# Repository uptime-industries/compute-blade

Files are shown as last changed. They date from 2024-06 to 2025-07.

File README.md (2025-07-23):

# Compute Blade

A On-Premise Cluster Environment

Feature rich, enterprise-level, carrier board for the Raspberry Pi Compute Module 4 (+ compatible alternatives). From Homelabs to advanced AI clusters at scale: Simplifying and automating the development and management of on-premise cluster environments is at the heart of what we do. Our solutions are designed to streamline complex processes, turning what was once a daunting task into a manageable and efficient experience.

## Links

- [Website](https://computeblade.com/)
- [Documentation](https://docs.computeblade.com)
- [Discord Community](https://discord.com/invite/uptime-industries-952334175501946902)

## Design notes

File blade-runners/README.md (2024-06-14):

# Blade Runners
Offial enclosure for the [Compute Blade](https://computeblade.com/). Offing flex able options to fit a number of uses cases. With three options

## Twin
Twin Enclosure allows two Compute Blades and one Fan Unit to be installed. It is ideal for desktop and devlopment

## Home
Home enclosure is our recomened enclosure for Homelab and cluster devlopment. Caplible of holding four Compute Blades and two Fan Units, it is ideal for quick spinning up a deveolpment envierment

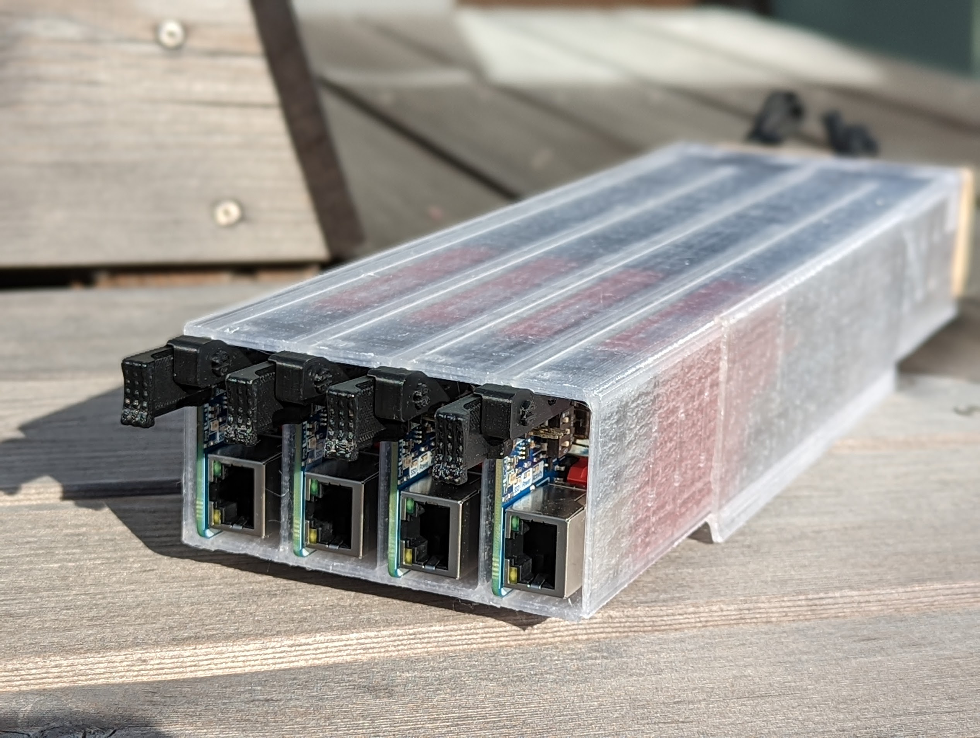
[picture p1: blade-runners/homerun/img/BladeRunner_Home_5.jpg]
Blade Runner Home


## 19-Inch
The 19-Inch enclosure is for enterprise scale. Can be equipt with twenty Compute Blades and ten Fan Units. Offering high desity compute in a Standered 1U of rack space.

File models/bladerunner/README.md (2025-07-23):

# BladeRunner™️
Offial enclosure for the [Compute Blade](https://computeblade.com/). Offing flex able options to fit a number of uses cases. With three options

## 2-Node
2-Node Enclosure allows two Compute Blades and one Fan Unit to be installed. It is ideal for desktop and development

## 4-Node
4-Node enclosure is our recommend enclosure for Homelab and cluster development. Can house four Compute Blades and two Fan Units, it is ideal for quick spinning up a development environment

BladeRunner™️ Home

## 19-Inch
The 19-Inch enclosure is for enterprise scale. Can be equipped with twenty Compute Blades and ten Fan Units. Offering high density compute in a Standard 1U of rack space.

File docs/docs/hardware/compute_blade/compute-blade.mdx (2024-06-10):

---
sidebar_position: 1
---
import Tabs from '@theme/Tabs';
import TabItem from '@theme/TabItem';

# Compute Blade

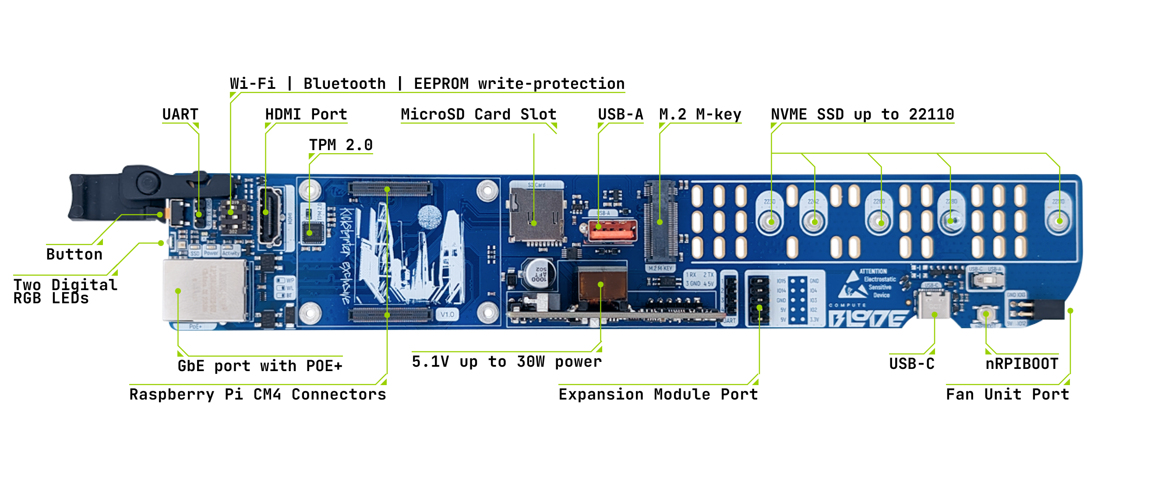
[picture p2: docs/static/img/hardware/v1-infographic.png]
Infographic


---
## Compute Blade Models
The Compute Blade comes in three haredware teirs.

| Feature |  Basic | TPM  |  Dev |
| :--- | :---: | :----: | :----: |
| CM4 Port | ✅ | ✅ | ✅ |
| M.2 Slot M Key up to 2210 | ✅ | ✅ | ✅ |
| Gigabit Ethernet | ✅ | ✅ | ✅ |
| PoE++ support | ✅ | ✅ | ✅ |
| UART | ✅ | ✅ | ✅ |
| Programable Button | ✅ | ✅ | ✅ |
| Programable LEDs | ✅ | ✅ | ✅ |
| USB-A 2.0 | ❌ | ✅ | ✅ |
| TPM 2.0 | ❌ | ✅ | ✅ |
| HDMI | ❌ | ❌ | ✅ |
| USB-C for Flashing CM4 | ❌ | ❌ | ✅ |
| MicroSD Card | ❌ | ❌ | ✅ |
| Wi-Fi | Locked | Locked | Switchable |
| Bluetooth | Locked | Locked | Switchable |
| Write Protection | Locked | Locked | Switchable |

## Block Scheme
This is the top part of the Raspberry Pi's GPIO connector. On the Compute Blade, PIN 1 corresponds to 3.3V, while on the Raspberry Pi's standard connector, it is labeled as 3.3V PWR.
<Tabs>
    <TabItem value="basic" label="Basic" >
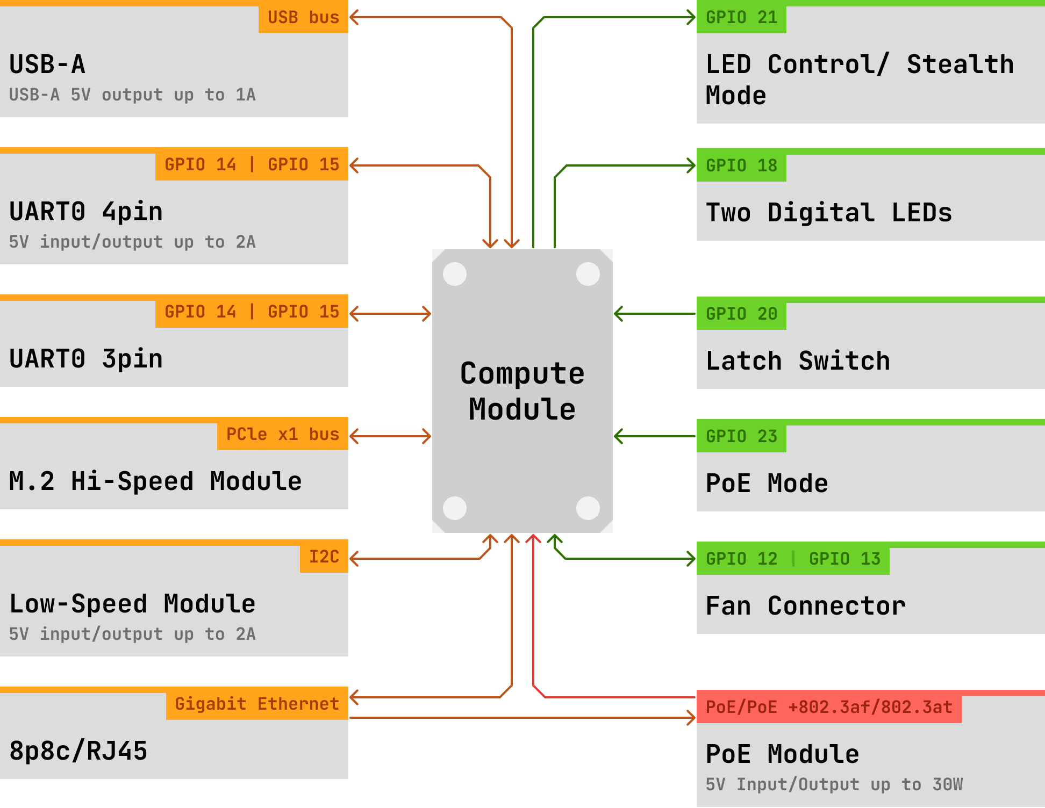
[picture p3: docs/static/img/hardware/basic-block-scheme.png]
Basic Block Scheme
    
    </TabItem>
    <TabItem value="tpm" label="TPM">
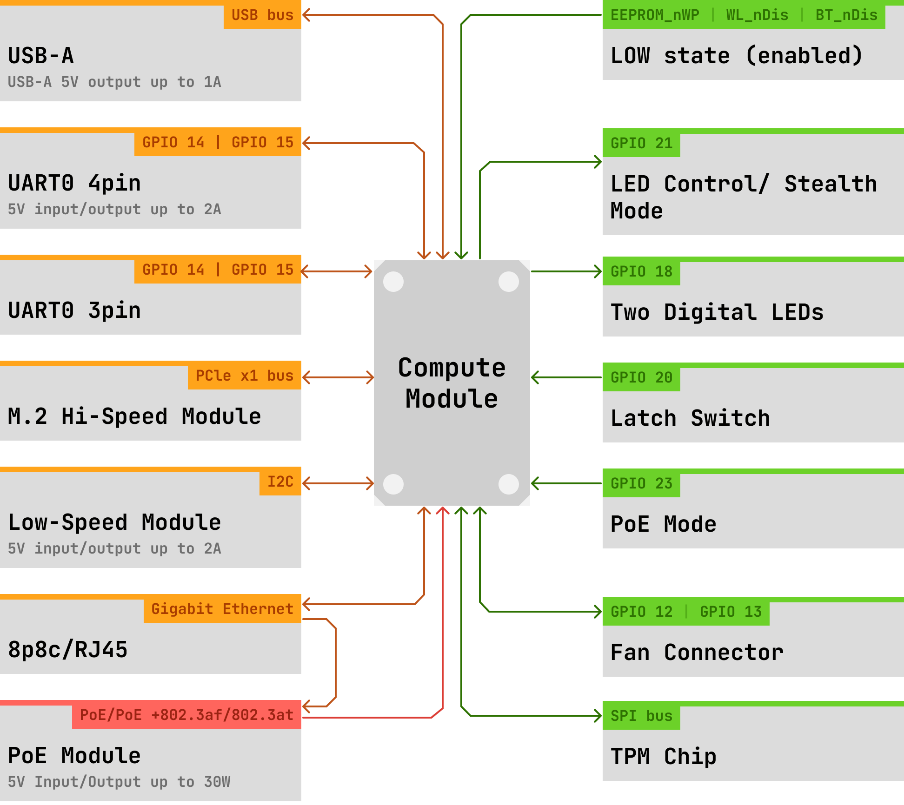
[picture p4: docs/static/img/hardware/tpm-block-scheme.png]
TPM Block Scheme
    
    </TabItem>
    <TabItem value="dev" label="Dev">
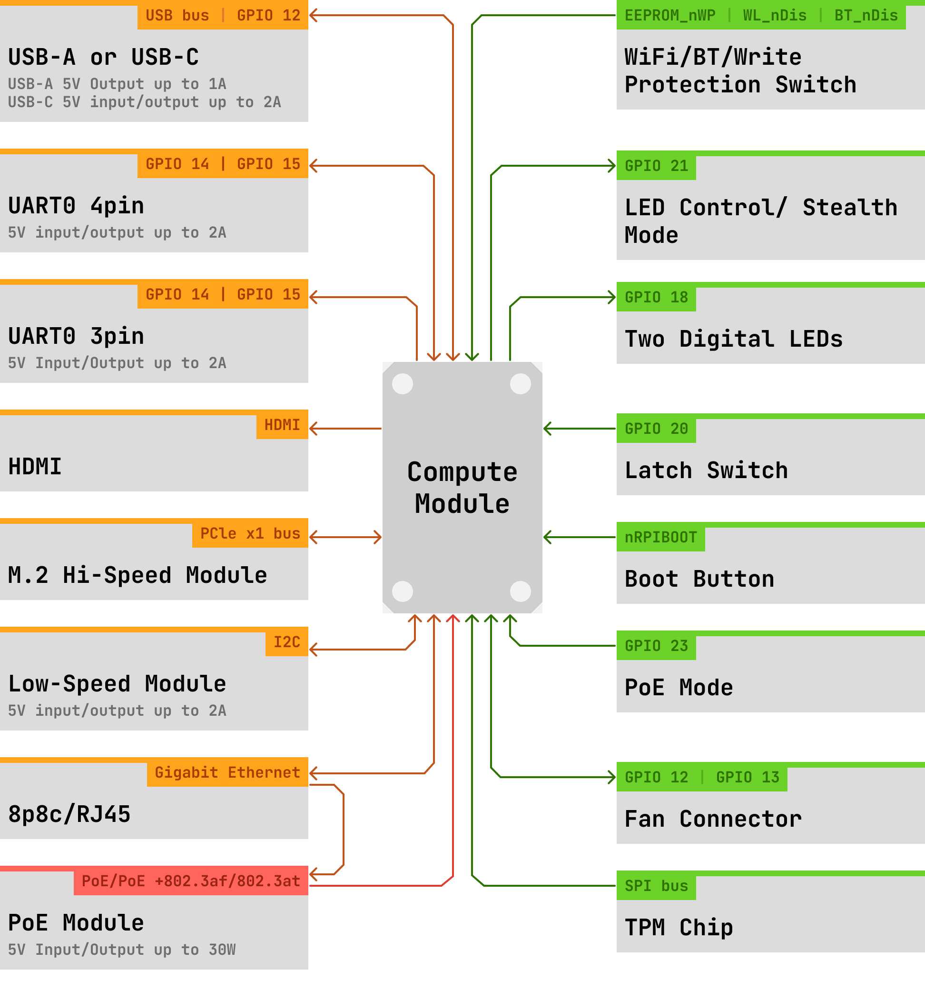
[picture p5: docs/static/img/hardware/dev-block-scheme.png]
Dev Block Scheme
    
    </TabItem>
</Tabs>

## Mechanical
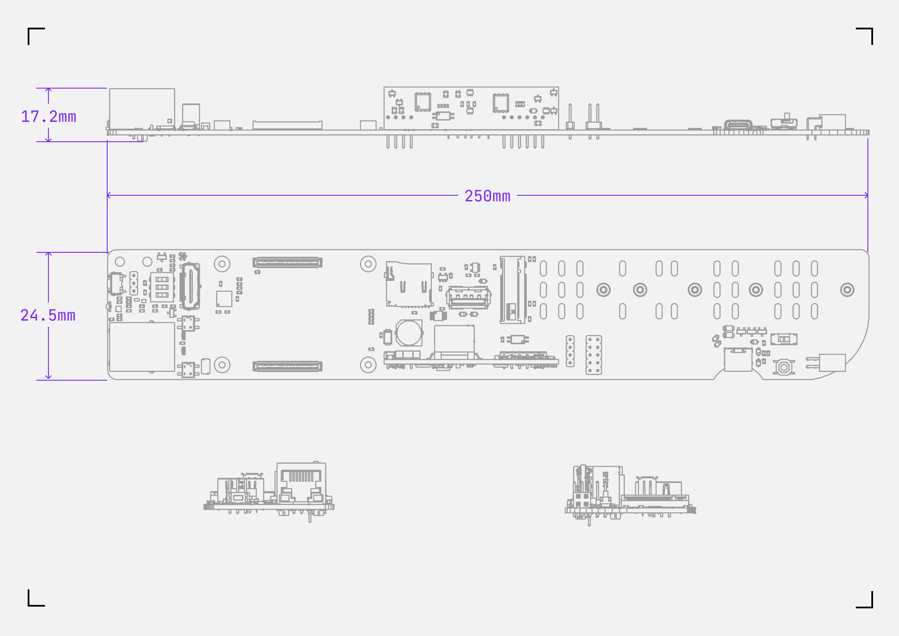
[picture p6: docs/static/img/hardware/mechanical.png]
mechanical

## DIP Switchs
:::danger
Only change switch positions when the Blade is unpluged from power
:::

| Switchs | Left | Right  |
| :--- | :---: | :---: |
| 1 - Write Protection | Disabled | Enabled  |
| 2 - Wi-Fi | Enabled  | Disabled |
| 3 - Bluetooth | Enabled  | Disabled |

:::warning
To enable write protection, changes are required to the bootloader. Follow the steps in the official [documentation](https://www.raspberrypi.com/documentation/computers/compute-module.html#cm4bootloader).
:::
---
# USB-C USB-A Switch
The compute module can only operate one USB port at a time. There is a switch to enable which port you would like to utilize.

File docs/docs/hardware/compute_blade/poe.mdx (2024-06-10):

import Tabs from '@theme/Tabs';
import TabItem from '@theme/TabItem';

# Power over Ethernet

The Compute Blade features a Gigabit Ethernet port that supports IEEE 802.3af (PoE), 802.3at (PoE+), and 802.3bt (PoE++).

## Power Consumption

Power consumption will vary based on load, accessories connected, the power requirements of any devices installed in the M.2 slot.
Durring Testing a Compute Blade with a CM4 overlocked to 2GHz and a consumer NVMe SSD under load consumes ~7W. Normal operation may range from 3W to 17W.

## PoE+ Indicator
The PoE+ Indicator can be used to monitor power supply failures or limit RaspberryPi overclocking, when power is provided via 802.3af only. There is an LED on the Blade with a `+` label indicating the PoE+ power state. Alongside, `GPIO23` can be used to identify the power state.

| LED Color | Description | GPIO 23  | Power |
|---|---|---|---|
| Red | 5 Volt present (PoE or USB-C or 5v direct) | **HIGH** | 12W |
| Orange (Red+Green) | PoE+ (802.3at or 802.3bt) present | **LOW**  | 25W (RC2: 22W) |

### Accessing the PoE+ Status in Software
The `GPIO23` indicates the PoE+ state, these script can e.g. used to detect the status.
<Tabs groupId='code-lang'>
    <TabItem value="python" label="Python" default>

    ```py
    import RPi.GPIO as GPIO
    import time

    POE_INDICATOR_GPIO = 23

    GPIO.setmode(GPIO.BCM)
    GPIO.setup(POE_INDICATOR_GPIO, GPIO.IN, pull_up_down=GPIO.PUD_UP) # PoE indicator

    try:
        button_state = GPIO.input(POE_INDICATOR_GPIO)
        if button_state == False:
            print("Powersource: 802.3at or 802.3bt")
        else:
            print("Powersource: 802.3af or USB-C")
    except:
        GPIO.cleanup()
    ```
    </TabItem>
    <TabItem value="c" label="C" >
    ```c
    #include <stdio.h>
#include <wiringPi.h>

// Define the GPIO pin number for the PoE indicator
#define POE_INDICATOR_GPIO 23

int main(void) {
    // Initialize the wiringPi library
    if (wiringPiSetupGpio() == -1) {
        printf("wiringPi setup failed\n");
        return 1;
    }

    // Set the GPIO pin mode to input
    pinMode(POE_INDICATOR_GPIO, INPUT);

    // Read the state of the GPIO pin
    int poeIndicatorState = digitalRead(POE_INDICATOR_GPIO);

    // Check if the pin is active (assuming active-high logic)
    if (poeIndicatorState == HIGH) {
        printf("Powersource: 802.3af or USB-C\n");
    } else {
        printf("Powersource: 802.3at\n");
    }

    return 0;
}
    ```
    </TabItem>
</Tabs>

## PoE Modules
Different Compute Blade revisions use different PoE modules. See the table below

| Version | PoE Module | Volts | Watts (Peak) | PoE Support | Classification |
|:---|:---|:---|:---|:---|:---|
| v1.0 | [Silvertel Ag5405](https://silvertel.com/ag5400/) | 5V | 25.5W (30W)  | IEEE 802.3af, 802.3at, 802.3bt | Type 2, Class 4 |
| RC2 | [Silvertel Ag5305](https://silvertel.com/ag5300/) | 5V | 20W (22W) | IEEE 802.3af, 802.3at | Type 2, Class 4 |

## Switch Recommendation
A switch that can Supply IEEE 802.3at (PoE+) is recommended as IEEE 802.3af (PoE) may not provide sufficient power for all work loads.

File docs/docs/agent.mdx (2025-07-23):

# Blade Agent

:::warning
    This software is currently in beta, and both configurations and APIs may undergo breaking changes. It is not yet 100% feature complete, but it functions as intended.
:::
The [`computeblade-agent`](https://github.com/Uptime-Lab/computeblade-agent) serves as an operating system agent interfacing with ComputeBlade hardware.
It takes charge of fan speed, LEDs, and manages common events, such as identifying or locating an individual blade in a server rack.
Additionally, it exposes hardware and agent-related metrics on a Prometheus endpoint.

## Installation of Agent

The following commands download and then run our automated installation [script](https://github.com/uptime-lab/compute-blade-agent/blob/main/hack/autoinstall.sh)
```bash
sudo apt update
sudo apt upgrade
curl -L -o /tmp/computeblade-agent-installer.sh https://raw.githubusercontent.com/Uptime-Lab/computeblade-agent/main/hack/autoinstall.sh
chmod +x /tmp/computeblade-agent-installer.sh
/tmp/computeblade-agent-installer.sh
```
## Components
### computeblade-agent
This event-loop handler responds to system events, such as button presses and temperature changes.
It offers a Prometheus endpoint for monitoring core metrics, including Power over Ethernet (PoE) status.

In normal operation mode, the agent maintains static LEDs and fan speed based on the configuration.
If the System on Chip (SoC) temperature exceeds a predefined level the critical mode is activated, setting the fan speed to 100% and changing the LED color to red.
The identify action, independent of the mode, makes the edge LED blink.
This can be toggled using `bladectl` on the blade (`bladectl identify`) or by pressing the edge button (or smart fan unit button).
### Smart Fan Unit Firmware
This firmware controls fan speed and LEDs on the fan unit using a UART-based protocol with agents running on the blades.
It reports metrics (fan RPM and airflow temperature) regularly to the blades and forwards button presses (1x -> left blade, 2x -> right blade).
The fan unit determines the highest requested fan speed, configuring the fan control chip on the board. Advanced functionalities,
such as airflow-based fan curve control, are possible with the EMC2101 chip on the smart fan unit, currently implemented in software on the agent side.

### bladectl - interacting with the agent
`bladectl` interacts with the blade-local API exposed by the computeblade-agent.
For instance, you can identify the blade in a rack using `bladectl identify --wait`,
which blocks and makes the edge LED blink until the button is pressed.

## Configuration
Configuration can be driven by a config file or environment variables.
Linux packages ship with the default configuration in `/etc/computeblade-agent/config.yaml`.
Alternatively, especially for Kubernetes, all parameters in the YAML configuration can be overwritten using environment variables prefixed with BLADE_.

For example, changing the metric address defined in YAML:
```yaml
# Listen configuration
listen:
  metrics: ":9666"
```
can be achieved with the environment variable `BLADE_LISTEN_METRICS=":1234"`.

Some useful parameters:
- `BLADE_STEALTH_MODE=false`: Enables/disables stealth mode.
- `BLADE_FAN_SPEED_PERCENT=80`: Sets static fan speed (by default, there's a linear fan curve of 40-80%).
- `BLADE_CRITICAL_TEMPERATURE_THRESHOLD=60`: Configures the critical temperature threshold of the agent.
- `BLADE_HAL_RPM_REPORTING_STANDARD_FAN_UNIT=false`: Enables/disables fan speed measurement (disabling it reduces CPU load of the agent).

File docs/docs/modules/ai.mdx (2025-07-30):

---
sidebar_position: 2
---

import Tabs from '@theme/Tabs';
import TabItem from '@theme/TabItem';

# AI Module

The AI Module is currently in development and will provide enhanced artificial intelligence capabilities for edge computing applications on the Compute Blade platform.

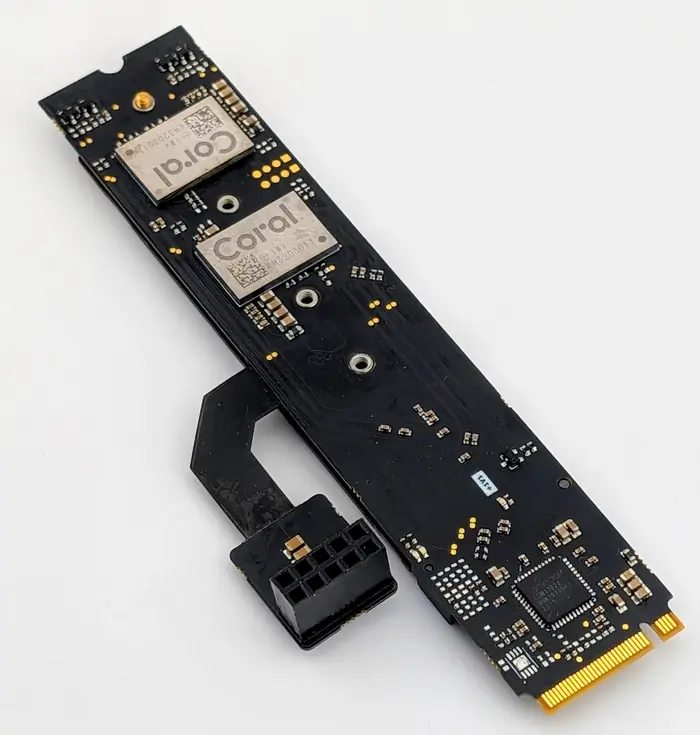
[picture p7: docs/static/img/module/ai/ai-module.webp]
AI module


## Current Status

The AI Module is actively being developed to bring machine learning and artificial intelligence capabilities directly to your Compute Blade setup. This module will enable:

- **Edge AI processing** without cloud dependencies
- **Real-time inference** capabilities
- **Integration** with popular ML frameworks
- **Optimized performance** for Raspberry Pi hardware

## Planned Features

<Tabs groupId="ai-capabilities">
  <TabItem value="inference" label="Inference Engine" default>
    **On-device Model Inference**
    - Support for TensorFlow Lite models
    - ONNX runtime compatibility
    - PyTorch mobile integration
    - Quantized model support for faster processing
  </TabItem>
  <TabItem value="frameworks" label="ML Frameworks">
    **Supported Frameworks**
    - TensorFlow/TensorFlow Lite
    - PyTorch
    - OpenCV for computer vision
    - scikit-learn for classical ML
    - Custom model deployment tools
  </TabItem>
  <TabItem value="hardware" label="Hardware Acceleration">
    **Performance Optimization**
    - GPU acceleration where available
    - Multi-core CPU utilization
    - Memory-efficient model loading
    - Batch processing capabilities
  </TabItem>
</Tabs>

## Use Cases

### Computer Vision
- **Object detection** and classification
- **Facial recognition** systems
- **Quality control** in manufacturing
- **Security monitoring** applications

### Natural Language Processing
- **Text classification** and sentiment analysis
- **Language translation** for IoT devices
- **Voice command** processing
- **Chatbot** deployment at the edge

### Predictive Analytics
- **Sensor data** analysis
- **Predictive maintenance** for industrial equipment
- **Anomaly detection** in real-time
- **Time series forecasting**

## Development Roadmap

- **Phase 1**: Core inference engine development
- **Phase 2**: Framework integration and testing
- **Phase 3**: Hardware optimization and acceleration
- **Phase 4**: Documentation and example projects
- **Phase 5**: Community beta testing

## Stay Updated

Check back for updates on the AI Module development progress and availability. Follow our [GitHub repository](https://github.com/uptime-lab) for the latest developments and early access opportunities.

:::info Coming Soon
The AI Module is expected to be available in Q3 2025. Early access will be provided to beta testers and community contributors.
:::

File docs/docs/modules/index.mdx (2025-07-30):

---
sidebar_position: 1
---

# Modules Overview

The Compute Blade ecosystem supports various modules that can enhance the functionality of your Raspberry Pi projects. These modules are designed to work seamlessly with the Compute Blade hardware and provide additional capabilities for different use cases.

## Available Modules

### Real Time Clock (RTC)

Real Time Clock modules help maintain accurate time tracking even when your Compute Blade is powered off. These modules use I2C communication and are essential for applications that require precise time synchronization.

[Learn more about RTC modules →](modules/rtc)

### AI Module

The AI Module is currently in development and will provide enhanced artificial intelligence capabilities for edge computing applications on the Compute Blade platform.

[Learn more about the AI Module →](modules/ai)

### Security Modules

For applications requiring additional security features, various security modules can be integrated with the Compute Blade. These modules provide hardware-based security and encryption capabilities.

[Learn more about security modules →](modules/zimkey4)

## Getting Started

When connecting any module to your Compute Blade, be sure to:

1. Consult the pinout guide on your Compute Blade
2. Reference the module's datasheet for correct wiring
3. Follow the specific setup instructions for each module
4. Test the module functionality before deploying

Each module page contains detailed information about compatibility, installation, and configuration specific to that module type.

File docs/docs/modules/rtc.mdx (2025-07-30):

---
sidebar_position: 3
---

import Tabs from '@theme/Tabs';
import TabItem from '@theme/TabItem';

# Real Time Clock

There are several Real Time Clock (RTC) modules available for the Raspberry Pi, which can be used to keep track of the current time even when the Pi is powered off. These modules typically use I2C communication and can be easily integrated into your projects.

Be sure when connecting a RTC module to use the pinout guide on your compute blade along with the pinout from the RTC modules data sheet to ensure correct wiring.

## Available RTC Modules

### Popular Options

<Tabs groupId="rtc-modules">
  <TabItem value="adafruit" label="Adafruit PiRTC" default>
    The [Adafruit PiRTC](https://www.adafruit.com/product/3386) is a reliable and well-documented RTC module.
    
    **Features:**
    - Built-in battery backup
    - Easy I2C interface
    - Compatible with all Raspberry Pi models
    - Excellent documentation and support
  </TabItem>
  <TabItem value="ds3231" label="DS3231 Module">
    The [DS3231 Real Time Clock Module](https://www.pishop.us/product/ds3231-real-time-clock-module-for-raspberry-pi/) from PiShop.us offers high accuracy.
    
    **Features:**
    - Temperature-compensated crystal oscillator
    - ±2ppm accuracy from 0°C to +40°C
    - Built-in 32.768kHz oscillator
    - Battery-backed SRAM
  </TabItem>
  <TabItem value="ds1307" label="DS1307 Module">
    The [DS1307 RTC for Raspberry Pi](https://wiki.seeedstudio.com/Pi_RTC-DS1307/) from Seeed Studio is a cost-effective option.
    
    **Features:**
    - Low-cost solution
    - 56-byte battery-backed RAM
    - Programmable square-wave output
    - Automatic leap year compensation
  </TabItem>
</Tabs>

## Installation

### Hardware Setup

1. **Power down** your Compute Blade before connecting any modules
2. **Connect the RTC module** to your Compute Blade using I2C pins:
   - VCC → 3.3V or 5V (check your module's requirements)
   - GND → Ground
   - SDA → GPIO2 (Pin 3)
   - SCL → GPIO3 (Pin 5)
3. **Insert the backup battery** (usually CR2032) into the RTC module

### Software Configuration

<Tabs groupId="installation-method">
  <TabItem value="auto" label="Automatic Setup" default>
    ```bash
    # Enable I2C interface
    sudo raspi-config
    # Navigate to: Interfacing Options > I2C > Enable
    
    # Reboot to apply changes
    sudo reboot
    
    # Install I2C tools
    sudo apt update
    sudo apt install i2c-tools
    
    # Detect the RTC module
    sudo i2cdetect -y 1
    ```
  </TabItem>
  <TabItem value="manual" label="Manual Configuration">
    ```bash
    # Edit the boot config
    sudo nano /boot/config.txt
    
    # Add the following line (adjust for your RTC chip):
    dtoverlay=i2c-rtc,ds3231
    # or for DS1307: dtoverlay=i2c-rtc,ds1307
    
    # Save and reboot
    sudo reboot
    
    # Remove fake hardware clock
    sudo apt-get -y remove fake-hwclock
    sudo update-rc.d -f fake-hwclock remove
    ```
  </TabItem>
</Tabs>

### Testing Your RTC

```bash
# Check if RTC is detected
sudo hwclock -D -r

# Set system time to RTC
sudo hwclock -w

# Read time from RTC
sudo hwclock -r
```

## Benefits

- **Persistent timekeeping**: Maintains accurate time when the system is powered off
- **Low power consumption**: Uses minimal power from backup battery
- **Easy integration**: Standard I2C interface works with existing projects
- **Essential for logging**: Critical for applications requiring accurate timestamps
- **Network independence**: No need for NTP when network is unavailable

## Troubleshooting

### Common Issues

- **Module not detected**: Check wiring connections and I2C enable status
- **Time drift**: Ensure backup battery is properly installed and charged
- **Boot issues**: Verify correct device tree overlay for your RTC chip

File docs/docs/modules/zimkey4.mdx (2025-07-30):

---
sidebar_position: 4
---

import Tabs from '@theme/Tabs';
import TabItem from '@theme/TabItem';

# Security Modules

For applications requiring additional security features, various security modules can be integrated with the Compute Blade. These modules provide hardware-based security and encryption capabilities.

## ZYMKEY4 for Raspberry Pi

The [ZYMKEY4 for RPI](https://www.zymbit.com/ZYMKEY/) is a hardware security module that can be used to add enhanced security to your Compute Blade setup.

### Features

<Tabs groupId="zymkey-features">
  <TabItem value="security" label="Security Features" default>
    **Hardware Security**
    - Hardware-based encryption and authentication
    - Secure key generation and storage
    - Tamper detection and response
    - True random number generation
    - Secure boot capabilities
  </TabItem>
  <TabItem value="crypto" label="Cryptographic Functions">
    **Encryption & Authentication**
    - AES-256 encryption
    - ECDSA digital signatures
    - SHA-256 hashing
    - Key derivation functions
    - Certificate management
  </TabItem>
  <TabItem value="additional" label="Additional Features">
    **Extra Capabilities**
    - Digital wallet functionality
    - Real-time clock with battery backup
    - GPIO expansion
    - LED status indicators
    - Developer API access
  </TabItem>
</Tabs>

### Installation

<Tabs groupId="installation-steps">
  <TabItem value="hardware" label="Hardware Setup" default>
    **Physical Installation**
    1. Power down your Compute Blade completely
    2. Locate the GPIO header on your Compute Blade
    3. Align the ZYMKEY4 with pins 1-10 of the GPIO header
    4. Press down firmly to ensure good connection
    5. The ZYMKEY4 LED should illuminate when powered on
  </TabItem>
  <TabItem value="software" label="Software Installation">
    **Software Configuration**
    ```bash
    # Download and run the installer
    curl -G https://s3.amazonaws.com/zk-sw-repo/install_zk_sw.sh | sudo bash
    
    # Reboot to complete installation
    sudo reboot
    
    # Test the installation
    zkifc --slot-info
    ```
  </TabItem>
  <TabItem value="config" label="Configuration">
    **Initial Configuration**
    ```bash
    # Initialize the ZYMKEY4
    sudo zkifc --lock
    
    # Generate a test key pair
    zkifc --gen-key-pair --key-name test_key
    
    # Verify functionality
    zkifc --get-public-key --key-name test_key
    ```
  </TabItem>
</Tabs>

### Programming Examples

<Tabs groupId="programming-examples">
  <TabItem value="python" label="Python" default>
    ```python
    import zymkey
    
    # Generate a key pair
    zymkey.client.gen_key_pair('my_keypair')
    
    # Sign some data
    message = "Hello, secure world!"
    signature = zymkey.client.sign(message, 'my_keypair')
    
    # Verify the signature
    is_valid = zymkey.client.verify(message, signature, 'my_keypair')
    print(f"Signature valid: {is_valid}")
    ```
  </TabItem>
  <TabItem value="nodejs" label="Node.js">
    ```javascript
    const zymkey = require('zymkey-js');
    
    // Initialize the client
    const client = new zymkey.Client();
    
    // Encrypt some data
    const plaintext = "Sensitive information";
    const encrypted = client.encrypt(plaintext);
    
    // Decrypt the data
    const decrypted = client.decrypt(encrypted);
    console.log("Decrypted:", decrypted);
    ```
  </TabItem>
  <TabItem value="cli" label="Command Line">
    ```bash
    # Create encrypted file
    echo "Secret data" | zkifc --encrypt --output secret.enc
    
    # Decrypt the file
    zkifc --decrypt --input secret.enc
    
    # Sign a file
    zkifc --sign --input document.txt --key-name signing_key
    ```
  </TabItem>
</Tabs>

### Use Cases

#### IoT Security
- **Device authentication** in IoT networks
- **Secure firmware updates** over-the-air
- **Data encryption** for sensor readings
- **Network security** for edge devices

#### Industrial Applications
- **Equipment authentication** in manufacturing
- **Secure data logging** for compliance
- **Access control** for industrial systems
- **Supply chain verification**

#### Financial & Healthcare
- **Payment processing** at point-of-sale
- **Patient data protection** in medical devices
- **Compliance** with HIPAA, PCI-DSS standards
- **Audit trail** generation and verification

### Troubleshooting

**Common Issues:**
- **LED not lighting**: Check GPIO connection and power supply
- **Software installation fails**: Ensure internet connection and run as sudo
- **Key generation errors**: Verify ZYMKEY4 is properly locked and initialized
- **Performance issues**: Check for conflicting GPIO usage

**Support Resources:**
- [Zymbit Documentation](https://docs.zymbit.com/)
- [Community Forum](https://community.zymbit.com/)
- [GitHub Examples](https://github.com/Zymbit-Wallet)

:::warning Security Notice
Always follow proper security practices when handling cryptographic keys and sensitive data. The ZYMKEY4 provides hardware-level security, but proper implementation and key management are essential.
:::

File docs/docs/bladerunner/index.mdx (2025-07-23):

---
sidebar_position: 1
---

# Overview

The BladeRunner™️ are optimized for heat distribution and airflow, utilizing the least possible space to scale the Compute Blade cluster.
Engineered to scale and offer the greatest flexibility without the need to spend any thought on complex cooling or powering

3D Models for all three Blade Enclosures can be found on our [GitHub](https://github.com/uptime-lab/compute-blade/tree/main/bladerunner).

[Datasheet](/datasheet/BladeRunner_datasheet_v.1.0.pdf) (PDF)

## Models

- [19-inch 1U Rack](/bladerunner/19inch) - 19" Rack enclosure for up to 20 Compute Blades 
- [4-node](/bladerunner/4node) - Ideal enclosure for Homelab or cluster development containing up to 4 Compute Blades
- [2-node](/bladerunner/2node) - Small enclosure for up to 2 Compute Blades

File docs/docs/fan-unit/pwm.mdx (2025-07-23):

import Tabs from '@theme/Tabs';
import TabItem from '@theme/TabItem';

# Standard

The Standard Fan Unit offers an easy out-of-box experience. The fan will run with no additional setup, however, you may control the fan via PWM. 

## Pins

The Compute blade uses [`GPIO12`](https://pinout.xyz/pinout/pin32_gpio12/) and [`GPIO13`](https://pinout.xyz/pinout/pin33_gpio13/) in their alternate PWM mode.

:::info
Only the Compute Blade connected to `Port A` of the Fan Unit can control the fan speed. However both blades can read the speed of the fan.
:::

<details>
  <summary>Pin Out Guides</summary>
  <h3>Standard Fan Unit</h3>
  Standard Fan Unit blade connecter pin out
  <h3>Fan Header</h3>
  

</details>

## Python

A simple Python script can control the PWM fan.

### Setup

Start by cloning the scripts from the [GitHub repository](https://github.com/uptime-lab/compute-blade-pwm-fan-control)
```bash
git clone https://github.com/uptime-lab/compute-blade-pwm-fan-control.git
cd ./compute-blade-pwm-fan-control/
```

Install [GPIO Zero](https://gpiozero.readthedocs.io/en/latest/index.html), a simple interface to GPIO devices for Raspberry Pi
<Tabs groupId='installer'>
    <TabItem value="apt" label="apt" default>
        ```bash
        sudo apt install python3-gpiozero
        ```
    </TabItem>
    <TabItem value="pip" label="pip" default>
        ```bash
        sudo pip3 install gpiozero
        ```
    </TabItem>
</Tabs>

The Github repo provides two scripts:
- `read_fan_speed.py` - Prints the current fan Speed in RPM
- `fan_control.py`    - Controls fan speed based on CPU temperature
Either script can be stopped at any time with `CTRL` + `C`

### read_fan_speed.py
To use the `read_fan_speed.py` script run the following command:
```bash
python3 read_fan_speed.py
```

### fan_control.py
To control the fan speed:
```bash
python3 fan_control.py
```

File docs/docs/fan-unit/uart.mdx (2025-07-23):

import Admonition from '@theme/Admonition';

# Smart

The Smart Fan unit utilizes the [RP2040](https://www.raspberrypi.com/products/rp2040/specifications/) microcontroller featured in the [Raspberry Pi Pico 1](https://www.raspberrypi.com/documentation/microcontrollers/pico-series.html). Using the RP2040's two UART connections, a link can be established to each blade using the fan connectors.

## Hardware

### Power Delivery
The Smart Fan Unit can be powered with +5V from both Blade `Port A` or `Port B` In addition to the USB Type-C for flashing. USB Type-C with not power the fan

### LEDs

The Smart Fan Unit has 5 LEDs

| LED  | Location | Type |
| ---- | --- | --- |
| LED1 | Yellow | Programmable NeoPixel at index `0` |
| LED2 | Yellow | Programmable NeoPixel at index `1` |
| LED3 | Red | Green Programmable at `GPIO25` |
| LED4 | Green | Blue Power indicator for `Port A`  |
| LED5 | Green | Blue Power indicator for `Port B`  |
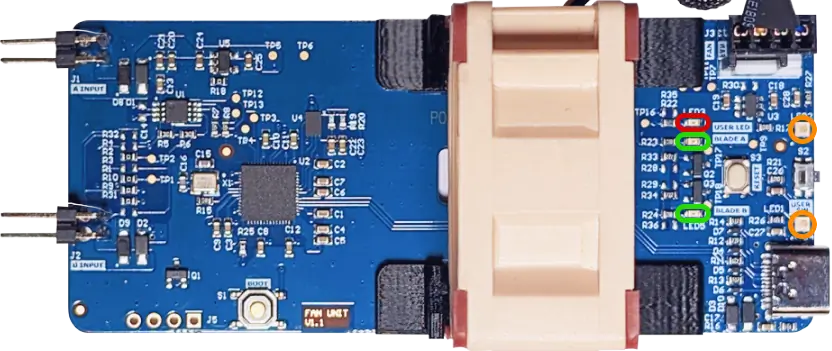
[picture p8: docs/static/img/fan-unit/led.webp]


### Button

A programmable button is located on on the rear of the Smart Fan Unit. It can be addressed at `GPIO12`

### Fan control

The Smart Fan Unit uses the [EMC2101](https://www.microchip.com/en-us/product/emc2101) from Microchip/SMSC a fan controller with temperature monitoring. The EMC2101 is connected over the I2C bus to the RP2040

The EMC2101 has two temperature sensors. An internal sensors on the IC(Red) located next to Port A and an external sensors(Green) located next to Port B

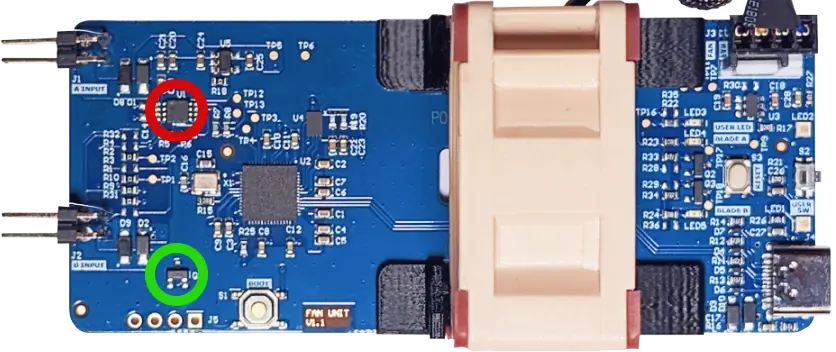
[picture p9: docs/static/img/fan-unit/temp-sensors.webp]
Blade Fan unit connector


### Additional information
<details>
  <summary>Pin Out Guides</summary>
  <h3>Smart Fan Unit</h3>
  Smart Fan Unit blade connecter pin out
  <h3>Fan Header</h3>
  
  <h3>J5 Debug Header</h3>
  
  
</details>

<details>
  <summary>RP2040 Pin Reference Table</summary>

  Pins used by the Smart Fan Unit

  | Pins(RP2040) | Functions         |
  |:------------:|:-----------------:|
  | GPIO1        | UART0 RX          |
  | GPIO2        | UART0 TX          |
  | GPIO4        | I2C-SDA           |
  | GPIO5        | I2C-SCL           |
  | GPIO8        | UART1 TX          |
  | GPIO9        | UART1 RX          |
  | GPIO12       | Button            |
  | GPIO15       | Two NeoPixel LEDs |
  | GPIO16       | Power to Fan      |
  | GPIO25       | LED3              |
</details>

## Update Firmware

To start using the Smart Fan Unit, it should first be flashed with the latest firmware of your choice. This could be any custom firmware, or a pre-existing framework.

First, start by removing power from the Fan Unit. Then hold down the `BOOT` button and connect the USB Type-C to your computer.

{/* Image of fan unit with Boot held down and usb plugged in */}

The Fan Unit will now appear as a storage device labelled `RPI-RP2` on your computer.

{/* Windows file manager this PC */}

The firmware you are flashing should have the file extension `.uf2`
Move the `*.uf2` file into `RPI-RP2`, it should disconnect after a few seconds and reboot to the newly installed firmware.

## CircuitPython

We have prepared [example code](https://github.com/uptime-lab/circuitpy-fan-unit) to help you get started with your Smart Fan unit. Using [CircuitPython](https://circuitpython.org/) which is a programming language designed to simplify experimenting and learning to code on low-cost microcontroller boards.

The code has the following basic functionality example :
- Button use
- LED control both Green and NeoPixel
- Fan control based on a simple fan curve
- UART communication

<details>
  <summary>Fan Curve Reference Table</summary>

  Fan Curve used in example code

  | Temp Range         | Present Fan Speed |
  | :----------------: | :---------------: |
  | t >= 40C           | 100%              |
  | 35C {"<="} t < 40C | 70%               |
  | 33C {"<="} t < 35C | 60%               |
  | 31C {"<="} t < 33C | 40%               |
  | 29C {"<="} t < 31C | 30%               |
  | 29C < t            | 10%               |
</details>

### Installing CircuitPython
1. Download the latest version of [CircuitPython 9](https://circuitpython.org/board/raspberry_pi_pico/)
2. With the Compute Blade connected from prior firmware flashing steps, move `adafruit-circuitpython-raspberry_pi_pico-en_US-*.uf2` file into the `RPI-RP2` storage device
4. It will be disconnected and `LED 3` will blink green
3. The fan Unit with reconnect as `CIRCUITPY` will be connected

### Deploying Code example

1. Having installed `CircuitPython` and connecting the fan unit to your computer via USB-C
2. Download the [example code](https://github.com/uptime-lab/circuitpy-fan-unit) from GitHub
3. The code should be placed in `CIRCUITPY`; if prompted to replace any files, click yes

## Enable UART on CM4

To enable UART on the compute blade, open `/boot/firmware/config.txt`

```bash 
sudo nano /boot/firmware/config.txt
```

<Admonition type='info'>
    Instead of the BIOS found on a conventional PC, Raspberry Pi devices use a configuration file called config.txt. The GPU reads config.txt before the ARM CPU and Linux are initialized. Raspberry Pi OS looks for this file in the boot partition, located at `/boot/firmware/`.

    <sub>learn more about `config.txt` in [Raspberry Pi Documentation](https://www.raspberrypi.com/documentation/computers/config_txt.html)</sub>
</Admonition>

Then add the following lines:

```txt
[cm4]
enable_uart=1
dtoverlay=uart5
```

Reboot the the Compute Blade. When it has restarted, the UART connection will be available at `/dev/ttyAMA5`

## Debugging

There is an unpopulated pin header labelled `J5` located below the B port on the Fan Unit.

<details>
  <summary>Debug pins</summary>
  J5 Debug pins
</details>

These debug pins can be used with a tool like the [Raspberry Pi Debug Probe](https://www.raspberrypi.com/documentation/microcontrollers/debug-probe.html) to debug and program the RP2040.

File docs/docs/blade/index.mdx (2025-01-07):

---
sidebar_position: 1
pagination_next: blade/getting-started/assembly
---

import Tabs from '@theme/Tabs';
import TabItem from '@theme/TabItem';
import useBaseUrl from '@docusaurus/useBaseUrl';
import ThemedImage from '@theme/ThemedImage';

# Overview

<ThemedImage
    alt="Dev MK4 Compute Blade with part description"
    sources= {{
        light: useBaseUrl('/img/blade/schematics-white-bg.svg'),
        dark: useBaseUrl('/img/blade/schematics-black-bg.svg'),
    }}
    width={"100%"}
/>

Download the [Datasheet](/datasheet/ComputeBlade_datasheet_v.1.1.pdf)

##  Features and Specifications
The Compute Blade comes in three different hardware variants.
<Tabs groupId="model" defaultValue="dev">
    <TabItem value="dev" label="DEV">
        <h2>Dev Compute Blade</h2>
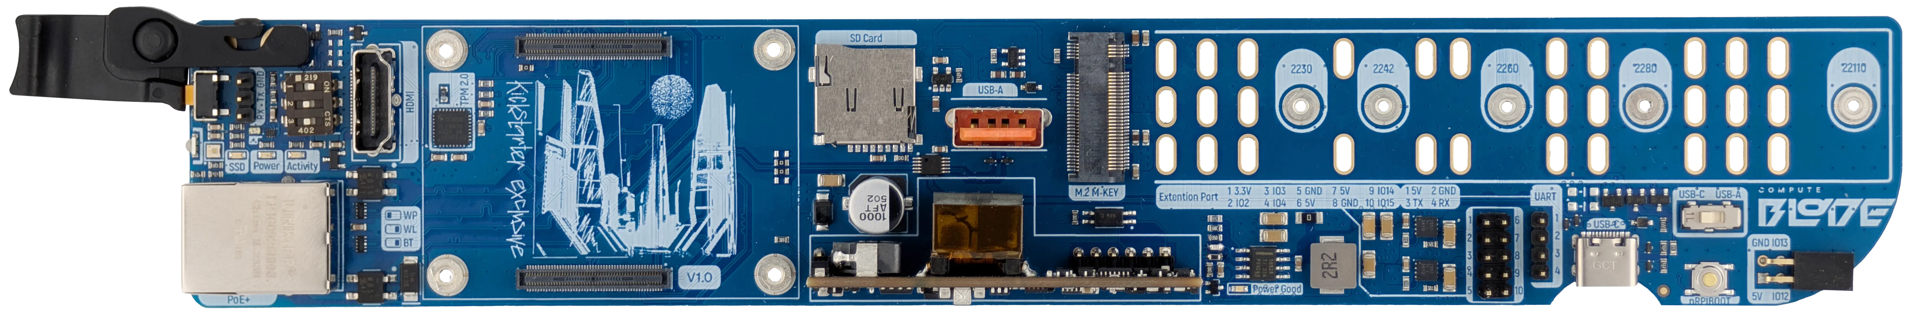
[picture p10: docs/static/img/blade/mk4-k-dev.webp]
MK4-k Dev Blade
        
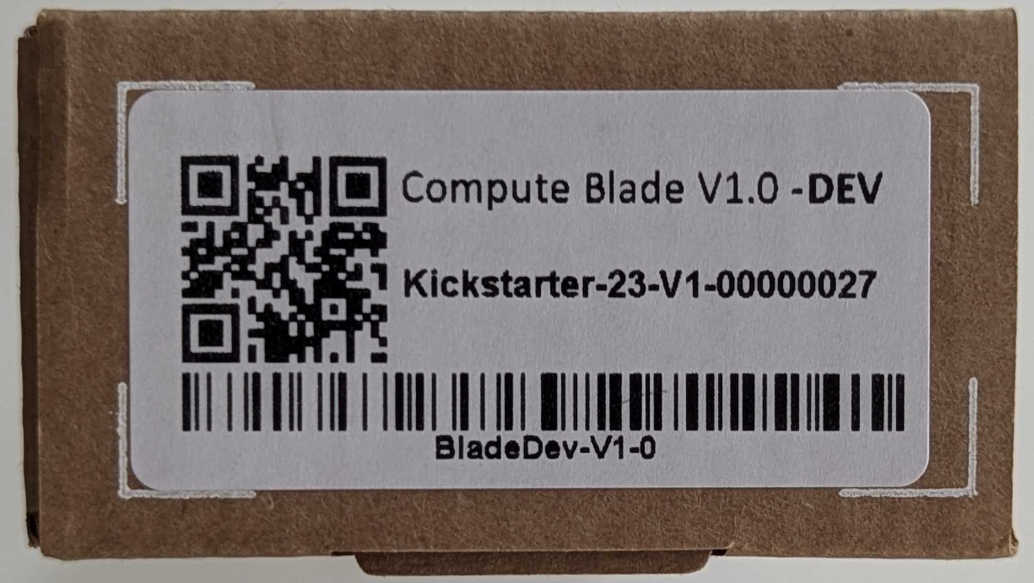
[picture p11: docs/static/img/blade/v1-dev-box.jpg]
v1.0 Dev box label
        
        <table>
            <tbody>
                <tr>
                    <td rowSpan={2}>Compatibility</td>
                    <td>Raspberry Pi Compute Module 4 / 4 Lite</td>
                </tr>
                <tr>
                    <td>Raspberry Pi Compute Module 4 Compatible Boards</td>
                </tr>
                <tr>
                    <td rowSpan={3}>Storage</td>
                    <td>M.2 NVMe SSD up to 22110</td>
                </tr>
                <tr>
                    <td>Micro SD Card on lite CM4 / CM5</td>
                </tr>
                <tr>
                    <td>eMMC on non-lite CM4 / CM5</td>
                </tr>
                <tr>
                    <td rowSpan={5}>GPIO</td>
                    <td>2 x UART</td>
                </tr>
                <tr>
                    <td>7 x User Controllable GPIO including I2C</td>
                </tr>
                <tr>
                    <td>Fan Unit Connector</td>
                </tr>
                <tr>
                    <td>Programmable Button</td>
                </tr>
                <tr>
                    <td>2 x Controllable RGB LEDs</td>
                </tr>
                <tr>
                    <td>[PoE+](https://standards.ieee.org/ieee/802.3at/4553/) Voltage</td>
                    <td>40V-57V</td>
                </tr>
                <tr>
                    <td>PoE+ Current</td>
                    <td>60 mA - 600 mA</td>
                </tr>
                <tr>
                    <td>3.3V Output</td>
                    <td>5A</td>
                </tr>
                <tr>
                    <td>5V Output</td>
                    <td>5.1A</td>
                </tr>
                <tr>
                    <td>Input Power (Normal Operation)</td>
                    <td>2 - 8W</td>
                </tr>
                <tr>
                    <td rowSpan={2}>Ports</td>
                    <td>HDMI (4K60)</td>
                </tr>
                <tr>
                    <td>USB Type-A/Type-C</td>
                </tr>
                <tr>
                    <td rowSpan={3}>Security</td>
                    <td>TPM 2.0</td>
                </tr>
                <tr>
                    <td>Hardware switchable Wi-Fi, Bluetooth and EEPROM write-protection</td>
                </tr>
                <tr>
                    <td>Support for ZYMKEY 4i, Security Keys</td>
                </tr>
            </tbody>
        </table>
    </TabItem>
    <TabItem value="tpm" label="TPM">
        <h2>TPM Compute Blade</h2>
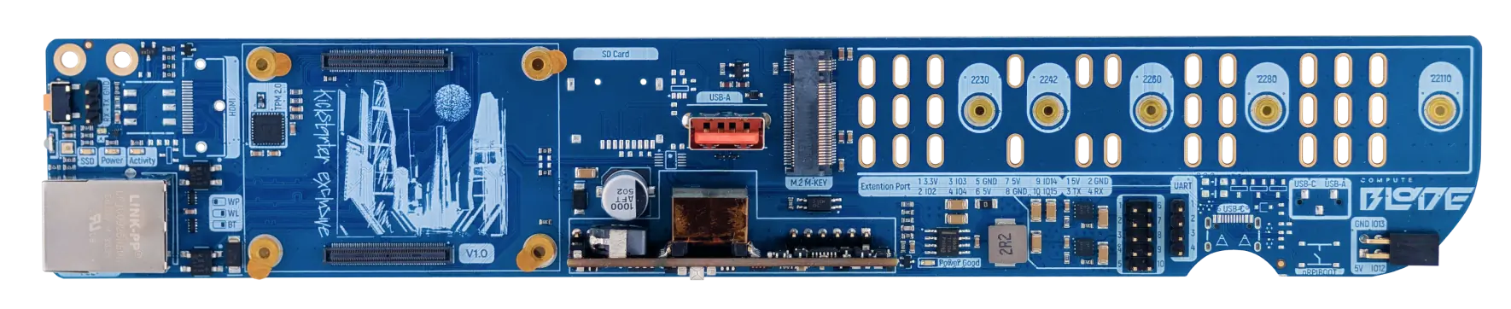
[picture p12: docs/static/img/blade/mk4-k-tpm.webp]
MK4-k TPM Blade
        
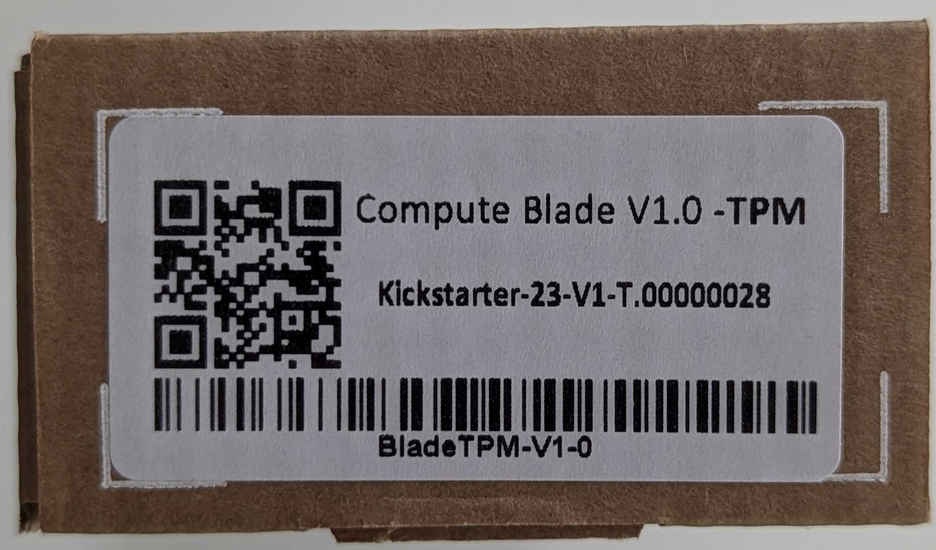
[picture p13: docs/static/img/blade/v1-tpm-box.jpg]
v1.0 TPM box label
        

        <table>
            <tbody>
                <tr>
                    <td rowSpan={2}>Compatibility</td>
                    <td>Raspberry Pi Compute Module 4 / 4 Lite</td>
                </tr>
                <tr>
                    <td>Raspberry Pi Compute Module 4 Compatible Boards</td>
                </tr>
                <tr>
                    <td rowSpan={3}>Storage</td>
                    <td>M.2 NVMe SSD up to 22110</td>
                </tr>
                <tr>
                    <td>Micro SD Card on lite CM4 / CM5</td>
                </tr>
                <tr>
                    <td>eMMC on non-lite CM4 / CM5</td>
                </tr>
                <tr>
                    <td rowSpan={5}>GPIO</td>
                    <td>2 x UART</td>
                </tr>
                <tr>
                    <td>7 x User Controllable GPIO including I2C</td>
                </tr>
                <tr>
                    <td>Fan Unit Connector</td>
                </tr>
                <tr>
                    <td>Programmable Button</td>
                </tr>
                <tr>
                    <td>2 x Controllable RGB LEDs</td>
                </tr>
                <tr>
                    <td>[PoE+](https://standards.ieee.org/ieee/802.3at/4553/) Voltage</td>
                    <td>40V-57V</td>
                </tr>
                <tr>
                    <td>PoE+ Current</td>
                    <td>60 mA - 600 mA</td>
                </tr>
                <tr>
                    <td>3.3V Output</td>
                    <td>5A</td>
                </tr>
                <tr>
                    <td>5V Output</td>
                    <td>5.1A</td>
                </tr>
                <tr>
                    <td>Input Power (Normal Operation)</td>
                    <td>2 - 8W</td>
                </tr>
                <tr>
                    <td>Ports</td>
                    <td>USB Type-A/Type-C</td>
                </tr>
                <tr>
                    <td rowSpan={2}>Security</td>
                    <td>TPM 2.0</td>
                </tr>
                <tr>
                    <td>Support for ZYMKEY 4i, Security Keys</td>
                </tr>
            </tbody>
        </table>

    </TabItem>
    <TabItem value="basic" label="Basic">
        <h2>Basic Compute Blade</h2>
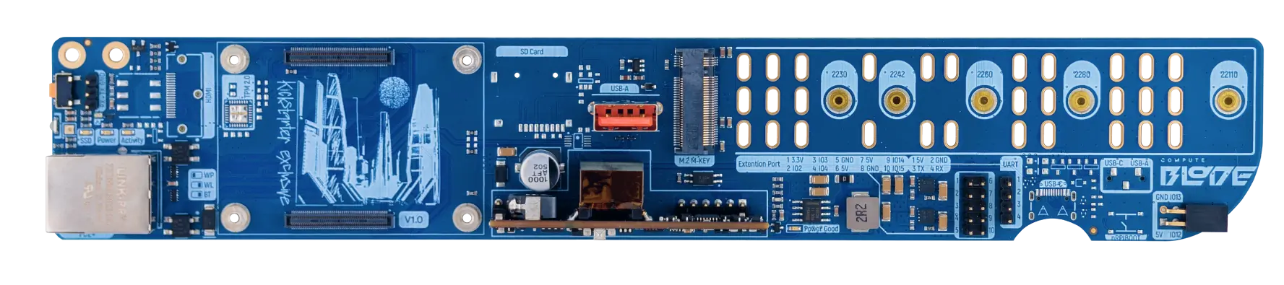
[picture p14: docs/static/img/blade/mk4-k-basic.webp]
MK4-k basic Blade
        
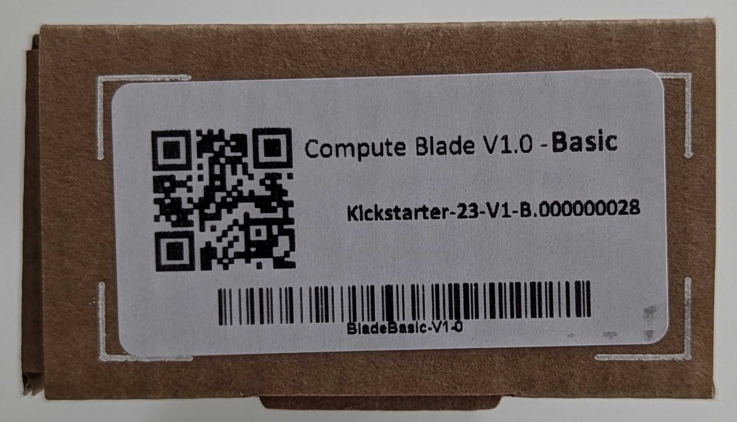
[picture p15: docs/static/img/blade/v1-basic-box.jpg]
v1.0 basic box label
        

        <table>
            <tbody>
                <tr>
                    <td rowSpan={2}>Compatibility</td>
                    <td>Raspberry Pi Compute Module 4 / 4 Lite</td>
                </tr>
                <tr>
                    <td>Raspberry Pi Compute Module 4 Compatible Boards</td>
                </tr>
                <tr>
                    <td rowSpan={3}>Storage</td>
                    <td>M.2 NVMe SSD up to 22110</td>
                </tr>
                <tr>
                    <td>Micro SD Card on lite CM4 / CM5</td>
                </tr>
                <tr>
                    <td>eMMC on non-lite CM4 / CM5</td>
                </tr>
                <tr>
                    <td rowSpan={5}>GPIO</td>
                    <td>2 x UART</td>
                </tr>
                <tr>
                    <td>7 x User Controllable GPIO including I2C</td>
                </tr>
                <tr>
                    <td>Fan Unit Connector</td>
                </tr>
                <tr>
                    <td>Programmable Button</td>
                </tr>
                <tr>
                    <td>2 x Controllable RGB LEDs</td>
                </tr>
                <tr>
                    <td>[PoE+](https://standards.ieee.org/ieee/802.3at/4553/) Voltage</td>
                    <td>40V-57V</td>
                </tr>
                <tr>
                    <td>PoE+ Current</td>
                    <td>60 mA - 600 mA</td>
                </tr>
                <tr>
                    <td>USB Type-C @5V Current</td>
                    <td>2mA - 2A</td>
                </tr>
                <tr>
                    <td>3.3V Output</td>
                    <td>5A</td>
                </tr>
                <tr>
                    <td>5V Output</td>
                    <td>5.1A</td>
                </tr>
                <tr>
                    <td>Power (Normal Operation)</td>
                    <td>2W - 8W</td>
                </tr>
                <tr>
                    <td>Ports</td>
                    <td>USB Type-A/Type-C</td>
                </tr>
                <tr>
                    <td>Security</td>
                    <td>Support for ZYMKEY 4i, Security Keys</td>
                </tr>
            </tbody>
        </table>
    </TabItem>
</Tabs>

## Thermal Configuration

The Compute Blade is designed for deployment in enclosures, supporting configurations from a single pair in desktop enclosures to up
to 10 pairs in a 19-inch 1U Rack BladeRunner rack-mounted chassis. Each pair is cooled using a specially designed Fan Unit equipped with a single 40x40x20mm fan.

The design of the Fan Units provides robustness and reliability:
in the event of one Compute Blade being disconnected or failing,
the Fan Unit will continue to operate, maintaining effective cooling for the remaining blade.

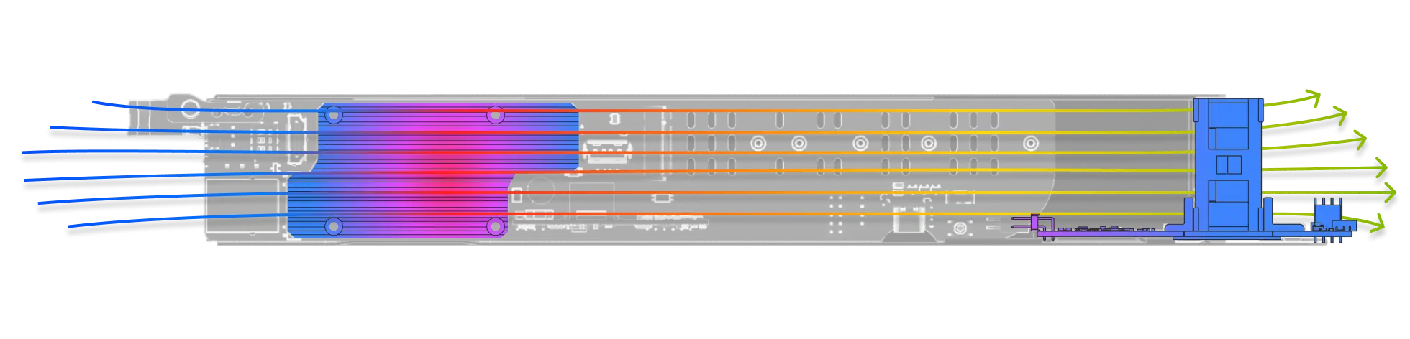
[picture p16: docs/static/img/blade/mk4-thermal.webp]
mk4 thermal flow


:::warning
The Compute blade has not been validated without the addition of the [Fan Unit](/fan-unit/), [BladeRunner™️](/bladerunner/), and [Heat Sink](/blade/heat-sink)
:::

### Cooling Configuration

**Paired Blades:** Pairs of Compute Blades are physically separated and each pair is cooled by its dedicated Fan Unit.

**Fan Unit Design:** The Fan Units are designed for easy replacement without interrupting operation.
Each Fan Unit receives power from both Compute Blades in the pair, ensuring that the fan continues to run even if one of the blades is powered off.

### Thermal Dissipation Capacity

This cooling configuration can dissipate up to 60W of heat per slot,
which represents the maximum power consumption of two blades.
This level of thermal dissipation corresponds to an extreme case scenario.
On average, measured thermal dissipation for a pair of Compute Blades rarely exceeds 20W.

## Block Scheme

This is the top part of the Raspberry Pi's GPIO connector. On the Compute Blade, PIN 1 corresponds to 3.3V, while on the Raspberry Pi's standard connector, it is labeled as 3.3V PWR.

<Tabs groupId="model">
    <TabItem value="dev" label="DEV">
        Dev Blade block Scheme
    </TabItem>
    <TabItem value="tpm" label="TPM">
        TPM Blade block Scheme
    </TabItem>
    <TabItem value="basic" label="Basic">
        Basic Blade block Scheme
    </TabItem>
</Tabs>

## Mechanical

Compute Blade dimensions

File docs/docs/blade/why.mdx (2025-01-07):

---
sidebar_position: 1
---
# Why Compute Blade?

ComputeBlade platform are designed to streamline complex processes, turning what was once a daunting task into a manageable and efficient experience.  

ComputeBlade in combination with BladeRunner enclosure, Fan Unit and Heatsink opens unlimited creative spaces for infrastructure use cases and project scaling. Designed to work 24/7. Developed by listening and understanding the desires of real users. By a real user. Tested in a real production environment. The first prototypes already have more than two years of continuous operation. 

The ComputeBlade is specifically designed to allow you to run the Raspberry Pi CM4 / CM5 at at least 2GHz Increased power and peak power supply power up to 30W with PoE+ 

Compute Blade realized in three different versions to enable a scalable and feature-rich cluster platform as easily as possible:

- With the **Dev version**, you have all the possibilities, which often serves as the master node.
- With the **TPM version**, you can add additional security features like secure boot to your cluster environment, if needed.
- With Basic version scale your cluster project  environments with a low-budget approach.

# Use Cases

To provide all the flexibility and options your project needs, we included different extension ports in the blade design, which can be used for accessories and expansion modules. Our M.2 port serves as a connection for all our high-speed uptime modules, in addition to your NVMe drives. 

Besides feature extension modules, we aim to make the compute cluster experience as effortless as possible. Therefore, we've added additional accessories like enclosures to give the blades a home for all kinds of projects. We also offer different colored heat sinks to easily identify the blades, in addition to the customizable LED function. More enhancements are in the works which will extend your Compute Blade platform.

## Home Labs

An enterprise-level homelab experience that you can use to build, play with, and explore new technologies

## Hosting Provider

Provide dedicated resources and isolate customer machines on a physical layer, to protect against modern CPU/hypervisor exploits.

## Edge Servers

Reduce latency and extend compute power to make your processes leaner, more efficient, and more cost-effective.

## CI/CD System and Automated Tests

Perform performance tests on dedicated hardware for results far more stable than running tests on virtual machines.

## Stateless Computing

Seamlessly deploy specialized stateless computing platforms, such as OpenFaaS, onto the blades to enhance functionality and performance.

## High Availability Computing

Deploy robust, high-availability computing to maintain critical operations and services with minimal downtime.

## Smart Homers

Make your home server highly available and increase the possibilities e.g by adding more modules like the Uptime AI-Module.

## Private Cloud

Create your own secure, scalable private cloud for efficient data management and tailored IT services.

## Education

Enhance educational experiences with practical, hands-on tech learning, facilitating innovation and computing skills.

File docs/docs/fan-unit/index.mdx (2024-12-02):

---
sidebar_position: 1
---

import Tabs from '@theme/Tabs';
import TabItem from '@theme/TabItem';
import useBaseUrl from '@docusaurus/useBaseUrl';
import ThemedImage from '@theme/ThemedImage';

# Overview

<ThemedImage
    alt="Smart Fan Unit with description"
    sources= {{
        light: useBaseUrl('/img/fan-unit/schematics-white-bg.svg'),
        dark: useBaseUrl('/img/fan-unit/schematics-black-bg.svg'),
    }}
    width={"75%"}
/>
<sub>*Smart Fan Unit Pictured Above*</sub>

Download the [Datasheet](/datasheet/FanUnit_datasheet_v.1.0.pdf)

## Fan Units

The Fan Unit offers a compact and efficient method of cooling for two Compute Blades mounted in a BladeRunner™️ enclosure. 
The fan unit uses a 4-pin square connector to communicate with the Compute Blade. It is also shipped with a 5V PWM fan, [Noctua NF-A4x20 5V](https://noctua.at/en/nf-a4x20-5v-pwm).

There are two types of Fan Units, **Standard** and **Smart**.

### Standard

The Standard Fan Unit offers basic PWM functionality, and allows for a no-fuss setup with zero configuration required.
Because of the simplicity in its design, the Standard Fan Unit is unable to receive PWM Signals from both Compute Blades.
The PWM signals can only be sent by the blade on the J1 header (Power Input 1 in the above picture)

:::info
    The fan tachometer signal can be read by both blades. See the [GPIO guide](#blade-connector) for the pin out configuration.
:::

### Smart

To compliment the drawback of the Standard Fan Unit, the Smart Fan Unit uses the [Raspberry Pi RP2040](https://www.raspberrypi.com/products/rp2040/specifications/).
Utilizing the 32-bit dual [ARM Cortex-M0+](https://developer.arm.com/Processors/Cortex-M0-Plus) microcontroller. The Smart Fan Unit is capable of full bidirectional communication to both of the cooled blades, programmable status LEDs, and sensors. 
This enhanced functionality comes with more complexity in its setup and configuration. It requires configuration of both the Smart Fan Unit and the Compute Blade.

## Which Fan Unit Should You Use?

If simple compute tasks are your intended workload or you are using the blade in a hobbyist environment, the Standard Fan Unit is likely right for you.

If you are looking for detailed information about the state of the fan, or have more dynamic workloads the Smart Fan Unit may be necessary.

## Specification
<Tabs groupId="fanunit" defaultValue="smart">
    <TabItem value="smart" label="Smart">
        <table>
            <tbody>
                <tr>
                    <td rowSpan={2}>Compatibility</td>
                    <td>Compute Blade</td>
                </tr>
                <tr>
                    <td>BladeRunner™️ Enclosures</td>
                </tr>
                <tr>
                    <td>Storage</td>
                    <td>16M-Bit Serial Flash Memory</td>
                </tr>
                <tr>
                    <td rowSpan={6}>GPIO</td>
                    <td>2 x UART</td>
                </tr>
                <tr>
                    <td>4-Pin 5V PWM Fan Header</td>
                </tr>
                <tr>
                    <td>Boot Button</td>
                </tr>
                <tr>
                    <td>Programmable Button</td>
                </tr>
                <tr>
                    <td>2 x Digital RGB LEDs</td>
                </tr>
                <tr>
                    <td>1 x LED</td>
                </tr>
                <tr>
                    <td>Voltage Max</td>
                    <td>6V</td>
                </tr>
                <tr>
                    <td>Voltage Min</td>
                    <td>2.8V</td>
                </tr>
                <tr>
                    <td>Current Max</td>
                    <td>110 mA</td>
                </tr>
                <tr>
                    <td>Current Min</td>
                    <td>0.18 mA</td>
                </tr>
                <tr>
                    <td>Input Power (Max.)</td>
                    <td>0.65W</td>
                </tr>
                <tr>
                    <td>Airflow Control Unit</td>
                    <td>EMC2101</td>
                </tr>
                <tr>
                    <td>Temperature Monitoring Unit</td>
                    <td>EMC2101</td>
                </tr>
                <tr>
                    <td>Fan Dimensions</td>
                    <td>40x40x20mm</td>
                </tr>
                <tr>
                    <td>Dimensions</td>
                    <td>40x95x43.2mm</td>
                </tr>
            </tbody>
        </table>
    </TabItem>
    <TabItem value="sta" label="Standard">
        <table>
            <tbody>
                <tr>
                    <td rowSpan={2}>Compatibility</td>
                    <td>Compute Blade</td>
                </tr>
                <tr>
                    <td>BladeRunner™️ Enclosures</td>
                </tr>
                <tr>
                    <td rowSpan={2}>GPIO</td>
                    <td>2 x Blade Connections</td>
                </tr>
                <tr>
                    <td>4-Pin 5V PWM Fan Header</td>
                </tr>
                <tr>
                    <td>Voltage Max</td>
                    <td>5v</td>
                </tr>
                <tr>
                    <td>Max. input current</td>
                    <td>100 mA</td>
                </tr>
                <tr>
                    <td>Input current (typical)</td>
                    <td> 80 mA</td>
                </tr>
                <tr>
                    <td>Input Power (Max.)</td>
                    <td>0.5W</td>
                </tr>
                <tr>
                    <td>Fan Dimensions</td>
                    <td>40x40x20mm</td>
                </tr>
                <tr>
                    <td>Dimensions</td>
                    <td>40x95x43.2mm</td>
                </tr>
            </tbody>
        </table>
    </TabItem>
</Tabs>
For additional information on the NF-A4x20 5V, see the [datasheet](https://noctua.at/pub/media/blfa_files/infosheet/noctua_nf_a4x20_5v_datasheet_en_web_1.pdf)
## Block Scheme

<Tabs groupId="fanunit" defaultValue="smart">
    <TabItem value="smart" label="Smart">
        Standard Fan Unit Block Scheme
    </TabItem>
    <TabItem value="sta" label="Standard">
        Standard Fan Unit Block Scheme
    </TabItem>
</Tabs>

## GPIO

### Blade Connector

:::danger
The Blade connector is a square un-keyed connector. This means that is is physically possible to misalign the connector.
:::

<Tabs groupId="fanunit" defaultValue="smart">
    <TabItem value="smart" label="Smart">
        
    </TabItem>
    <TabItem value="sta" label="Standard">
        
    </TabItem>
</Tabs>

### Fan Header

The header uses a four-pin Molex connector([KK family](https://www.molex.com/en-us/products/connectors/wire-to-board-connectors/kk-connectors)). And follows the [Noctua 5V Fan pin configuration](https://faqs.noctua.at/en/support/solutions/articles/101000081757-what-pin-configuration-do-noctua-fans-use-).



### Debugging (Smart Fan Unit Only)

The J5 debug header enables debugging of the RP2040 via a tool like the [Raspberry Pi Debug Probe](https://www.raspberrypi.com/products/debug-probe/).



## Mechanical

Fan Unit dimensions

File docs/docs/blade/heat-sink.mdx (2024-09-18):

# Heat Sink

Designed and engineered specifically for the Compute Blade, it doesn't limit your Compute Blade access and provides optimized heat removal.

The aluminum Heat Sink is meticulously engineered to provide maximum heat dissipation, ensuring that your Compute Blade operates at optimal temperatures. Its sleek design not only complements the aesthetics of your setup but also contributes to the longevity and stability of your system.

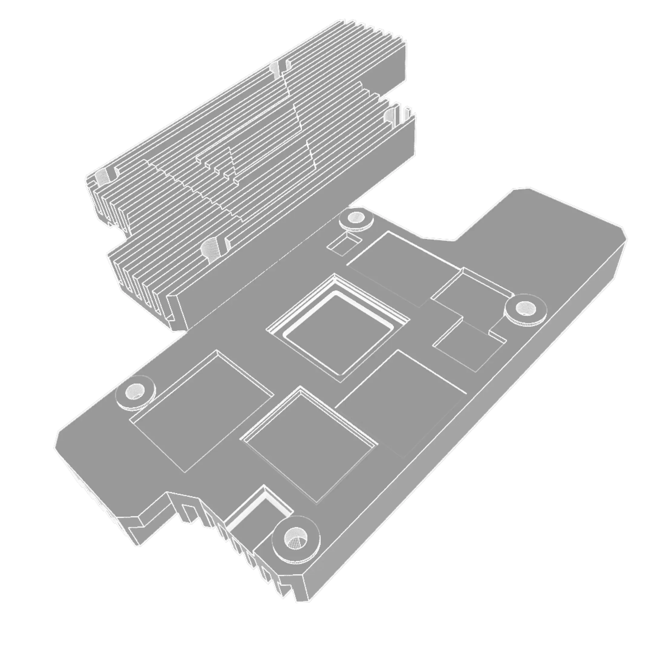
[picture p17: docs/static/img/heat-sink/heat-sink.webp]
Heat Sink


[Heat Sink Datasheet](/datasheet/Heatsink_datasheet_v.1.0.pdf) (PDF)

## features

- Integrates within ComputeBlade
- Thermal Conductivity 229 W/mK
- Optimized heat removal

Compatibility: Compute Blade V0.9 RC2, V1.0 mk1, V1.0 mk4-k, V1.0 mk4

Dimensions: 40mm x 86mm x 9mm

## Mechanical

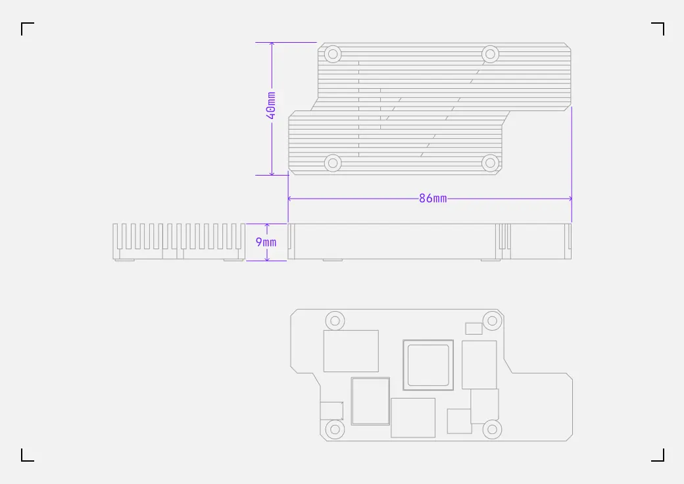
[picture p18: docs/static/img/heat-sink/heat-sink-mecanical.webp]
Headsink


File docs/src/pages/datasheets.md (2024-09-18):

# Data sheets

[Compute Blade v.1.1](/datasheet/ComputeBlade_datasheet_v.1.1.pdf) (PDF)

[Fan Unit v.1.0](/datasheet/FanUnit_datasheet_v.1.0.pdf) (PDF)

[BladeRunner™️ v.1.0](/datasheet/BladeRunner_datasheet_v.1.0.pdf) (PDF)

[Heatsink v.1.0](/datasheet/Heatsink_datasheet_v.1.0.pdf) (PDF)

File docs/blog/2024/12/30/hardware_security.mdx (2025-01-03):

---
title: Understanding Hardware Security with TPM
description: A deep dive into the Trusted Platform Module technology and its implementation in ComputeBlade.
authors: brushknight
tags: [blade]
image: /img/blog/tpm_purple.webp
hide_table_of_contents: false
---

A deep dive into the Trusted Platform Module technology and its implementation in ComputeBlade.

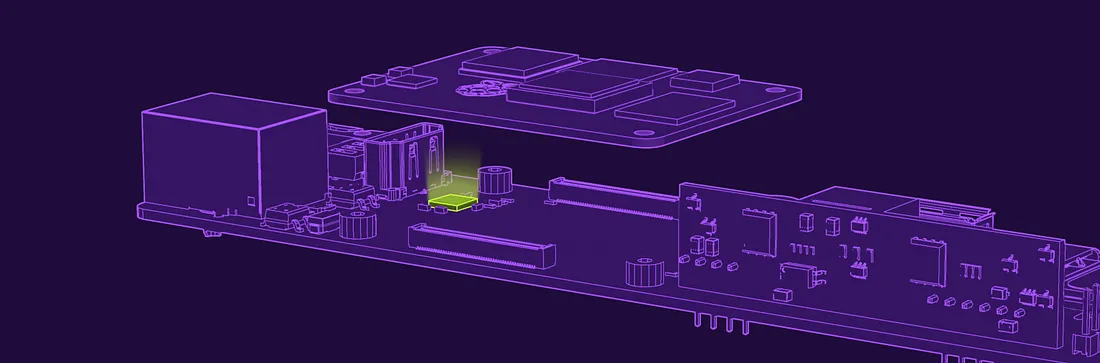
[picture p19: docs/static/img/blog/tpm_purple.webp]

{/* add alt text */}

{/* truncate */}

A TPM (Trusted Platform Module) is a specialized security chip that provides hardware-based security functions. It is designed to protect hardware through integrated cryptographic keys and can perform various security operations:

- Hardware-based encryption and key storage;
- Secure boot process verification;
- Platform authentication;
- Protection against firmware tampering

The TPM module provides a root of trust for the system, ensuring that the hardware and software configurations remain secure and uncompromised. It's particularly valuable in scenarios where physical security and data protection are critical requirements.

ComputeBlade Dev and TPM versions are equipped with the Infineon OPTIGA™ TPM 2.0 security solution, which provides robust hardware-based security features.

---

## Enabling TPM Module

:::warning
Our tutorial assumes that you are running [ubuntu 24.04 LTS](https://ubuntu.com/blog/tag/ubuntu-24-04-lts) or later, other distributions might work, but commands could require modifications.
:::

Follow these steps to enable and verify the TPM module on your ComputeBlade. Make sure you have SSH access to proceed with the configuration.

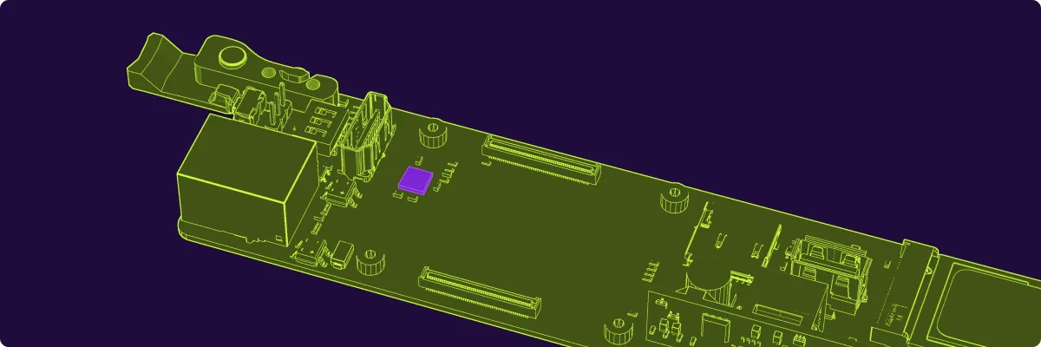
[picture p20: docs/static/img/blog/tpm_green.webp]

{/* add alt text */}

### Enable TPM module

Connect to ComputeBlade via SSH, use the following command to enable the TPM module, and then reboot:

```bash
sudo tee -a /boot/firmware/config.txt << 'EOF'
# Enable TPM module
dtoverlay=tpm-slb9670
EOF
```
```bash
sudo reboot
```

### Install tpm2-tools

Reconnect to ComputeBlade and install tpm2-tools to access the TPM hardware module:

sudo apt install tpm2-tools
Verifying that TPM works
Example 1: Generating a random string
To check if the TPM module is enabled, let's generate a random string:
```bash
sudo tpm2_getrandom --hex 8
```

Console will return something like that:

```txt
14309e4d1a3447bc
```

## Example 2: Signature verification

In the following example, we'll create a simple message, sign it using TPM, and then verify its authenticity. This demonstrates how TPM can be used for secure data validation in real-world applications.

1. Create a directory.

```bash
mkdir test_tpm && cd test_tpm
```

2. Create primary context (Primary Object) and load it.

```bash
tpm2_createprimary -C e -c primary.ctx
```

3. Generate public and private keys.

```bash
tpm2_create -G rsa -u rsa.pub -r rsa.priv -C primary.ctx
```

4. Load both the private and public portions of an object into the TPM or load the object in the TSS2-Private-Key PEM format.

```bash
tpm2_load -C primary.ctx -u rsa.pub -r rsa.priv -c rsa.ctx
```

5. Create a test data file.

```bash
echo "my message" > message.dat
```

6. Generate signature of specified message or message-digest using the specified symmetric or asymmetric signing key.

```bash
tpm2_sign -c rsa.ctx -g sha256 -o message.sig message.dat
```

7. Validate a signature on a message with the message digest passed to the TPM. If the signature check succeeds, then the TPM will produce a `TPMT_TK_VERIFIED`.

```bash
tpm2_verifysignature -c rsa.ctx -g sha256 -s message.sig -m message.dat
```

8. To verify that the signature validation works correctly, let's modify the message to.

```bash
echo "hello ComputeBlade" > message.dat
```

Running the verification command again will result in an error:

```bash
tpm2_verifysignature -c rsa.ctx -g sha256 -s message.sig -m message.dat
```

```txt
WARNING:esys:src/tss2-esys/api/Esys_VerifySignature.c:302:Esys_VerifySignature_Finish() Received TPM Error
ERROR:esys:src/tss2-esys/api/Esys_VerifySignature.c:103:Esys_VerifySignature() Esys Finish ErrorCode (0x000002db)
ERROR: Esys_VerifySignature(0x2DB) - tpm:parameter(2):the signature is not valid
ERROR: Verify signature failed!
ERROR: Unable to run tpm2_verifysignature
```

## TPM Command Reference

Infineon TPM 2.0 embedded chip
Photo by [Jeff Geerling](https://www.jeffgeerling.com/blog/2021/uptime-labs-cm4-blade-adds-nvme-tpm-20-raspberry-pi).

Here is the list of possible commands to use:

```txt
tpm2_activatecredential       tpm2_gettestresult            tpm2_policynamehash
tpm2_certify                  tpm2_gettime                  tpm2_policynv
tpm2_certifyX509certutil      tpm2_hash                     tpm2_policynvwritten
tpm2_certifycreation          tpm2_hierarchycontrol         tpm2_policyor
tpm2_changeauth               tpm2_hmac                     tpm2_policypassword
tpm2_changeeps                tpm2_import                   tpm2_policypcr
tpm2_changepps                tpm2_incrementalselftest      tpm2_policyrestart
tpm2_checkquote               tpm2_load                     tpm2_policysecret
tpm2_clear                    tpm2_loadexternal             tpm2_policysigned
tpm2_clearcontrol             tpm2_makecredential           tpm2_policytemplate
tpm2_clockrateadjust          tpm2_nvcertify                tpm2_policyticket
tpm2_commit                   tpm2_nvdefine                 tpm2_print
tpm2_create                   tpm2_nvextend                 tpm2_quote
tpm2_createak                 tpm2_nvincrement              tpm2_rc_decode
tpm2_createek                 tpm2_nvread                   tpm2_readclock
tpm2_createpolicy             tpm2_nvreadlock               tpm2_readpublic
tpm2_createprimary            tpm2_nvreadpublic             tpm2_rsadecrypt
tpm2_dictionarylockout        tpm2_nvsetbits                tpm2_rsaencrypt
tpm2_duplicate                tpm2_nvundefine               tpm2_selftest
tpm2_ecdhkeygen               tpm2_nvwrite                  tpm2_send
tpm2_ecdhzgen                 tpm2_nvwritelock              tpm2_sessionconfig
tpm2_ecephemeral              tpm2_pcrallocate              tpm2_setclock
tpm2_encodeobject             tpm2_pcrevent                 tpm2_setcommandauditstatus
tpm2_encryptdecrypt           tpm2_pcrextend                tpm2_setprimarypolicy
tpm2_eventlog                 tpm2_pcrread                  tpm2_shutdown
tpm2_evictcontrol             tpm2_pcrreset                 tpm2_sign
tpm2_flushcontext             tpm2_policyauthorize          tpm2_startauthsession
tpm2_getcap                   tpm2_policyauthorizenv        tpm2_startup
tpm2_getcommandauditdigest    tpm2_policyauthvalue          tpm2_stirrandom
tpm2_geteccparameters         tpm2_policycommandcode        tpm2_testparms
tpm2_getekcertificate         tpm2_policycountertimer       tpm2_tr_encode
tpm2_getpolicydigest          tpm2_policycphash             tpm2_unseal
tpm2_getrandom                tpm2_policyduplicationselect  tpm2_verifysignature
tpm2_getsessionauditdigest    tpm2_policylocality           tpm2_zgen2phase
```
Learn more about all possible use cases of this library [here](https://tpm2-tools.readthedocs.io/en/latest/).

---

## Extra
The manufacturer's library provides comprehensive information about the installed TPM module.

1. Steps to setup test library.

```bash
mkdir infineon && cd infineon
git clone <https://github.com/Infineon/eltt2.git>
cd eltt2/
sudo apt install make gcc
make
sudo ./eltt2 -g
```
Should output something like:

```txt
TPM capability information of fixed properties:
=========================================================
TPM_PT_FAMILY_INDICATOR:        2.0
TPM_PT_LEVEL:                   0
TPM_PT_REVISION:                138
TPM_PT_DAY_OF_YEAR:             8
TPM_PT_YEAR:                    2018
TPM_PT_MANUFACTURER:            IFX
TPM_PT_VENDOR_STRING:           SLB9670
TPM_PT_VENDOR_TPM_TYPE:         0
TPM_PT_FIRMWARE_VERSION:        7.85.4555.0
TPM_PT_MEMORY:
=========================================================
Shared RAM:                     0 CLEAR
Shared NV:                      1 SET
Object Copied To Ram:           1 SET
TPM_PT_PERMANENT:
=========================================================
Owner Auth Set:                 0 CLEAR
Sendorsement Auth Set:          0 CLEAR
Lockout Auth Set:               0 CLEAR
Disable Clear:                  0 CLEAR
In Lockout:                     0 CLEAR
TPM Generated EPS:              0 CLEAR
```

## Resources:
Trusted Platform Module - Ubuntu wiki
Jeff Geerling - Uptime Lab's CM4 Blade adds NVMe, TPM 2.0 to Raspberry Pi
TPM 2.0 in U-Boot on Raspberry Pi 4
TPM (Trusted Platform Module) 2.0 tools

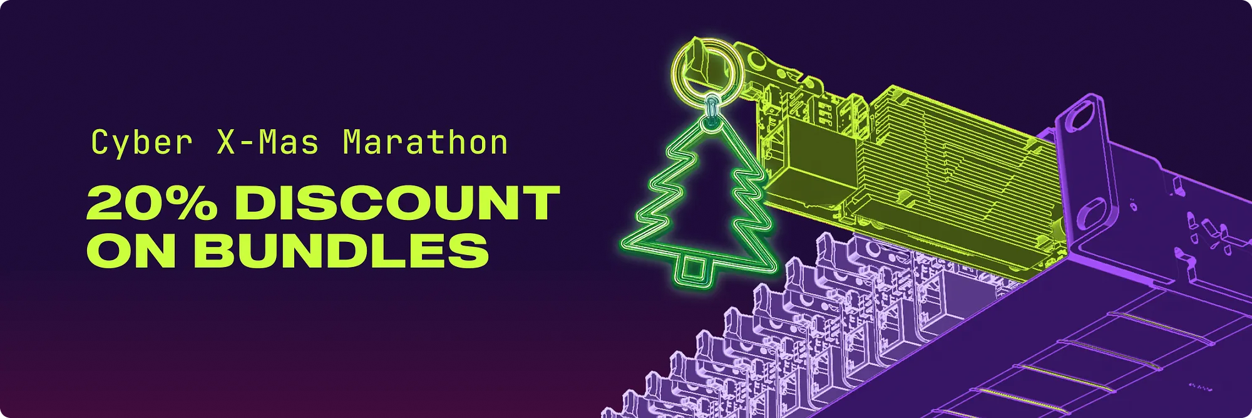
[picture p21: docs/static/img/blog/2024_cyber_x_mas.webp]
2024 Cyber bundle ad


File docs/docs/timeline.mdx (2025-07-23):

import Admonition from '@theme/Admonition';

# Kickstarter Timeline

<Admonition type="warning" title="Organization update">
Computreblade is no longer part of Uptime Industries or Lemony AI. 
</Admonition>
<Admonition type="warning" title="Shipping Update">
- Unfulfilled orders in the process of being fulfilled by distributors
- Sales and support to continue through distributors
- Modules and new accessories will be developed by Ivan and the Contributors
For most up-to-date information Join our [Discord](https://discord.gg/invite/uptime-industries-952334175501946902)
</Admonition>

<Admonition type="note" title="Retail Availability">
Compute Blade is a available in at the following retailers.
- [RaspberryPi.dk](https://raspberrypi.dk/en/?s=compute+blade&post_type=product)
- [Semaf Electronics](https://electronics.semaf.at/uptime-industries)
- [buyzero by pi3g](https://buyzero.de/collections/uptime-industries)
- [Welectron](https://www.welectron.com/Uptime-Industries)
- [BerryBase](https://www.berrybase.de/uptime-industries/)
- [PiShop US](https://www.pishop.us/uptime-industries/)
</Admonition>

| Item | Estimated start Shipping Date | Status |
| :--- | :---: | :---: |
| Team Cluster | 2024-04-03 | Blade Replacements shipping |
| Batch00 | 2024-10-16 | Shipping to EU, UK, US, CA |
| Batch01 | ~ | Checking Status |
| Build your own Cluster | ~ | Checking Status |
| 10" Rack Cluster | ~ | Checking Status |
| 19" Rack Cluster | 2024-10-16 | Checking Status |
| AI Module | ~ | Testing validation Sample |

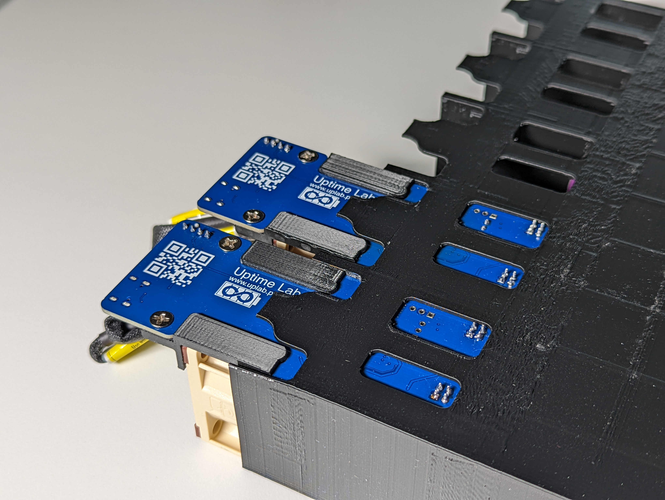
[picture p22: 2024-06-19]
fan-unit/img/Fan_Unit_mounting.jpg

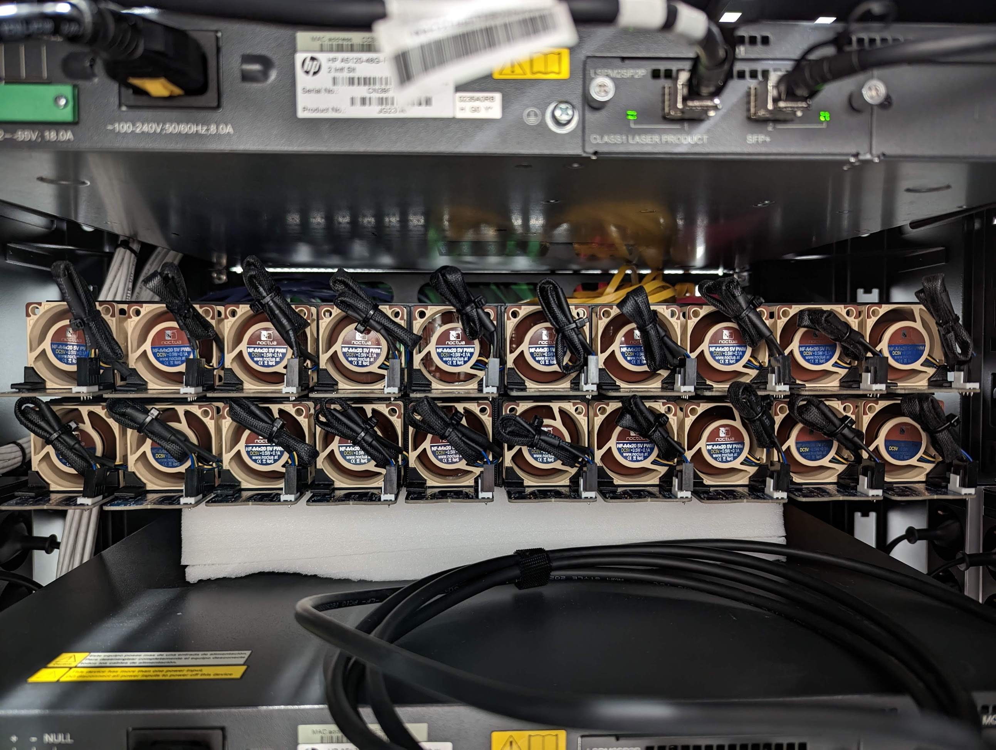
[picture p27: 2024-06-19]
fan-unit/img/20x_Fan_Units.jpg

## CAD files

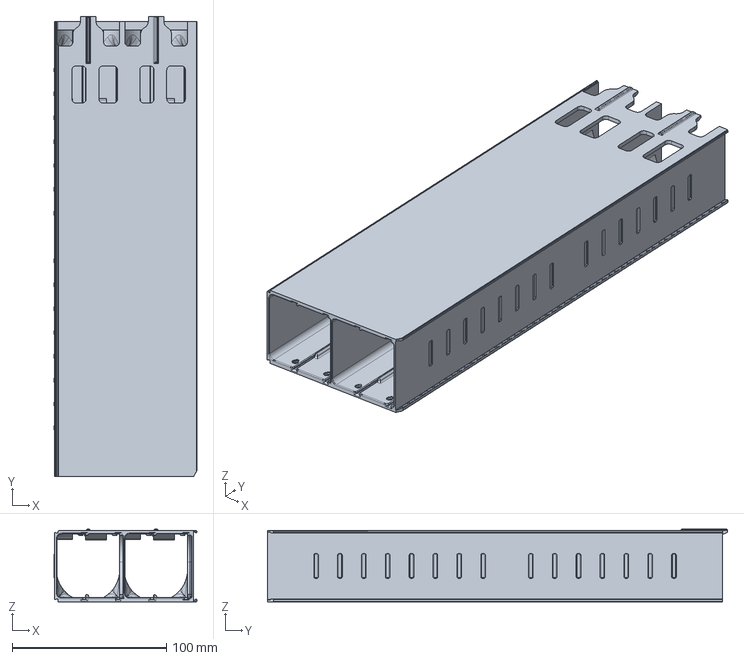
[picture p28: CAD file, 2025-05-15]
models/bladerunner/quad/Full 4-node_(v4).step
92.4 x 298.2 x 47.3 mm

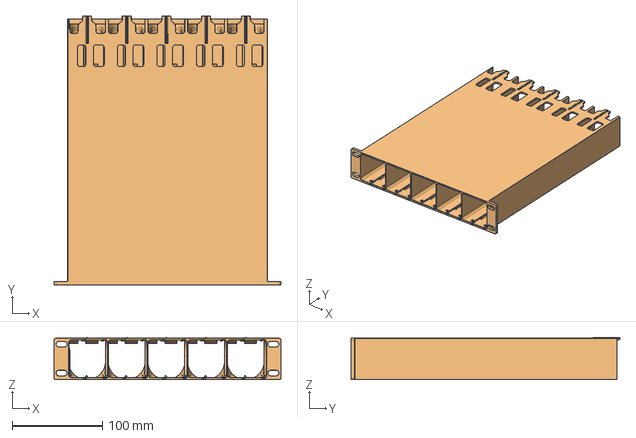
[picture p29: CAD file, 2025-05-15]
models/bladerunner/10-inch/10-inch_BladeRunner_(v5).step
251.7 x 298.2 x 47.1 mm

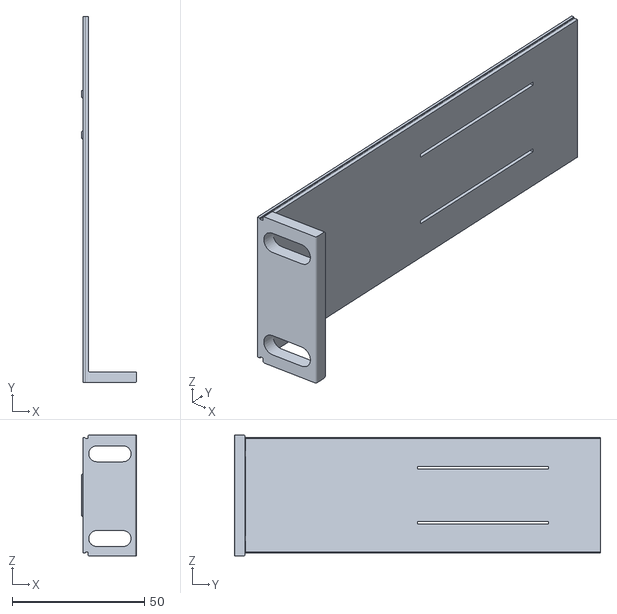
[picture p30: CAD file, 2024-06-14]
models/bladerunner/19-inch/left bracket long.stl
20.7 x 138.3 x 45.7

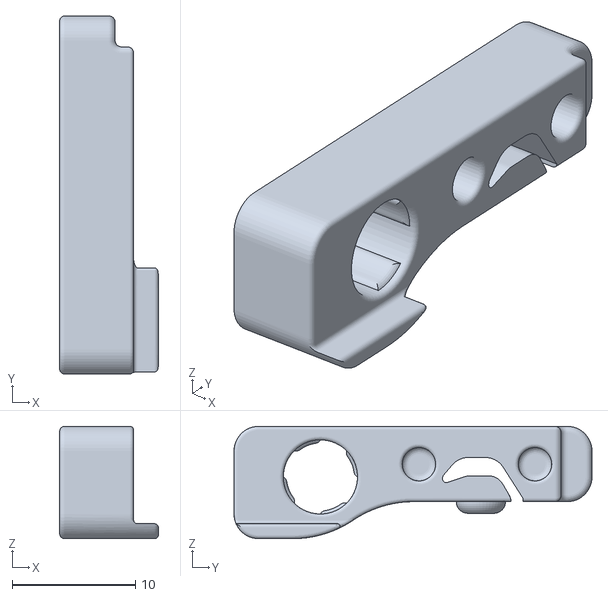
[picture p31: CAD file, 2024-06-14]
models/bladerunner/latch/mount.stl
8.00 x 29.0 x 9.10

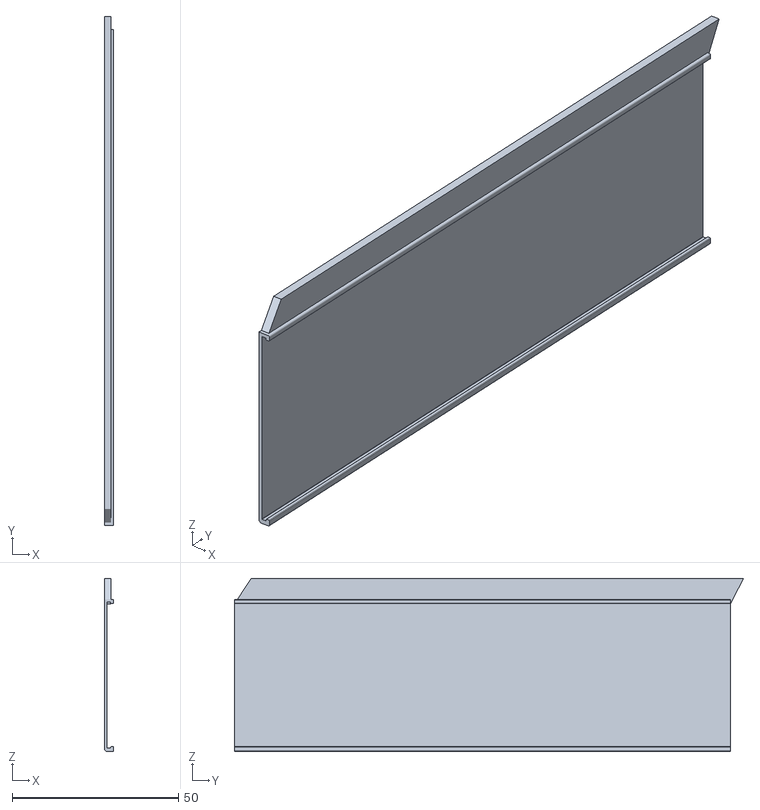
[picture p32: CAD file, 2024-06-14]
models/bladerunner/quad/stand/right.stl
2.80 x 153.0 x 52.0

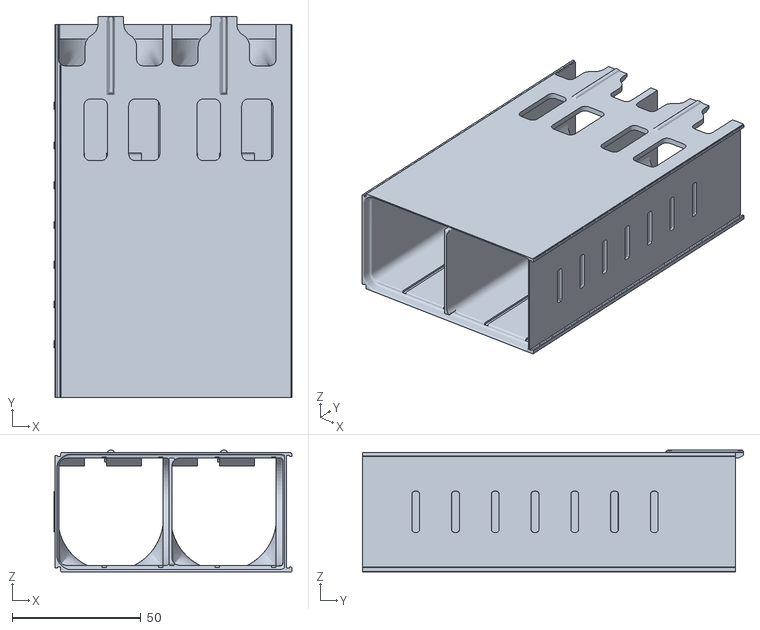
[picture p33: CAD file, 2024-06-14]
models/bladerunner/quad/v3, for a 3D-printer with a print height of 180 mm/Back.stl
92.4 x 148.2 x 47.3

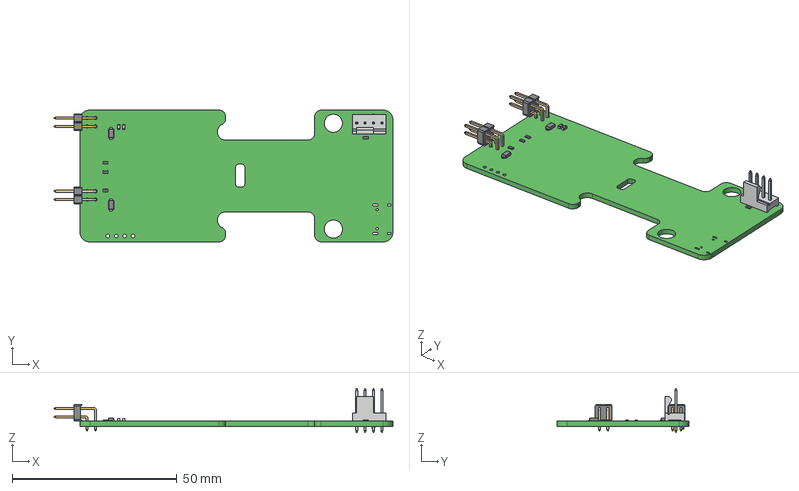
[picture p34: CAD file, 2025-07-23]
models/fan-unit/Standard_v1.1.step
102.9 x 40.0 x 13.5 mm
res0603 x 4
6130xx21021_PIN x 4
6130xx21021_PIN_G x 4
User Library-SOD-123FL x 2
User Library-CAP_0603_CAP_0603_Lead_1 x 4
User Library-CAP_0603_CAP_0603_Body_1 x 2

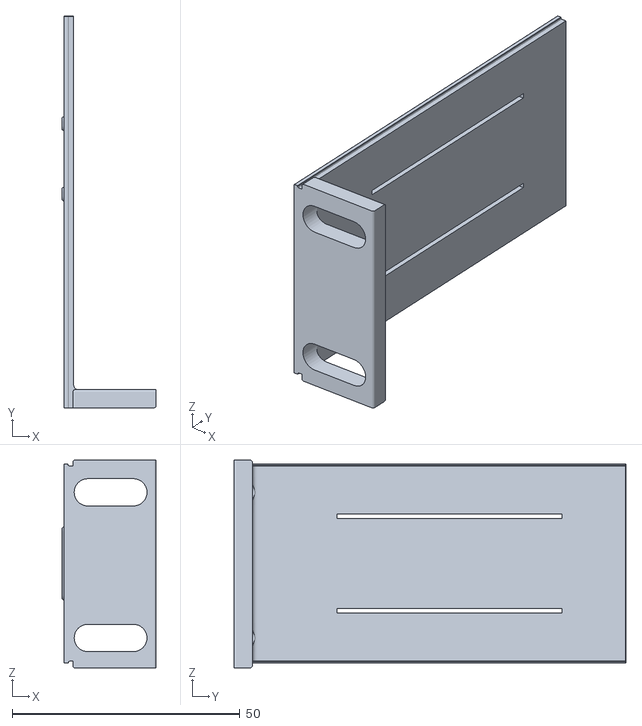
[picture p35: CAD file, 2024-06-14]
models/bladerunner/19-inch/left bracket.stl
20.7 x 86.1 x 45.7

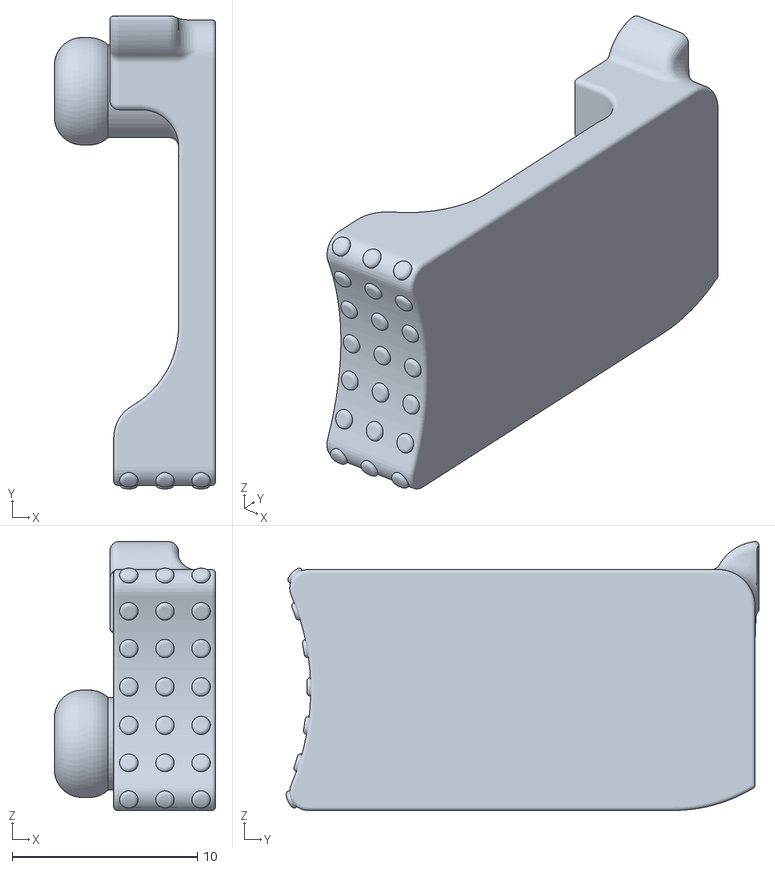
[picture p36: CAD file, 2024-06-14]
models/bladerunner/latch/latch.stl
8.70 x 25.5 x 14.5

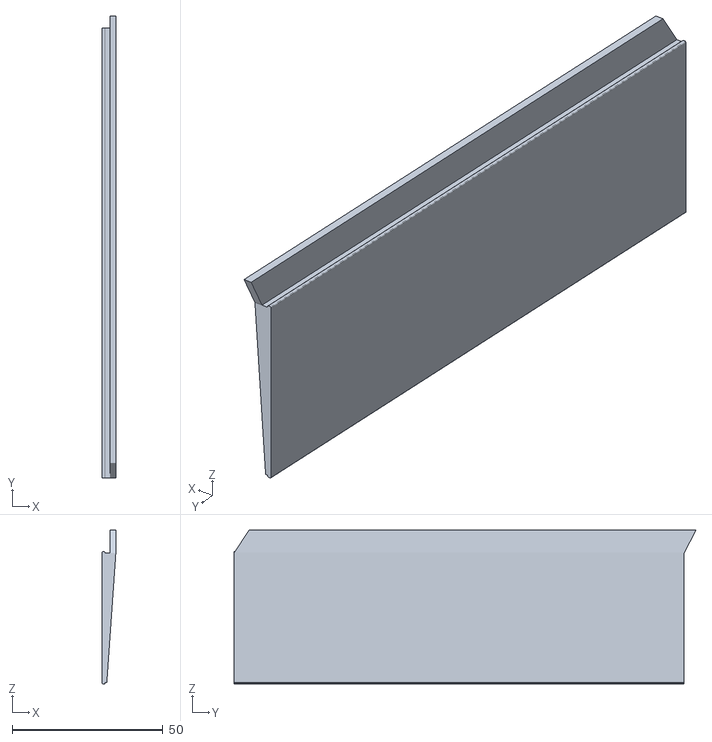
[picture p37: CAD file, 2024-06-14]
models/bladerunner/quad/stand/left.stl
4.56 x 153.0 x 51.0

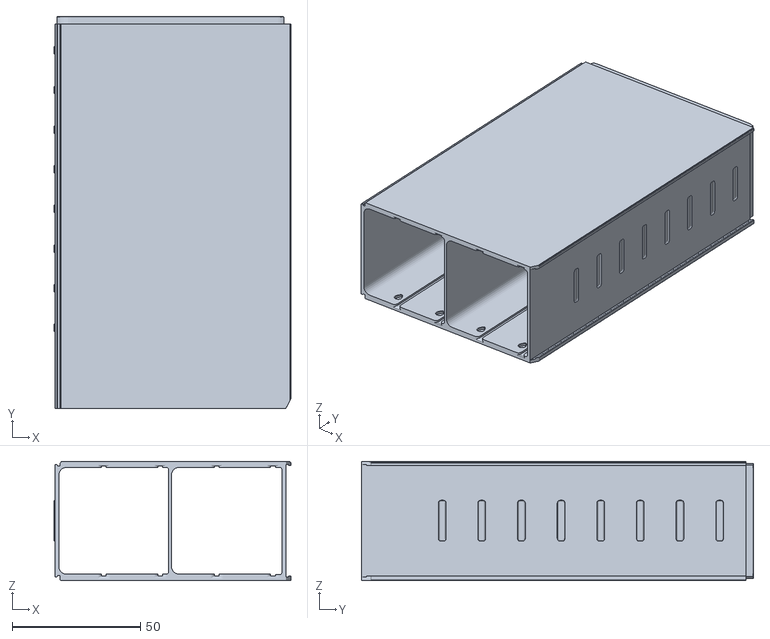
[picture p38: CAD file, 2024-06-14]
models/bladerunner/quad/v3, for a 3D-printer with a print height of 180 mm/Front.stl
92.4 x 153.0 x 46.5

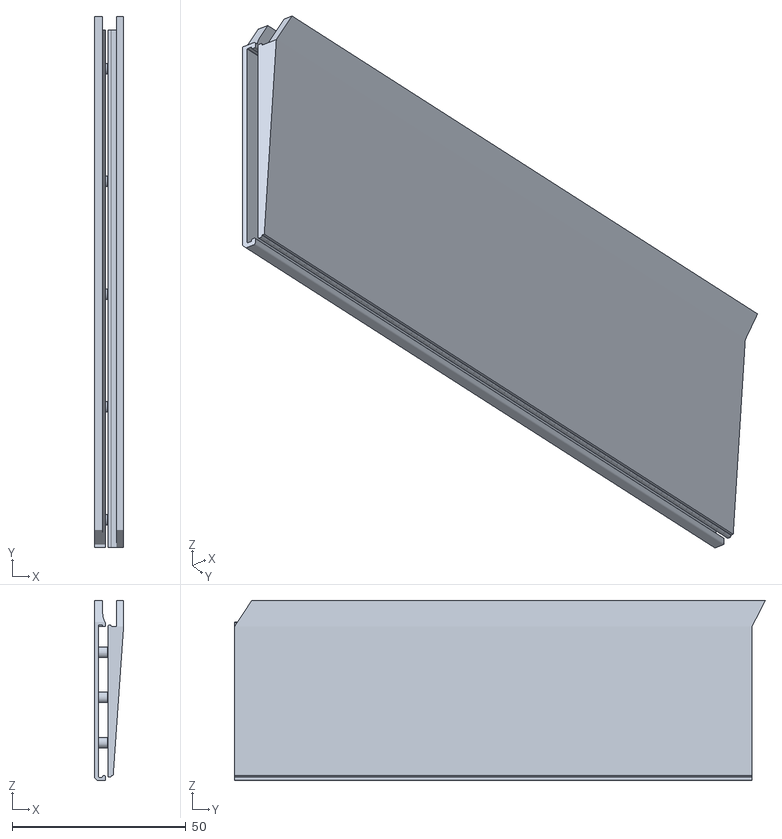
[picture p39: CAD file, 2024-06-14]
models/bladerunner/twin/Stand/both.stl
8.44 x 153.0 x 52.0

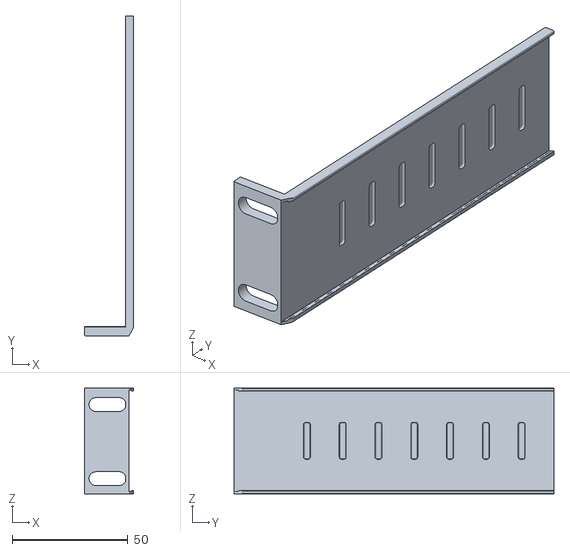
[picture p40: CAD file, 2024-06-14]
models/bladerunner/19-inch/right bracket long.stl
21.3 x 138.3 x 45.7

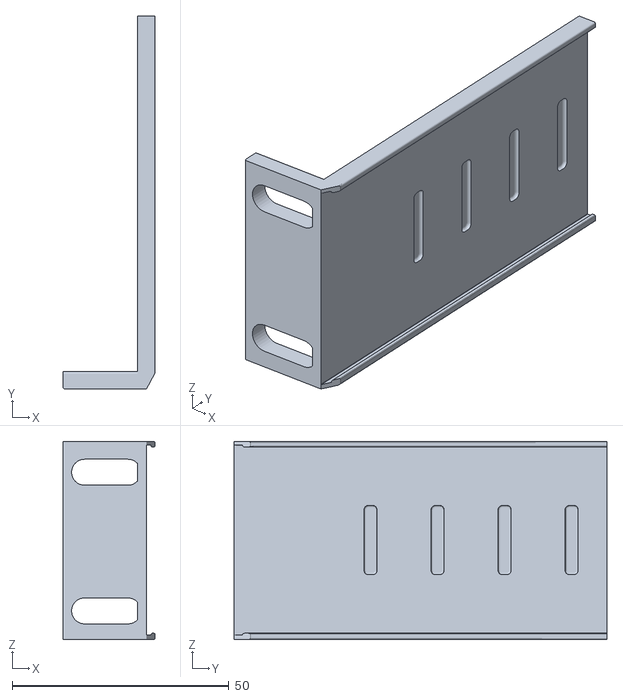
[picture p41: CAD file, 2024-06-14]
models/bladerunner/19-inch/right bracket.stl
21.3 x 86.1 x 45.7

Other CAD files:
fan-unit/fan-bracket/right.stl
fan-unit/fan-bracket/left.stl

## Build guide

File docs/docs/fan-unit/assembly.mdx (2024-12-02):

---
sidebar_position: 2
---

# Assembly

:::note
The assembly process for both the Standard and Smart Fan Units are the same
:::

Fan Units will come in four parts:
- Fan Unit board
- Left Bracket
- Right Bracket
- 5V Fan

:::warning
    The Fan Unit is designed for a 5V fan like the Noctua [NF-A4x20 5V PWM](https://noctua.at/en/products/fan/nf-a4x20-5v-pwm)
:::

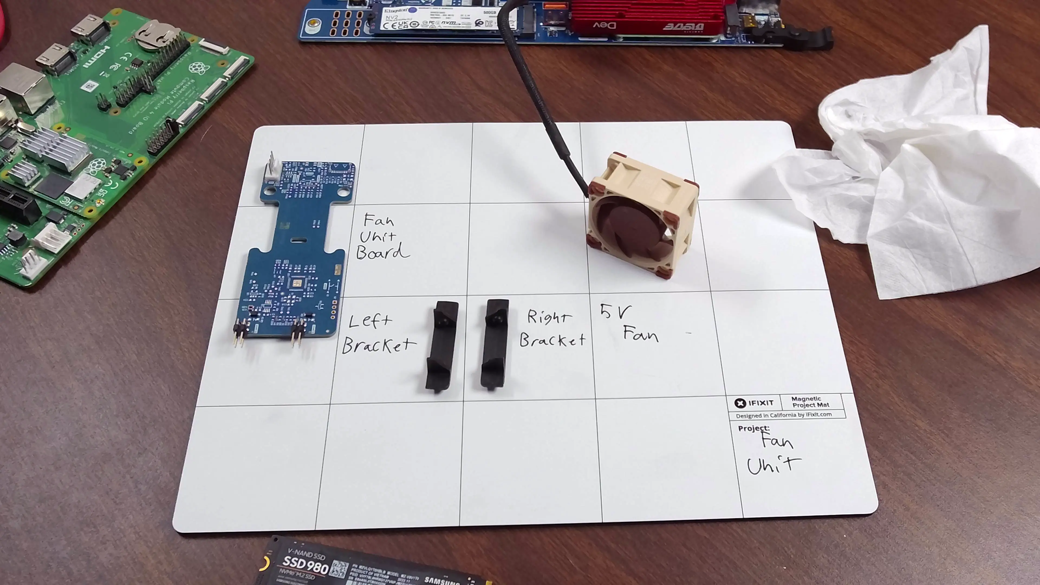
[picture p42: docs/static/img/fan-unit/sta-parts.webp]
Fan Unit parts


Start by installing the brackets onto the Fan. The brackets are toolless and will snap right on.

:::note
    The Fan Brackets are not symmetrical; ensure that the fan is correctly oriented for your desired air flow configuration.
:::

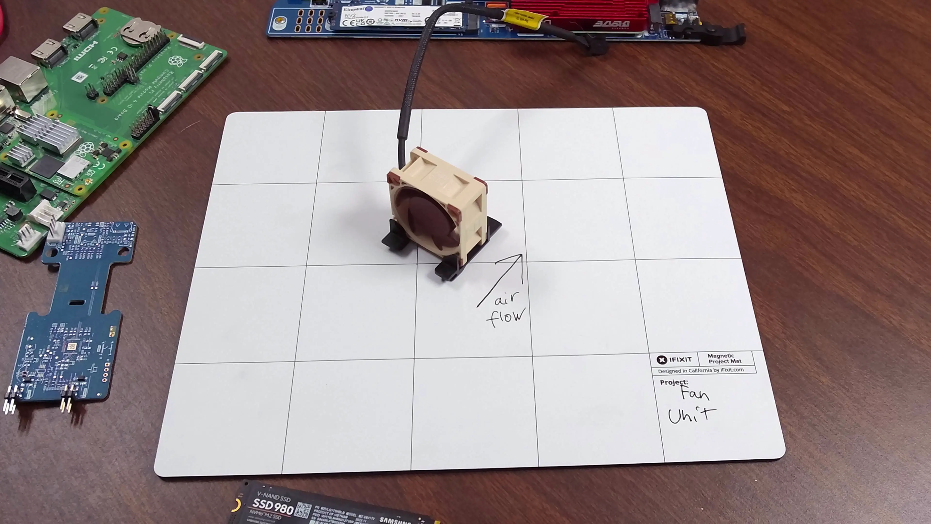
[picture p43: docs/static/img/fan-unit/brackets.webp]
fans with Brackets installed


Next slide the fan with the brackets into the Fan Unit board

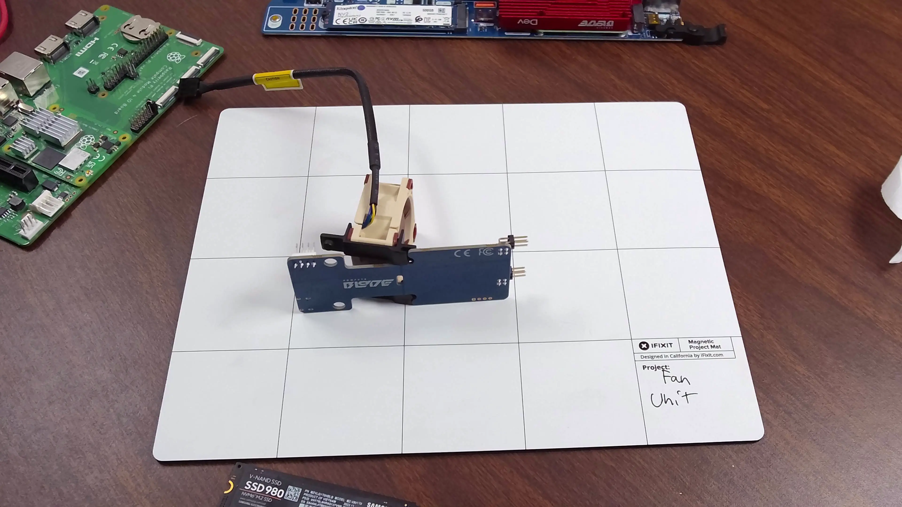
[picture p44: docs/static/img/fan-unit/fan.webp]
Fan installed onto fan unit board


Finally, connect the Fan to the 4-pin fan header on the fan unit board.

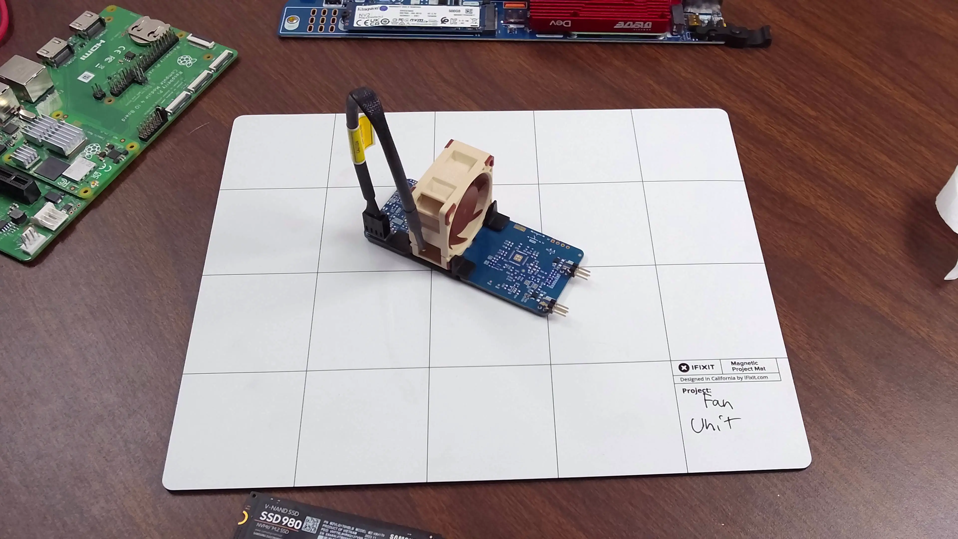
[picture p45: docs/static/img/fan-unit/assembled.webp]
fully assembled Fan Unit


### Connecting to Compute Blade
:::info
    The Fan Units are only designed to work with the [BladeRunner™™️](/bladerunner) enclosures
:::

When connecting the blade to the Fan Unit the boards should be 90° relative to each other. They use a square 4-pin connector and it is possible to connect them incorrectly out side of a BladeRunner enclosure. To avoid this please only connect the Fan Unit to the Compute Blade in a BladeRUnner Enclosure

:::danger
    Plugging the Compute Blade into the Fan Unit incorrectly may lead to permanent damage to the Fan Unit, Blade, and any device installed on the Blade.
:::

blade assembled with out Bladerunner

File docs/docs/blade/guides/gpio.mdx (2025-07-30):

---
sidebar_position: 3
---

import useBaseUrl from '@docusaurus/useBaseUrl';
import Tabs from '@theme/Tabs';
import TabItem from '@theme/TabItem';
import Admonition from '@theme/Admonition';

# General-Purpose Input/Output
The Compute Blade allows for the uses of 11 of the Compute Module's GPIO pins.
The GPIO allows for low speed modules and additional device control.

### GPIO Locations and Functions
::::note
Functions are configurable and do not have to match the given functions.
    :::warning
    Using internal GPIO for unintended uses may lead to damage.
::::

| GPIO | Location |  Functions |
| :---: | :--- | :--- |
| [2](https://pinout.xyz/pinout/pin3_gpio2/) | Expansion Module Port | I2C1 SDA |
| [3](https://pinout.xyz/pinout/pin5_gpio3/) | Expansion Module Port | I2C1 SLC |
| [4](https://pinout.xyz/pinout/pin7_gpio4/) | Expansion Module Port | GPCLK0 |
| [12](https://pinout.xyz/pinout/pin32_gpio12/) | Fan Unit Connector | PWM0, UART5 TX |
| [13](https://pinout.xyz/pinout/pin32_gpio12/) | Fan Unit Connector | PWM1, UART5 RX |
| [14](https://pinout.xyz/pinout/pin32_gpio12/) | Expansion Module Port, UART Front(3pin), UART Back(4pin)  | UART0 TX |
| [15](https://pinout.xyz/pinout/pin32_gpio12/) | Expansion Module Port, UART Front(3pin), UART Back(4pin)  | UART0 RX |
| [18](https://pinout.xyz/pinout/pin12_gpio18/) | Internal | LEDs Control |
| [20](https://pinout.xyz/pinout/pin38_gpio20/) | Internal | Edge Button |
| [21](https://pinout.xyz/pinout/pin40_gpio21/) | Internal | LED Control |
| [23](https://pinout.xyz/pinout/pin16_gpio23/) | Internal | PoE+ Indicator |

## Pinout Guide
:::tip
View an interactive guide to the full Raspberry Pi GPIO pinout on [Pinout.xyz](https://pinout.xyz/)
:::
<Tabs groupId='pinout'>
    <TabItem value="Expansion" label="Expansion Module Port" default>
        The Expansion Module Port is pin 1 through pin 10 of the Raspberry Pi GPIO pinout.
        This makes the Expansion Module Port compatible with many existing products like [Real Time Clock Modules or I2C Devices](/modules).
        Ensure you reference the pinout on your specific Compute Blade and the module's datasheet for correct wiring.
        Expansion Module Port
    </TabItem>
    <TabItem value="uart" label="UART" default>
        There are two dedicated sets of pins for UART0. The V5 line on UART Back can operate as an Input or Output.

        <div className="center-i">
            UART Front
            UART Back
        </div>

        <Admonition type="warning" title="Warning">
            <p>When no power source is connected to the compute blade the V5 pin can only be an input.</p>
        </Admonition>
    </TabItem>
    <TabItem value="fan" label="Fan Unit Connector" default>
        The square connector at the end of the Blade.
        The main purpose is to connect to a Fan Unit. It can be used to control any 5v PWM fan or as an additional UART port (`UART5` on CM4)

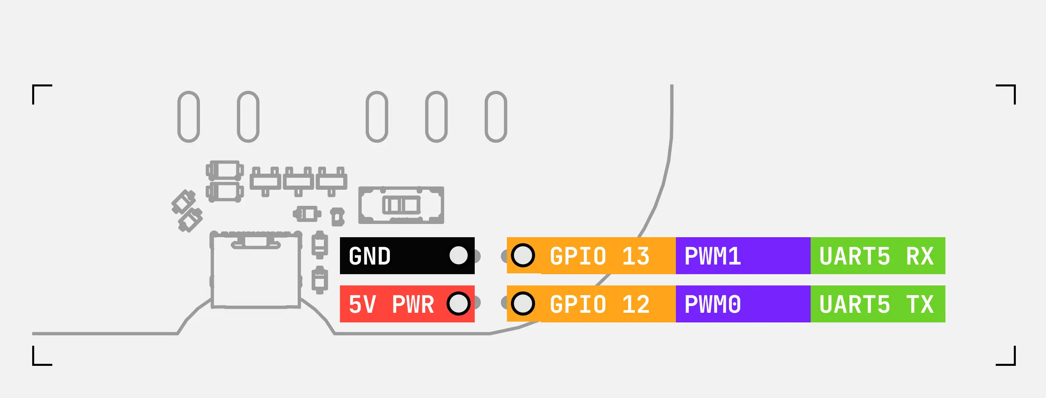
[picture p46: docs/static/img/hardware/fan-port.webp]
Fan Unit Port
        
    </TabItem>
</Tabs>

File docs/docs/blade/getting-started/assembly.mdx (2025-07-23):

---
sidebar_position: 1
---

# Assembly

When you get your Compute Blade, the box will include:
- Compute Blade
- Latch Lever
- Latch Anchor
- x2 M3x6 Screws
- M2x2.5 Screw
- M2x2.5 Standoff
- M2 Nylon Washer

## Out of  the Box

Removing the Blade from the box it will be wrapped in bubble wrap. The Latch and other hardware will be a separate bag in the box.

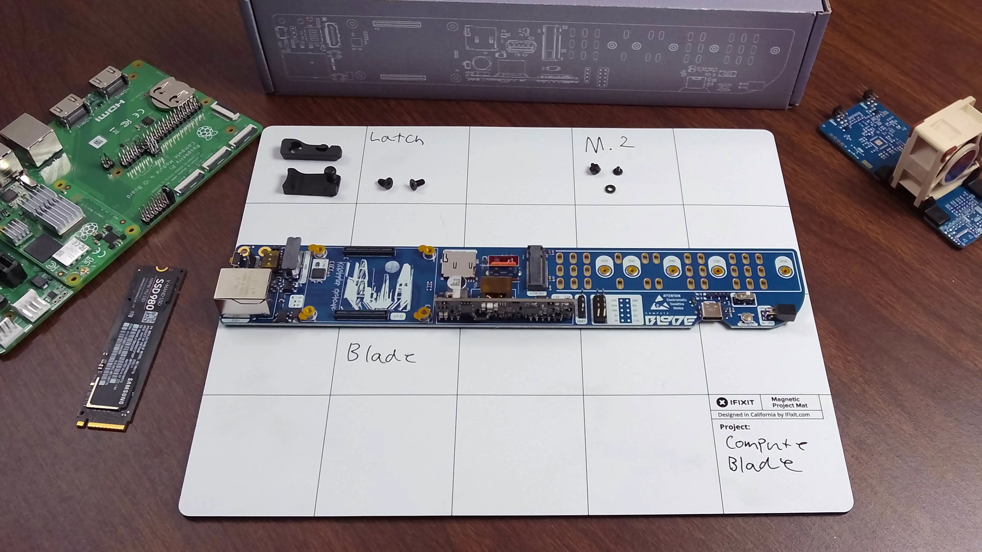
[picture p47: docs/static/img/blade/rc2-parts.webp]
Blade parts


From the factory the Blade will have Kapton tape on all of the threaded mounting points and the DIP Switches(if dev model). Remove the tape.

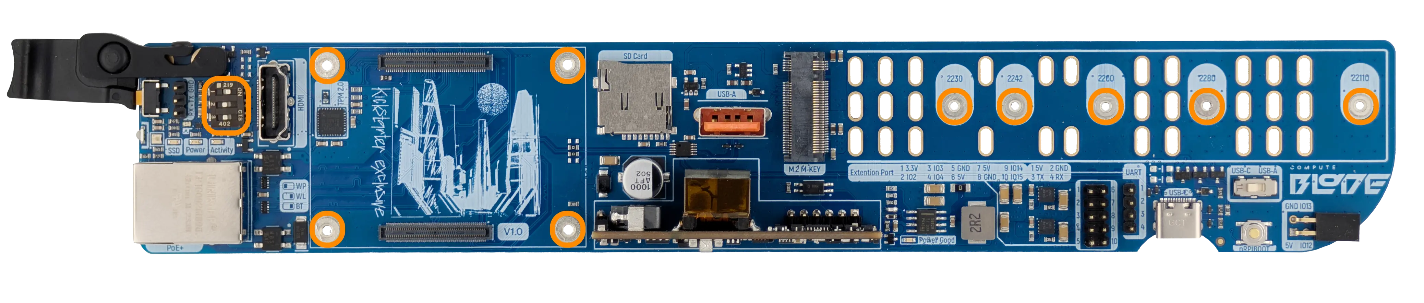
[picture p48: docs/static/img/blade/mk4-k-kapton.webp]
MK4 K blade with locations of Kapton tape marked


## Latch

The latch comes in two parts:

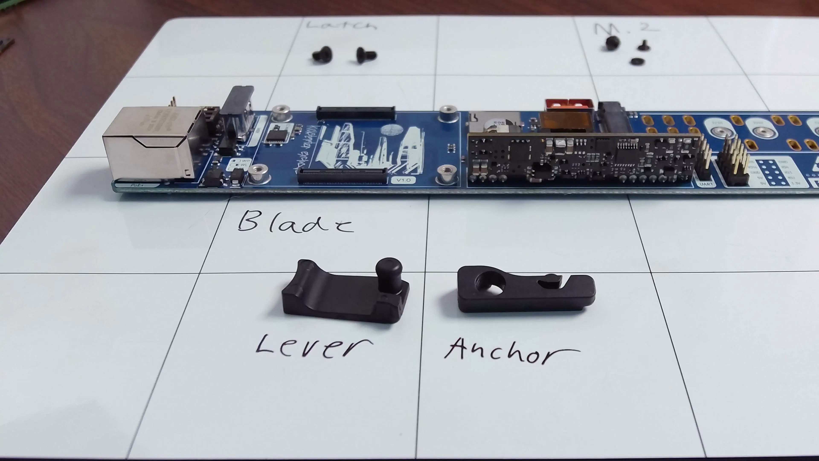
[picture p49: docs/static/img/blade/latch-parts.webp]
Parts for compute blade latch


To assemble the two parts place the "lever" with the flat side down, then place the "Anchor" with the two mounting holes facing the table as shown in the image above.
Next press firmly until the pieces snap together.

:::warning
Be sure to assemble the two parts correctly; it is difficult to separate them and can damage the latch.
:::

:::note
Models for the latches can be found on [GitHub](https://github.com/uptime-lab/compute-blade/tree/brushknight-patch-1/models/bladerunner/latch)
:::

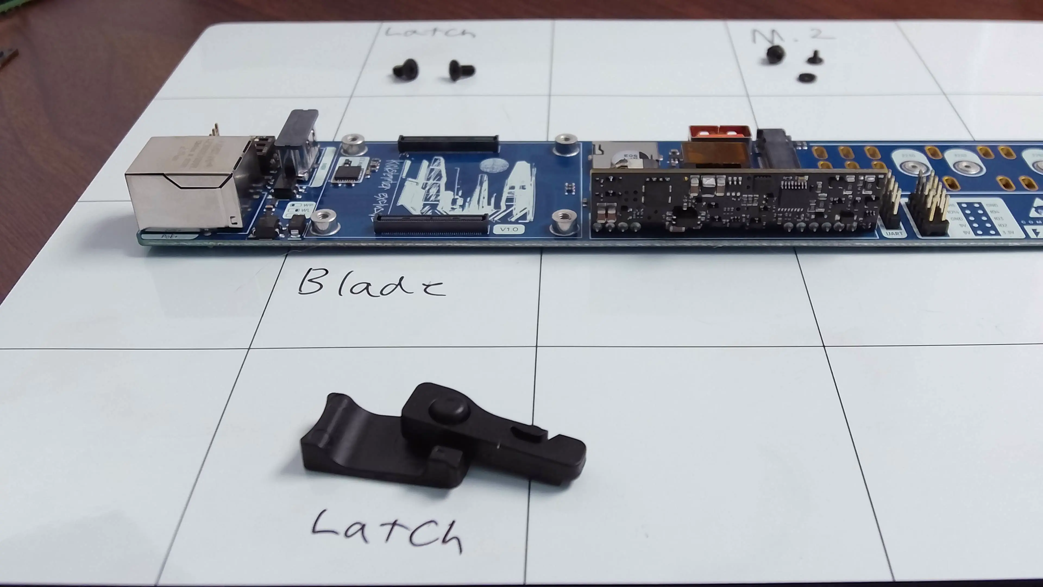
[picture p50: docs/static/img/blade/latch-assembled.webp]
Latch is now assembled


With the Latch assembled it can be secured to the blade. Using a PH1 screw driver, take the two M3x6 screws and secure the latch to the blade.

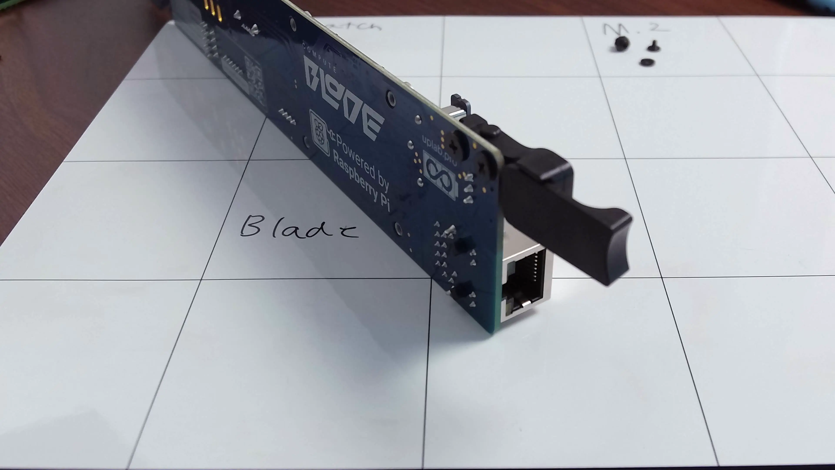
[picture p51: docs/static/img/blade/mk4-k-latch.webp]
Latch Attached to the MK4-K Blade


The latch is now assembled and attached to the Compute Blade.

## M.2 Slot

The Compute Blade has 1 M.2 M key slot for expansion, which supports devices from `2230` to `22110`. This slot can be used to for Storage, hardware accelerator, or even a GPU. 

:::tip
If you are unsure about which threaded insert to put the standoff in check the [M.2 Slot](/blade/guides/m2) page
:::

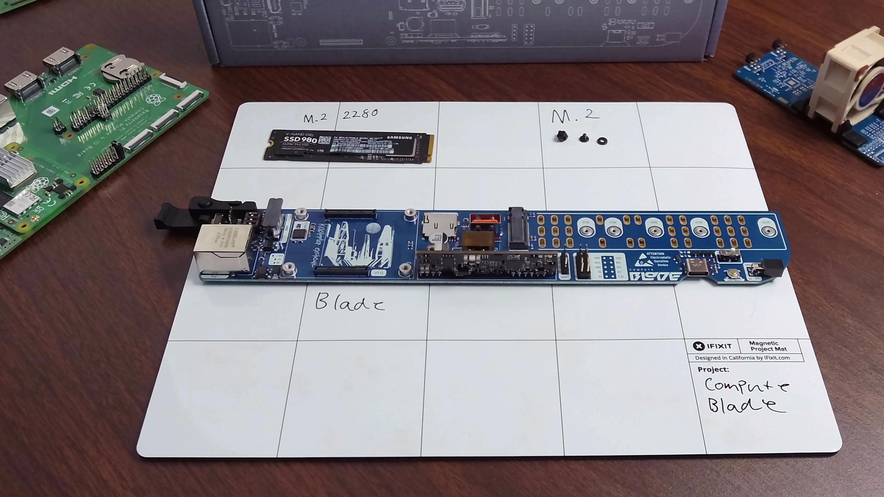
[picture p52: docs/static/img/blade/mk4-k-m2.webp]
MK4-k Blade with parts and Samsung SSD 980


To use the slot, screw the included M2x2.5 standoff into the threaded insert corresponding to the size of your M.2 device using a 5mm hex driver. The bellow picture shows a Samsung SSD 980 which is a `2280` M.2 M key device.

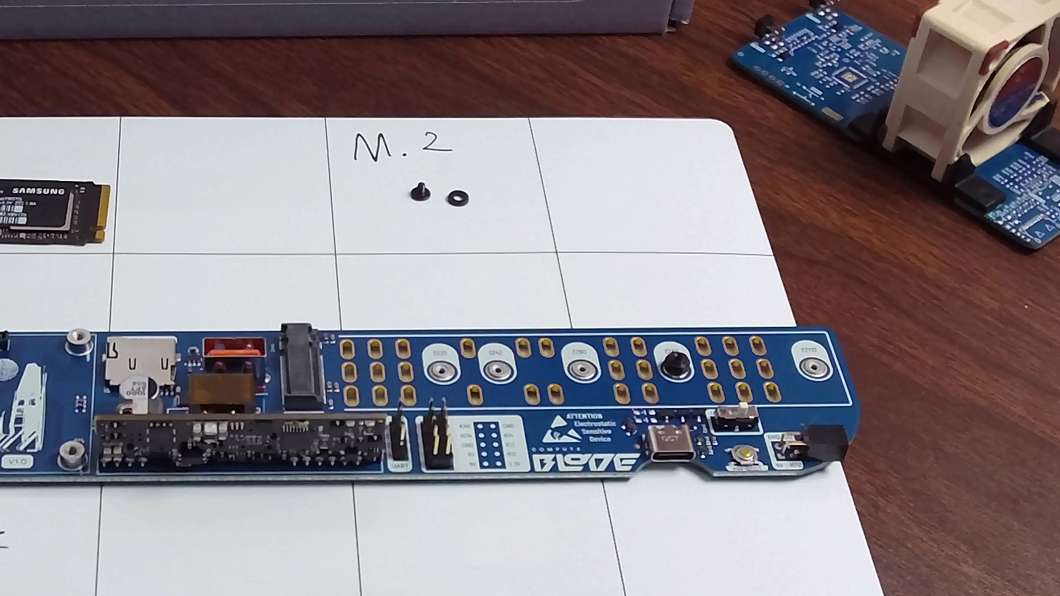
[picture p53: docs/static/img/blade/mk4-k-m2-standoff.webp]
MK4-K blade with standoff installed in the 2280 position


:::tip
If installing an NVMe SSD, you may want to install an Operating system first. See our [imaging guide](/blade/getting-started/image?boot=ssd)
:::

Place the M2 nylon washer on the M2x2.5 screw and insert the M.2 device at a 30° angle.

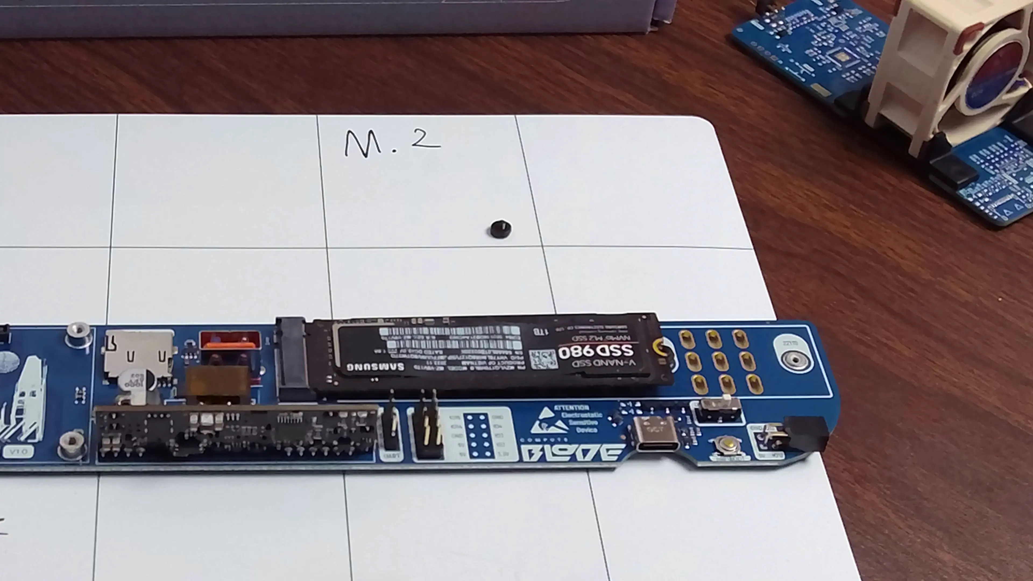
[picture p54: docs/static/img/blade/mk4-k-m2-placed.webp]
MK4-K blade with Samsung SSD 980 placed


Finally, using a PH1 driver secure the M2x2.5 screw with the M2 nylon washer to the standoff.

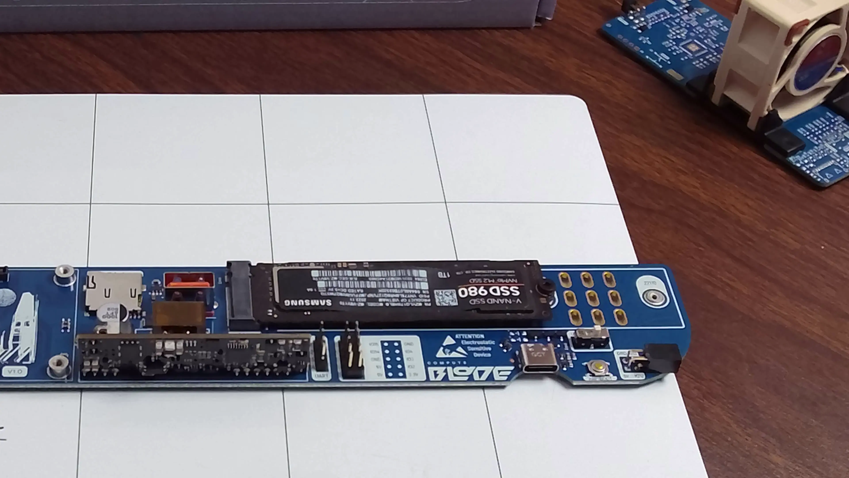
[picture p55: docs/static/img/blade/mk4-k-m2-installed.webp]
MK4-K blade with Samsung SSD 980 Installed


The M.2 device is now installed.

## Compute Module

The Compute Blade is built for the Raspberry Pi Compute Module 4(CM4) and Compute Module 5(CM5). 

:::warning
The Compute Blade is made for the CM4 / CM5; other compute modules may **NOT** work as intended on the Compute Blade as they are not officially validated.
:::

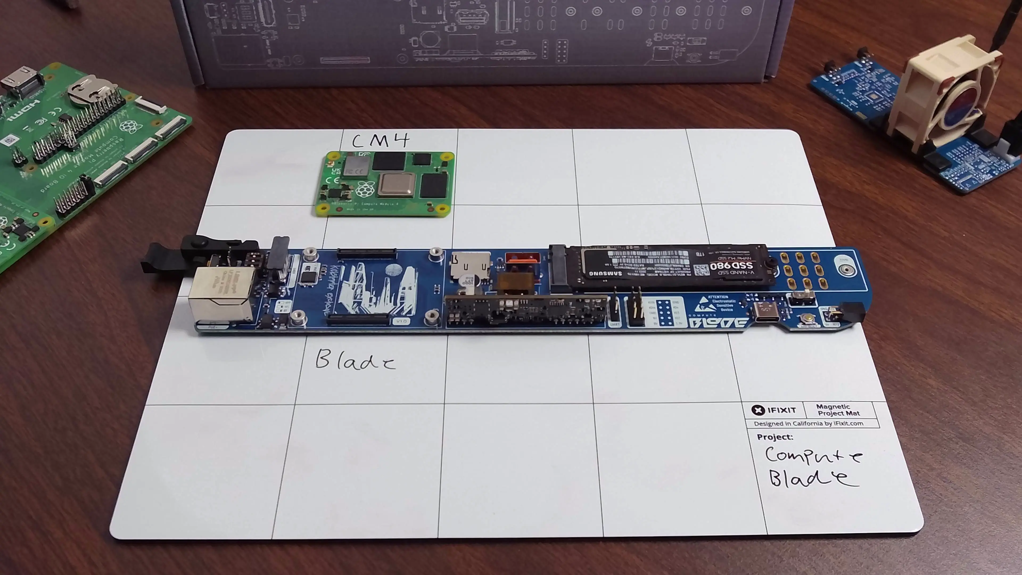
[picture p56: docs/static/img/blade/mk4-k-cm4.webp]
Blade with cm4 above


Align the compute module board to board connecter with the Compute Blade.

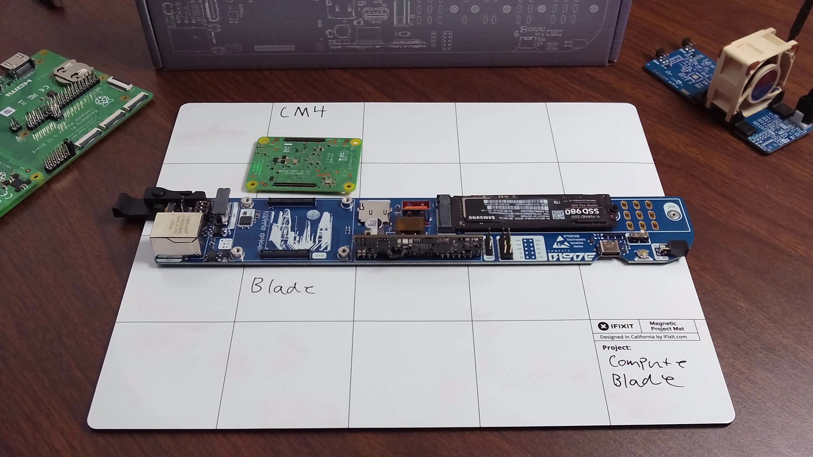
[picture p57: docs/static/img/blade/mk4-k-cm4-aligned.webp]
Blade with cm4 above and flipped over showing board to board connecter


Place the compute module onto the connector and press firmly.

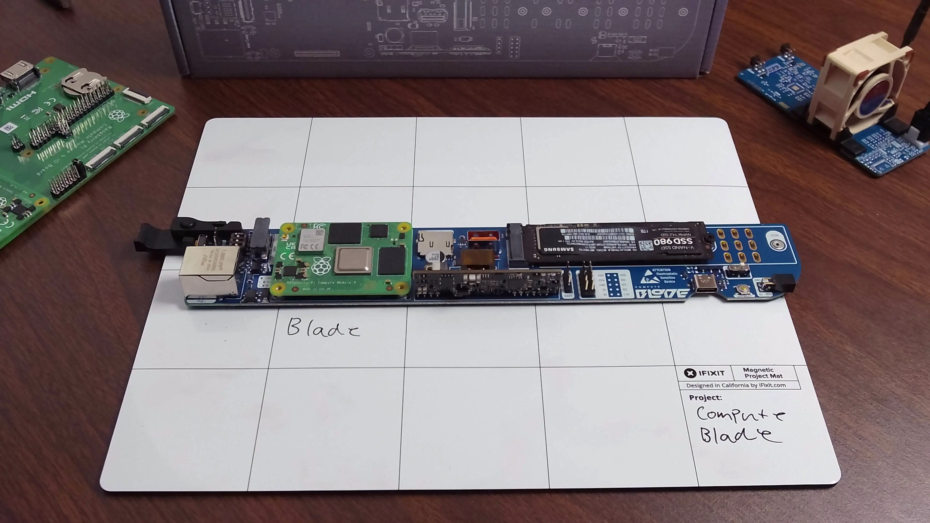
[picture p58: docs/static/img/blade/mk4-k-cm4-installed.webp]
Blade with CM4 installed


## Heat Sink

A heat sink is recommend to get the most out of your CM4 and is required for CM5. The Compute Blade Heat Sink is built to give your Compute Blade the best performance.

:::danger
Compute Bade Heatsink are currently not compatible with CM5
:::

Included in the box
- Heat Sink
- x4 M2.5x8 Screws
- Extra Thermal Pads

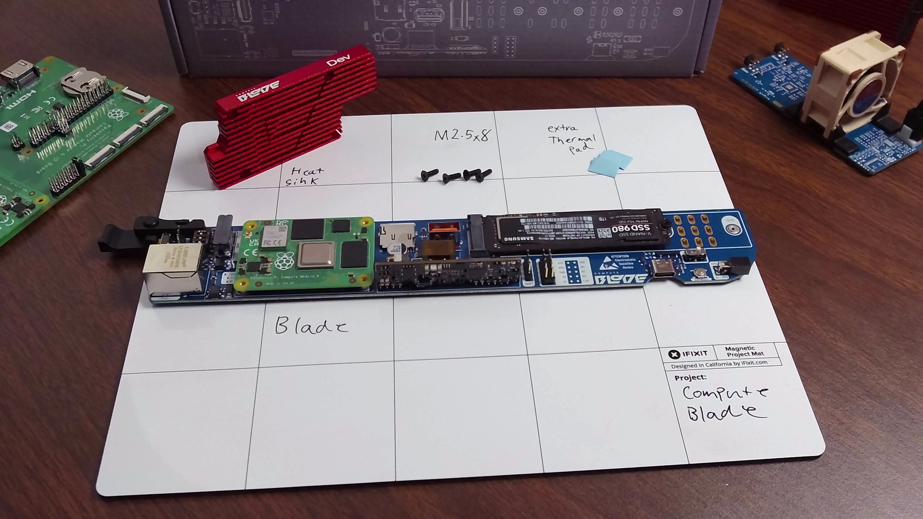
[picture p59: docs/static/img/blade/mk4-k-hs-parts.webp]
Compute Blade with Heat Sink parts


:::warning
To install the Heat Sink a Compute Module 4 must be installed first
:::

Remove the plastic from the pre-applied thermal pads.

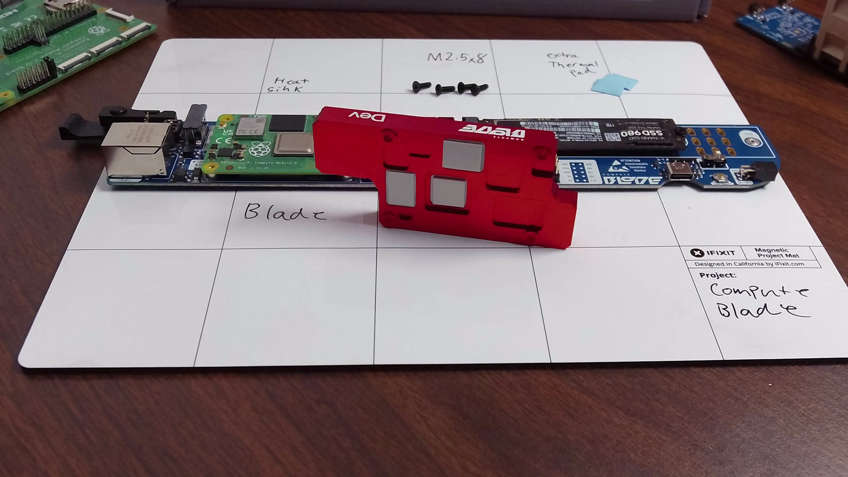
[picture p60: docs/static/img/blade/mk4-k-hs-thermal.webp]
Heat Sink with thermal pads highlighted


Place the heat sink on to the CM4. The text on the edge of the heat sink should be at the top of the blade.
The Heat sink can now be secured with the four included M2.5x8 screws. Using a PH1 screw driver, tighten the screws to secure the heat sink.

:::warning
Do not over tighten the screws. Over tightening will cause the Compute Module to bend.
:::

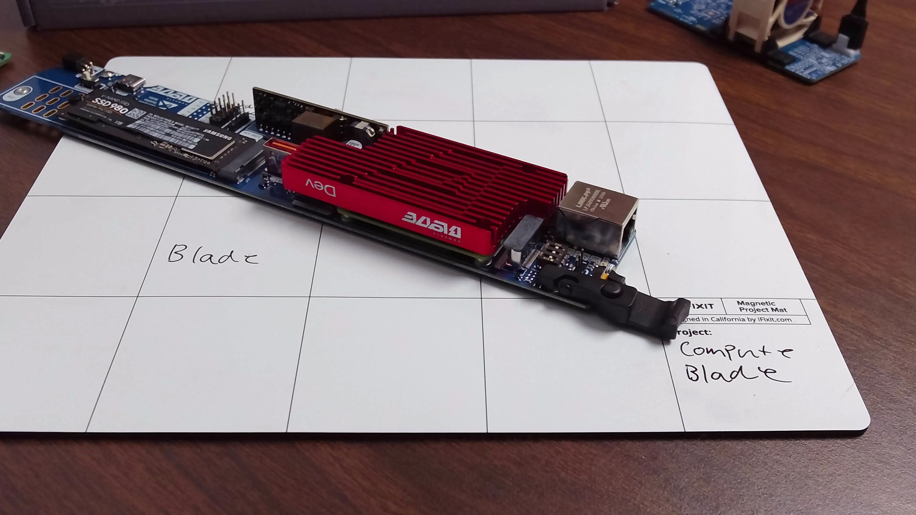
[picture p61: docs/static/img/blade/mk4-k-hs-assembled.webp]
Blade with Heat Sink attached


The Heat Sink is now fully installed.

## Fan Unit

If you would like to assemble a fan unit see our fan unit [instructions](/fan-unit/assembly)

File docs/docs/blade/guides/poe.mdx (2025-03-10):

---
sidebar_position: 2
---

import Tabs from '@theme/Tabs';
import TabItem from '@theme/TabItem';

# Power over Ethernet

The Compute Blade features support for PoE (`802.3af`), PoE+(`802.3at`), and PoE++(`802.3bt`).

## Power Consumption

Power consumption will vary based on load, accessories connected, and the power requirements of any devices installed in the M.2 slot.
During testing, a Compute Blade with a CM4 overclocked to 2GHz and a consumer NVMe SSD under load consumes ~7W. Normal operation may range from 3W to 17W depending on workload.

## PoE+ Indicator

On the Compute Blade, `GPIO23` is used to indicate the presence of PoE+ or PoE++. This could be used to modify the behavior of the blade depending to the supplied power.
There is an LED on the Blade with a `+` label indicating power state.

:::note
    `GPIO23` must be pulled up using the internal pull up.
:::

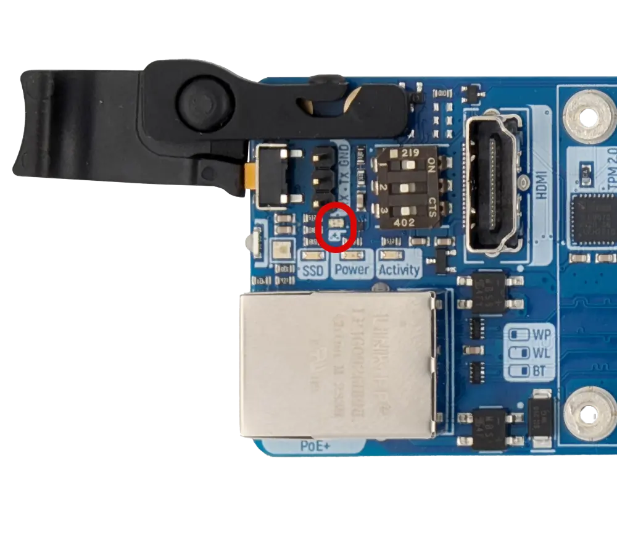
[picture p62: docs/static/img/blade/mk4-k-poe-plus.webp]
Compute Blade with PoE+ light identified


| LED Color | Description | GPIO 23  | Power |
|---|---|---|---|
| Green | 5 Volt present (PoE or USB) | **HIGH** | up to 15W |
| Orange | PoE+ or PoE++ present | **LOW**  | up to 30W |

### Accessing the PoE+ Status in Software

These are example of how to get the `GPIO23` state to determine the if PoE+ is present.

<Tabs groupId='code-lang'>
    <TabItem value="python" label="Python" default>

    ```py
    import RPi.GPIO as GPIO
    import time

    # Define the GPIO pin number for the PoE indicator
    POE_INDICATOR_GPIO = 23

    # Set the GPIO mode to the BCM pin numbers
    GPIO.setmode(GPIO.BCM)

    # Set GPIO to an input and pull up the line
    GPIO.setup(POE_INDICATOR_GPIO, GPIO.IN, pull_up_down=GPIO.PUD_UP)

    try:
        # Read the state of the GPIO pin
        button_state = GPIO.input(POE_INDICATOR_GPIO)

        # Check if the pin is active (assuming active-high logic)
        if button_state == True:
            print("Powersource: PoE+ or PoE++")
        else:
            print("Powersource: PoE or USB Type-C")
    except:
        GPIO.cleanup()
    ```
    </TabItem>
    <TabItem value="c" label="C" >
    ```c
    #include <stdio.h>
    #include <wiringPi.h>

    // Define the GPIO pin number for the PoE indicator
    #define POE_INDICATOR_GPIO 23

    int main(void) {
        // Initialize the wiringPi library
        if (wiringPiSetupGpio() == -1) {
            printf("wiringPi setup failed\n");
            return 1;
        }

        // Set the GPIO pin mode to input
        pinMode(POE_INDICATOR_GPIO, INPUT);

        // Read the state of the GPIO pin
        int poeIndicatorState = digitalRead(POE_INDICATOR_GPIO);

        // Check if the pin is active (assuming active-high logic)
        if (poeIndicatorState == HIGH) {
            printf("Powersource: PoE or USB Type-C\n");
        } else {
            printf("Powersource: PoE+ or PoE++\n");
        }

        return 0;
    }
    ```
    </TabItem>
</Tabs>

## PoE Modules
Different Compute Blade revisions use different PoE modules. See the table below:

| Version | PoE Module | Volts | Power Output (Peak) | PoE Compliance | Classification |
| :--- | :--- | :---- | :--- | :--- | :--- |
| v1.0 | [Silvertel Ag5405](https://silvertel.com/ag5400/) | 5V | 25.5W (30W) | IEEE [`802.3af`](https://standards.ieee.org/ieee/802.3af/1090/), [`802.3at`](https://standards.ieee.org/ieee/802.3at/4553/), [`802.3bt`](https://standards.ieee.org/ieee/802.3bt/6749/) | Type 2, Class 4 |

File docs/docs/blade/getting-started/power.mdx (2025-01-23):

---
sidebar_position: 2.5
---
# Powering the blade

The only way to power the Compute Blades is with Power over Ethernet(PoE). The exception to this is DEV model Blades which, in addition, has a USB Type-C port that can be used to deliver power.

## Power over Ethernet

To use a PoE you will need a PoE enabled injector or network switch.

:::tip
If you are unsure witch network switch to buy we have a list of [tested devices](/blade/compatibility/switch)
:::

Then connect the Ethernet cable from your PoE enabled device to the Blade. This cable will provide power and network to the blade.

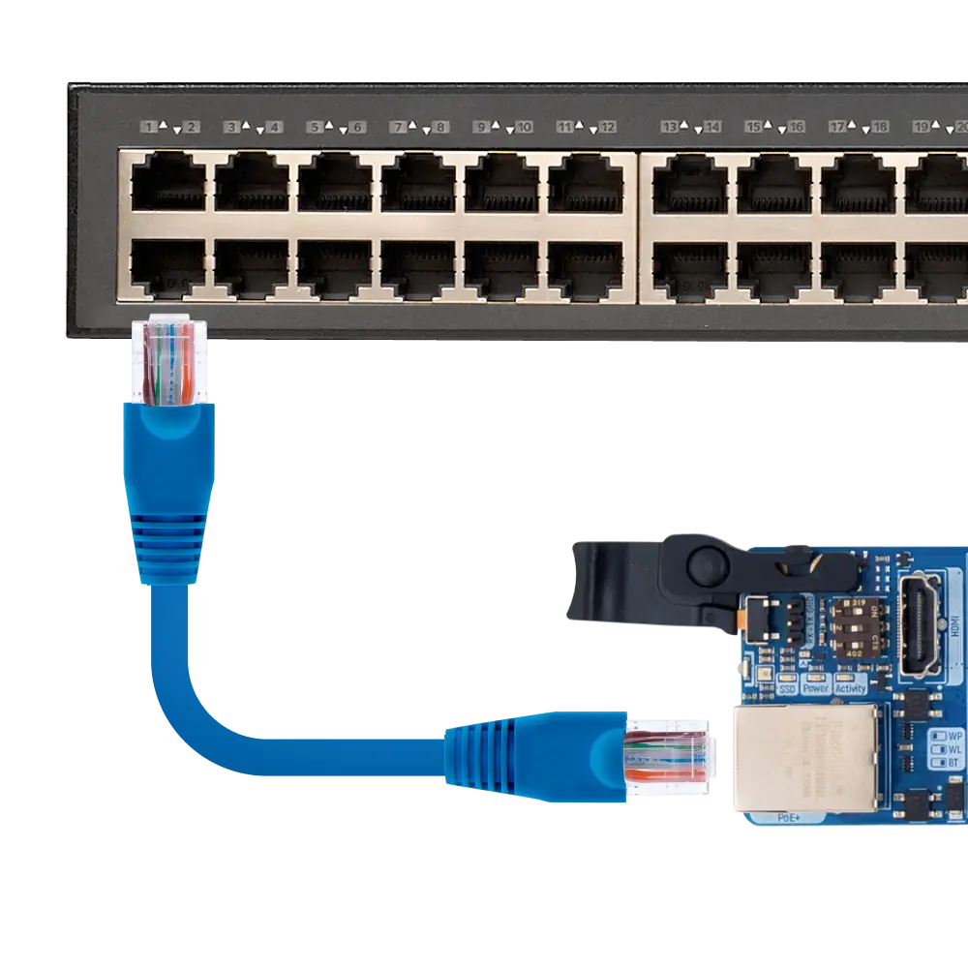
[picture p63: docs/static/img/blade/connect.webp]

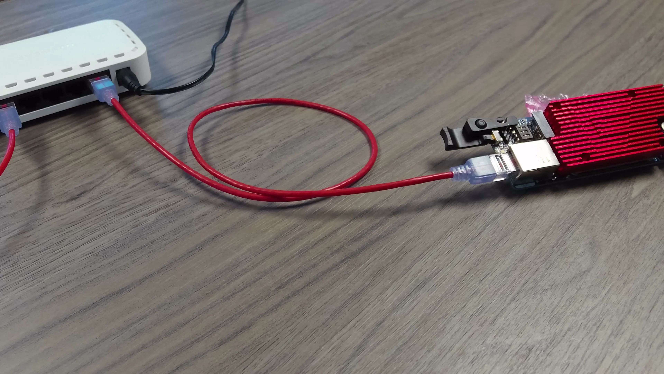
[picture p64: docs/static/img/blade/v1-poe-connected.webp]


:::tip
Some devices may have PoE and non-PoE ports be sure to follow your device manufacturers instructions to avoid issues
:::
:::warning
If you are using a [BladeRunner](/bladerunner/) enclosure only PoE is a support power option
:::

:::note
For more information on PoE see our dedicated [PoE page](/blade/guides/poe)
:::

## USB
:::warning
Only the Dev model Compute Blade has a USB Type-C port.
:::

Dev Blades can be powered over USB Type-C in addition to PoE. When using USB power make sure the USB power supply can provided at least 2A at 5V.

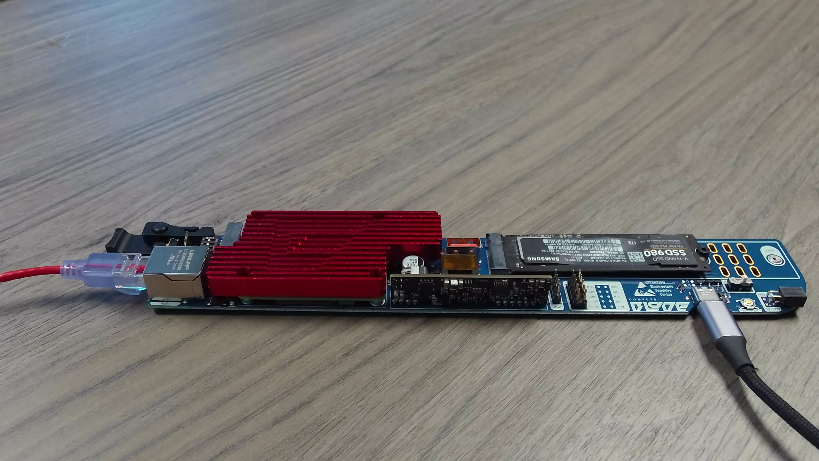
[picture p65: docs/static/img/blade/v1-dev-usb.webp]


The USB Type-C port does not provided network connectivity. Use an Ethernet cable to connect the blade to your network.

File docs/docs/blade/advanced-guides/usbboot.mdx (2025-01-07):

import Tabs from '@theme/Tabs';
import TabItem from '@theme/TabItem';
import Admonition from '@theme/Admonition';

# How to Use USB Device Boot Code

[USB device boot code](https://github.com/raspberrypi/usbboot) is an application provided by Raspberry Pi to push firmware to Compute Modules.
Raspberry Pi does not provide precompiled binaries for the software so it must be compiled.

## Installation

<Tabs groupId='system'>
    <TabItem value="linux" label="Linux / Cygwin / WSL" default >
        <Admonition type="warning">
            The git repository uses [symlinks](https://en.wikipedia.org/wiki/Symbolic_link).
            For Windows builds clone the repository under [Cygwin](https://www.cygwin.com/)
            or use [Windows Subsystem for Linux](https://learn.microsoft.com/en-us/windows/wsl/) (WSL)
        </Admonition>
        1. Install software from package manager `git`, `libusb-1.0-0-dev`, `pkg-config`, `build-essential`
        2. Clone the `usbboot` repository
        3. Build using make
        4. Run the binary

        ```bash
        sudo apt install git libusb-1.0-0-dev pkg-config build-essential
        git clone --recurse-submodules --shallow-submodules --depth=1 https://github.com/raspberrypi/usbboot
        cd usbboot
        make
        sudo ./rpiboot
        ```
        <Admonition type="tip">
            `sudo` isn't required if you have write permissions for the `/dev/bus/usb` device.
        </Admonition>

        <details>
            <summary>Connect USB devices to WSL</summary>

            If using [WSL](https://learn.microsoft.com/en-us/windows/wsl/) additional setups are required to connect USB devices.
            
            This is outside the scope of this guide, see Microsoft's [documentation](https://learn.microsoft.com/en-us/windows/wsl/connect-usb).
            For a graphical user interface see [WSL USB Manager](https://gitlab.com/alelec/wsl-usb-gui) by [Andrew Leech](https://gitlab.com/andrewleech).

        </details>

    </TabItem>
    <TabItem value="macos" label="MacOS">

        1. Clone the `usbboot` repository
        2. Install `libusb` (`brew install libusb`)
        3. Install `pkg-config` (`brew install pkg-config`)
        4. (Optional) Export the `PKG_CONFIG_PATH` so that it includes the directory enclosing `libusb-1.0.pc`
        5. Build using make
        6. Run the binary

        ```bash
        git clone --recurse-submodules --shallow-submodules --depth=1 https://github.com/raspberrypi/usbboot
        cd usbboot
        brew install libusb
        brew install pkg-config
        make
        sudo ./rpiboot
        ```
        <Admonition type="tip">
            If the build is unable to find the header file `libusb.h` then most likely the `PKG_CONFIG_PATH` is not set properly.
            This should be set via export `PKG_CONFIG_PATH="$(brew --prefix libusb)/lib/pkgconfig"`.
        </Admonition>
        <details>
            <summary>If the build fails on an ARM-based Mac with a linker error</summary>

            If the build fails on an ARM-based Mac with a linker error such as `ld: warning: ignoring file /usr/local/Cellar/libusb/1.0.26/lib/libusb-1.0.dylib`,
            building for macOS-arm64 but attempting to link with file built for `macOS-x86_64` then you may need to build and install `libusb-1.0` yourself:

            ```bash
            wget https://github.com/libusb/libusb/releases/download/v1.0.26/libusb-1.0.26.tar.bz2
            tar -xf libusb-1.0.26.tar.bz2
            cd libusb-1.0.26
            ./configure
            make
            make check
            sudo make INSTALL_PREFIX=/usr/local install
            ```
            Running `make` again should now succeed.
        </details>
    </TabItem>
</Tabs>

### Updating the rpi-eeprom submodule
After updating the usbboot repo (`git pull --rebase origin master`) update the submodules by running

```bash
git submodule update --init
```

## Editing the config
The firmware configurations can be edited in the file `/usbboot/<firmware directory>/config.txt`

### Boot Order
The `BOOT_ORDER` field allows the configuration of which boot device is used.

```txt
# Tries to boot from NVMe, then SD Card, then network, then loops to the start
BOOT_ORDER=0xf216
```

| Value	| Mode | Description |
| :---: | :---: | :--- |
| 0x0 | SD CARD DETECT | Try SD then wait for card-detect to indicate that the card has changed. Deprecated now that 0xf (RESTART) is available. |
| 0x1 | SD CARD | SD card (or eMMC on Compute Module 4). |
| 0x2 | NETWORK | Network boot - See Network boot server tutorial. |
| 0x3 | RPIBOOT | RPIBOOT - See usbboot. |
| 0x4 | USB-MSD | USB mass storage boot - See USB mass storage boot. |
| 0x5 | BCM-USB-MSD | USB 2.0 boot from USB Type C socket (CM4: USB type A socket on CM4IO board). Not available on Raspberry Pi 5. |
| 0x6 | NVME | CM4 and Pi 5 only: boot from an NVMe SSD connected to the PCIe interface. See NVMe boot for more details. |
| 0x7 | HTTP | HTTP boot over ethernet. See HTTP boot for more details. |
| 0xe | STOP | Stop and display error pattern. A power cycle is required to exit this state. |
| 0xf | RESTART | Restart from the first boot-mode in the BOOT_ORDER field i.e. loop. |

*Table from Raspberry Pi [documentation](https://www.raspberrypi.com/documentation/computers/raspberry-pi.html#boot_order-fields)*

## Additional Resources

If you are having difficulty here are some more resources to help:

- [How to update the Raspberry Pi Compute Module 4 Bootloader / EEPROM](https://www.jeffgeerling.com/blog/2022/how-update-raspberry-pi-compute-module-4-bootloader-eeprom) | Jeff Geerling
- [Flash Compute Module bootloader EEPROM](https://www.raspberrypi.com/documentation/computers/compute-module.html#compute-module-eeprom-bootloader) | Raspberry Pi Documentation

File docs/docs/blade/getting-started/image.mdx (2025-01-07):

---
sidebar_position: 1
---

import Tabs from '@theme/Tabs';
import TabItem from '@theme/TabItem';
import Admonition from '@theme/Admonition';

# Imaging Storage Media

You can boot the Raspberry Pi Compute Module 4 (CM4) and Compute Module 5 (CM5)in several ways on the Compute Blade

:::note
Pre-boot eXecution Environment(PXE) is a process to boot a computer over the network. It will not be covered here. See our [dedicated guide](/blade/advanced-guides/pxe-booting/) for more information
:::

## Prepare Storage Media

To prepare a storage medium you will need another computer.

<Tabs groupId="boot" defaultValue="ssd">
    <TabItem value="microsd" label="microSD Card" >
        <Admonition type="warning">
            Only the Dev model Compute Blade has a microSD Card slot
        </Admonition>
        <Admonition type="note">
            CM4s with part number `CM4XXX000` must be used as others have eMMC and are unable to use MicroSD Card slot
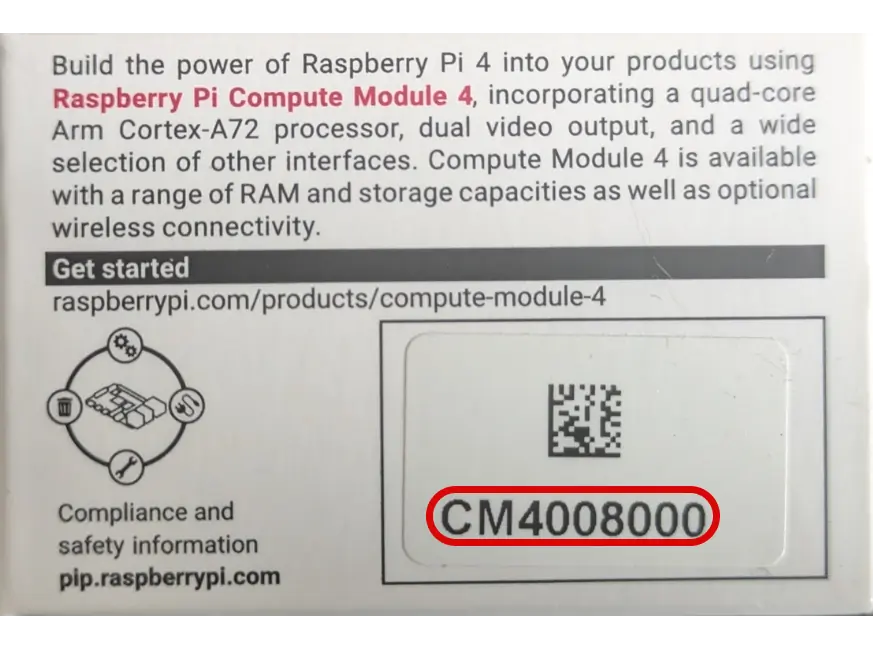
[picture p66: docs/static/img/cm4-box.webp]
CM4 box with model number highlighted
            
        </Admonition>
        The microSD Card needs to be at least 8GB. Your computer may not have a microSD Card slot and need an adapter.
    </TabItem>
    <TabItem value="ssd" label="SSD">
        <Admonition type="warning">
            The Compute Blade supports M key and B+M key M.2 devices, from size `2230` to `22110`
        </Admonition>
        The Compute Blade has a M.2 M key which supports both SATA and NVMe Solid State Drives(SSD).
        The M.2 SSD can be imaged the same as the microSD card but requires a USB to M.2 NVME/SATA Adapter, such as the [UGREEN M.2 NVMe SSD Enclosure Adapter](https://www.ugreen.com/collections/hard-drive-enclosure/products/ugreen-m-2-nvme-ssd-enclosure-adapter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).
    </TabItem>
    <TabItem value="emmc" label="eMMC">
        <Admonition type="warning">
            eMMC can only be imaged on Dev blade as it has USB Type-C port, USB switch, and `nRPIBOOT` button
        </Admonition>
        <Admonition type="note">
            CM4s with part number `CM4XXX000` do **NOT** have eMMC and are referred to as lite.

            CM4 box with model number highlighted
        </Admonition>
        Install [usbboot](/blade/advanced-guides/usbboot)
        From the usbboot directory run
        ```bash
        sudo ./rpiboot
        ```

        Move the USB switch to the USB Type-C position.
        Then, while holding down the `nRPIBOOT` button on the blade connect the USB Type-C cable.

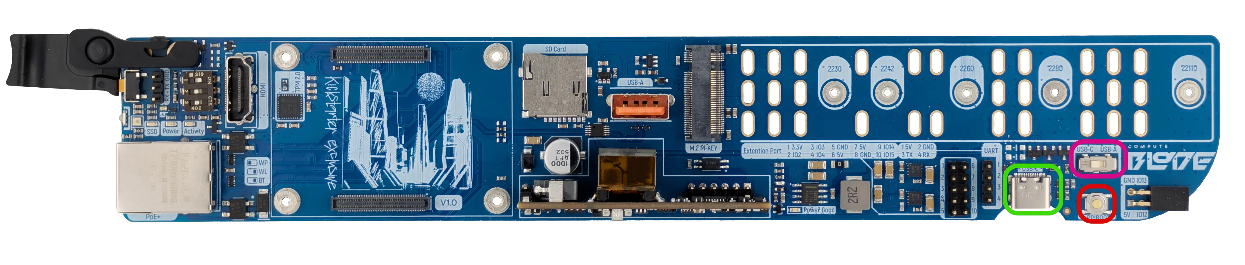
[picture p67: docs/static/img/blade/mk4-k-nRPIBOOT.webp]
Compute Blade with USB Type-C and nRPIBOOT button highlighted
        

        The Device will reconnect several times. On the last time it will appear as a USB media device.
    </TabItem>
</Tabs>

Download and install [Raspberry Pi Imager](https://www.raspberrypi.com/software/). After installing run it. This software will be used to image the storage media.

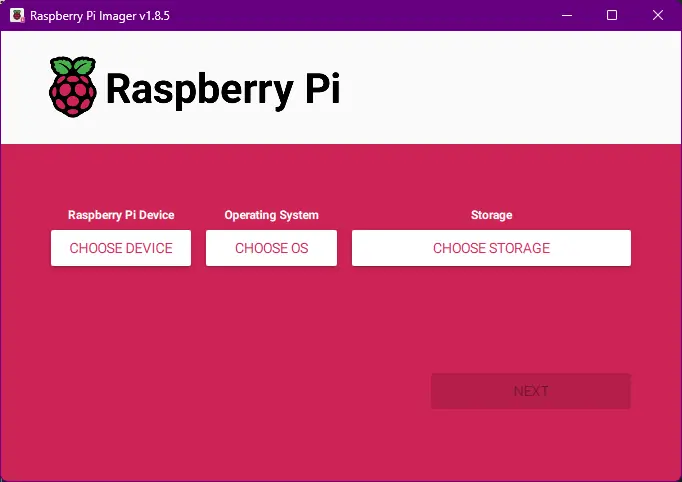
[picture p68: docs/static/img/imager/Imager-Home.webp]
Raspberry Pi Imager Home


Select Raspberry Pi 4

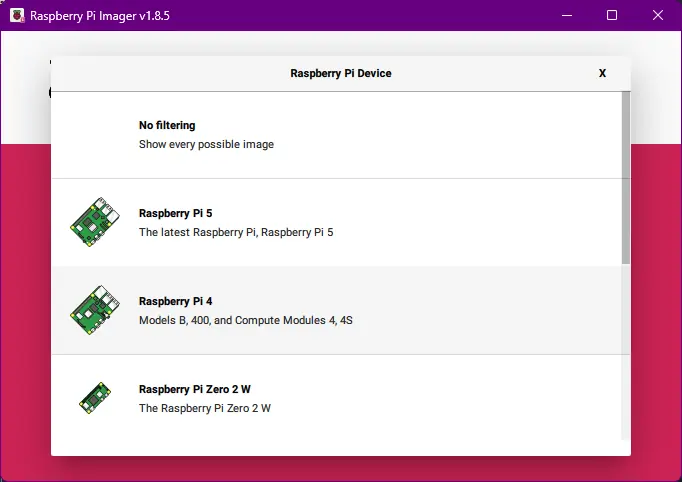
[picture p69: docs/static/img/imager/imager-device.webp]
Raspberry Pi Imager Device Filter


Select an operating system. We recommend Ubuntu Server 24.04 LTS (64-bit) `Operating System > Other general-purpose OS > Ubuntu > Ubuntu Server 24.04 LTS (64-bit)`

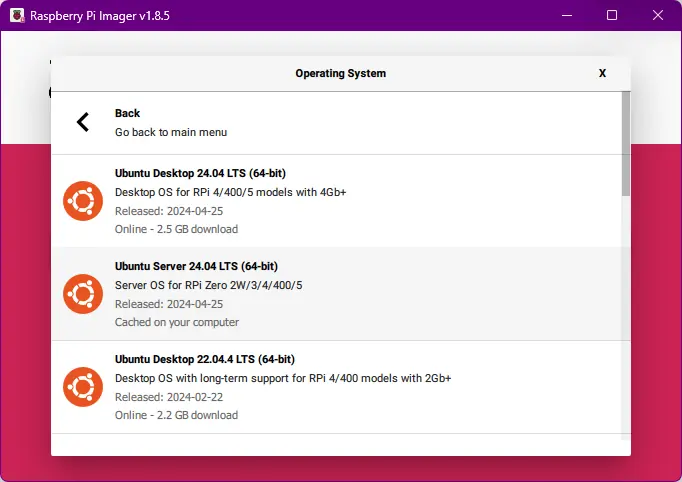
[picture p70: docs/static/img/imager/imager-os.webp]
Raspberry Pi Imager OS


Select storage media

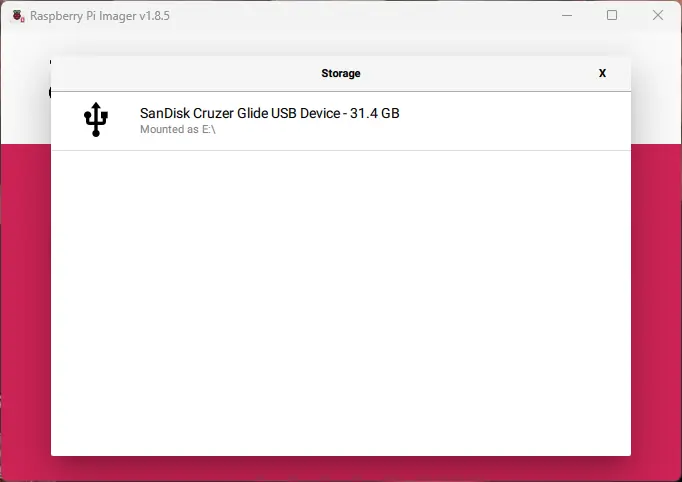
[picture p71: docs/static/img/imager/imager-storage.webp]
Raspberry Pi Imager storage


Click the `NEXT` then click the `EDIT SETTINGS` button. Two settings need to be edited.

- `GENERAL > Set hostname` - This name will be used to connect to your blade later
- `GENERAL > Set username and password` - Use your own username and password
- `GENERAL > Set locale setting`(Optional) - Set the blade locale setting

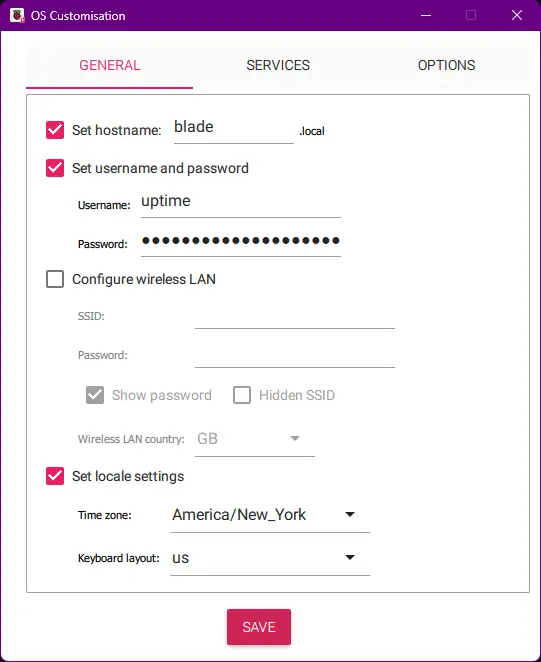
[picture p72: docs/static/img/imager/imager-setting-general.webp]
Raspberry Pi Imager setting general


`SERVICES > Enable SSH` - Use password authentication
<Admonition type="info">
    `Allow public-key authentication only` is the more secure option, but is more complex to set up. Read more in our [SSH guide](/blade/getting-started/connect/#public-key-authentication)
</Admonition>

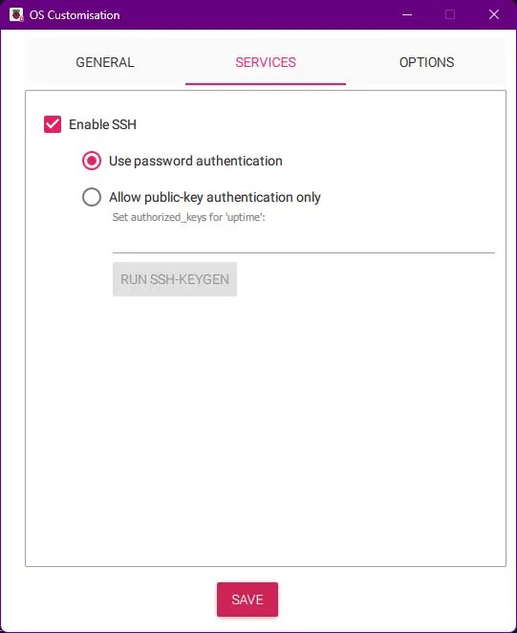
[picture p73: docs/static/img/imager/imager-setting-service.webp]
Raspberry Pi Imager setting service


Then click `SAVE`

Finally click `YES` and confirm that all existing data on the storage device will be erased by clicking `YES` again.
Raspberry Pi Imager will begin to write the OS to the storage device.

Once completed remove the storage device from the computer.

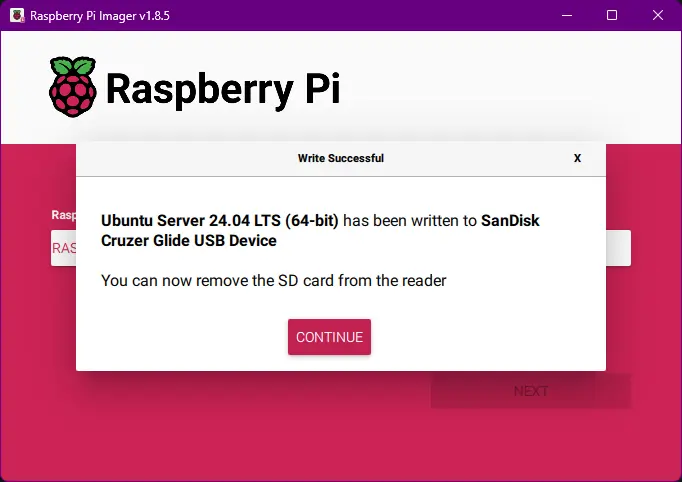
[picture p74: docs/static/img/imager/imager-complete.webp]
Raspberry Pi Imager Complete


## Install Storage Media in Blade

<Tabs groupId="boot" defaultValue="ssd" queryString="boot">
    <TabItem value="microsd" label="microSD Card" >
        <Admonition type="warning">
            Only the Dev model Compute Blade has a microSD Card Slot.
        </Admonition>
        Next to the top right corner of the CM4 you will find the microSD card slot. Insert the card with the pins facing down.
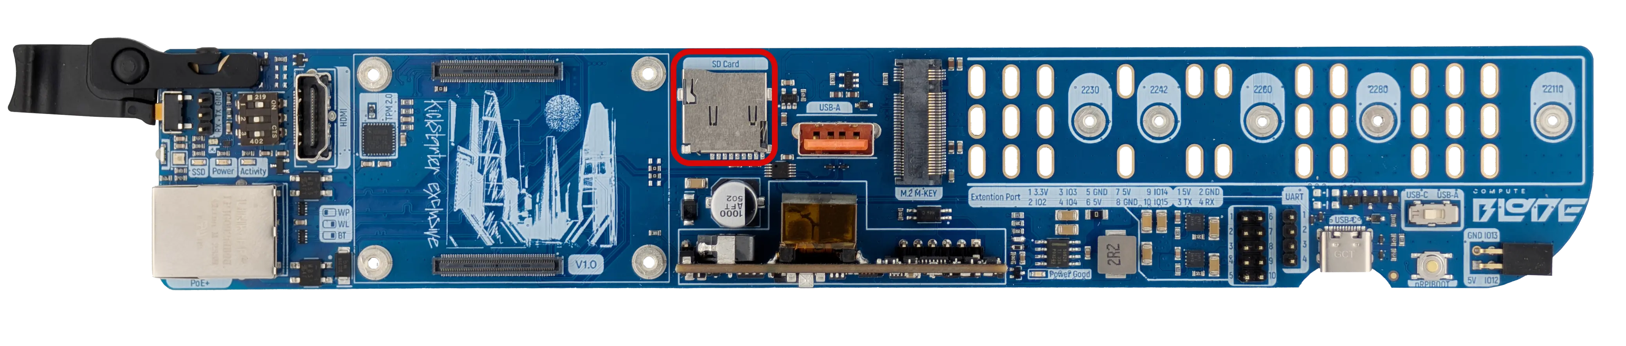
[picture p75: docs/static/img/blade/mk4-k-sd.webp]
Compute Blade mk4 sd card slot
        
    </TabItem>
    <TabItem value="ssd" label="SSD">
        <Admonition type="note">
            see [Assembly section](/blade/getting-started/assembly#m2-slot) for installation images
        </Admonition>

        1. Remove the Kapton tape from the standoff mount (If this has not already been done)
        2. Using a 5mm hex driver, attach the standoff to the the location corresponding to your drives size
        3. Insert the M.2 SSD at a 30° angle and press down
        4. Place the M2 nylon washer on the M2x2.5 screw and install using a PH1 driver to retain the M.2 SSD

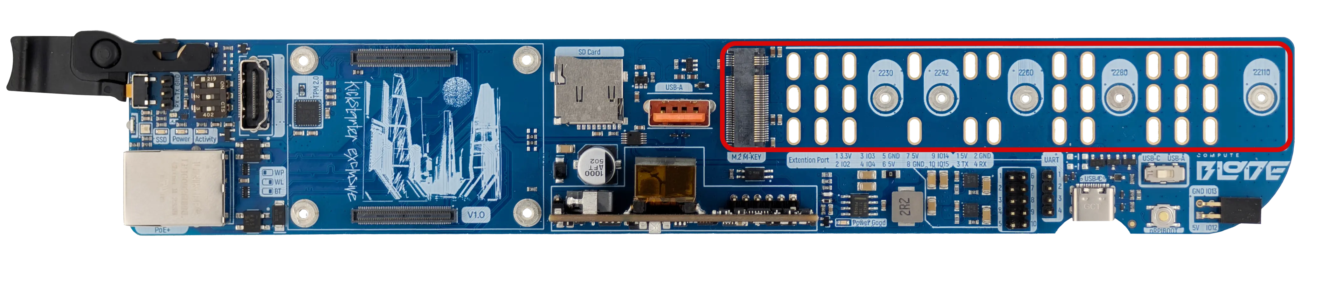
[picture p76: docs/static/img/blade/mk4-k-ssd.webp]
Compute Blade mk4 ssd slot
        
    </TabItem>
    <TabItem value="emmc" label="eMMC">
        Unplug the USB Type-C cable from the Compute Blade and set the switch to USB-A

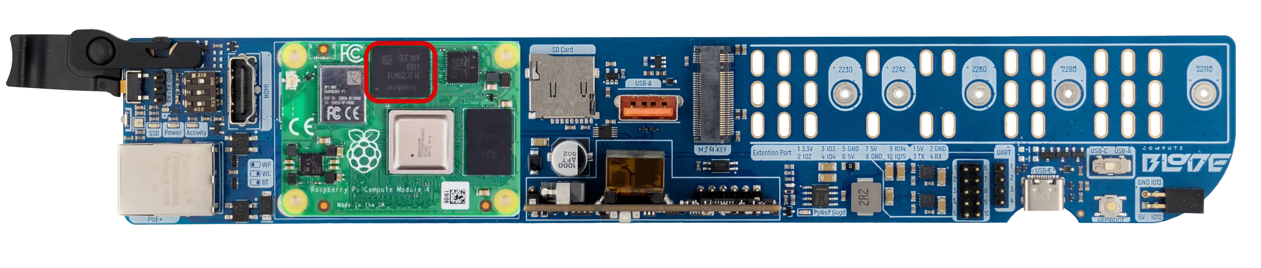
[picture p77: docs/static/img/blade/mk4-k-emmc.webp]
Compute Blade mk4 eMMC chip
        
    </TabItem>
</Tabs>

Your Blade is now ready to be powered on.

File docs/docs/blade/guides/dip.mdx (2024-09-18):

# DIP Switchs

:::info
    DIP Switch is **ONLY** populated on Dev model Compute Blades.
:::

## Switch States

:::danger
    Only change switch positions when the Blade is unplugged from power.
:::

| Switch | Left | Right  |
| :--- | :---: | :---: |
| 1 - Write Protection | Disabled | Enabled  |
| 2 - Wi-Fi | Enabled  | Disabled |
| 3 - Bluetooth | Enabled  | Disabled |

## Write Protection

To enable write protection, changes are required to [`config.txt`](https://www.raspberrypi.com/documentation/computers/config_txt.html#eeprom_write_protect).
It can be found in the directory `/boot/firmware/`, or flash the EEPROM using [usbboot](/blade/advanced-guides/usbboot)
adding the following line to the `config.txt` file
```txt
eeprom_write_protect=1
```

This will pull the `EEPROM_nWP` pin low. This will enable the DIP switch.

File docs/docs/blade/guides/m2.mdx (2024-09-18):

# M.2 Slot

The Compute Blade has 1 M.2 M key slot for expansion. This slot can be used to for Storage, hardware accelerator, or even a GPU.

## Sizes
The Compute Blade support all M.2 Sizes
- 22 mm × 30 mm

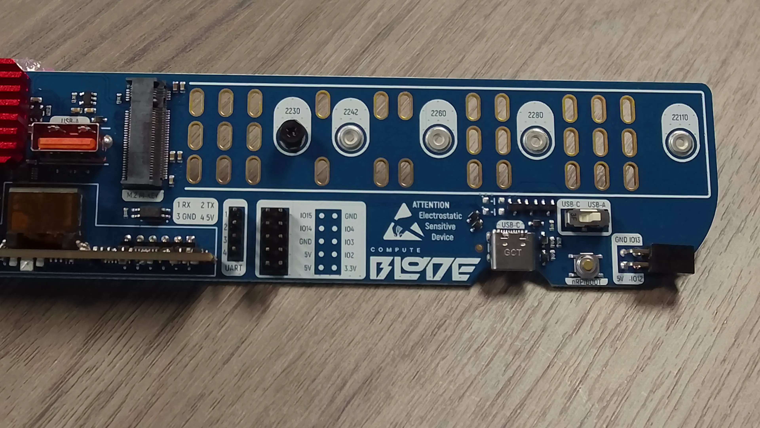
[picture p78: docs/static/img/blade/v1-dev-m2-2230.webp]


- 22 mm × 42 mm

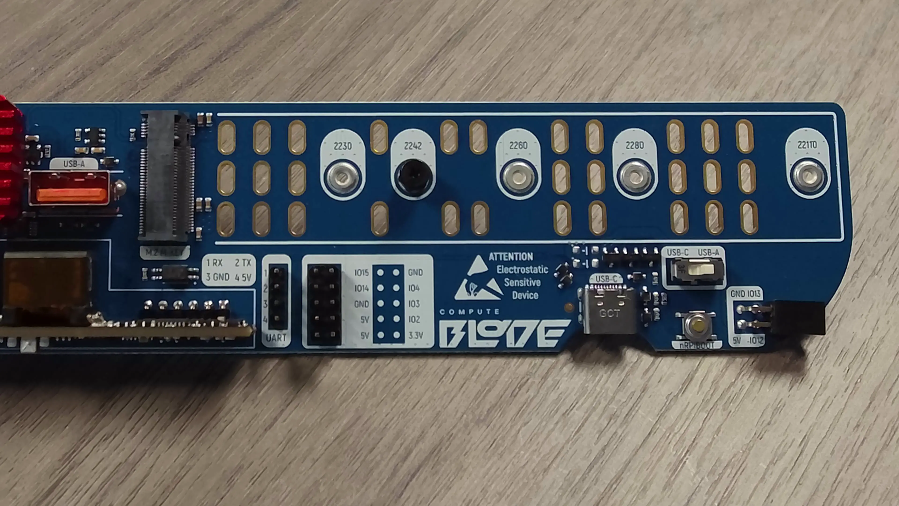
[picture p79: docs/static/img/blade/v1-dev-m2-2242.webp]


- 22 mm × 60 mm

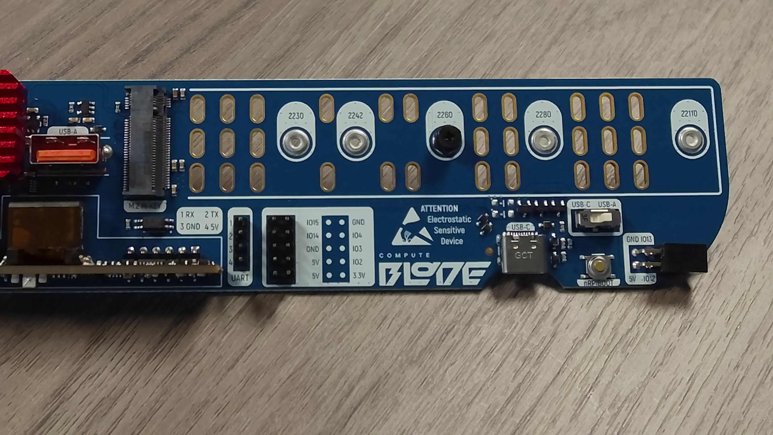
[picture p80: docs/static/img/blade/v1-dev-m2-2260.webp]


- 22 mm × 80 mm

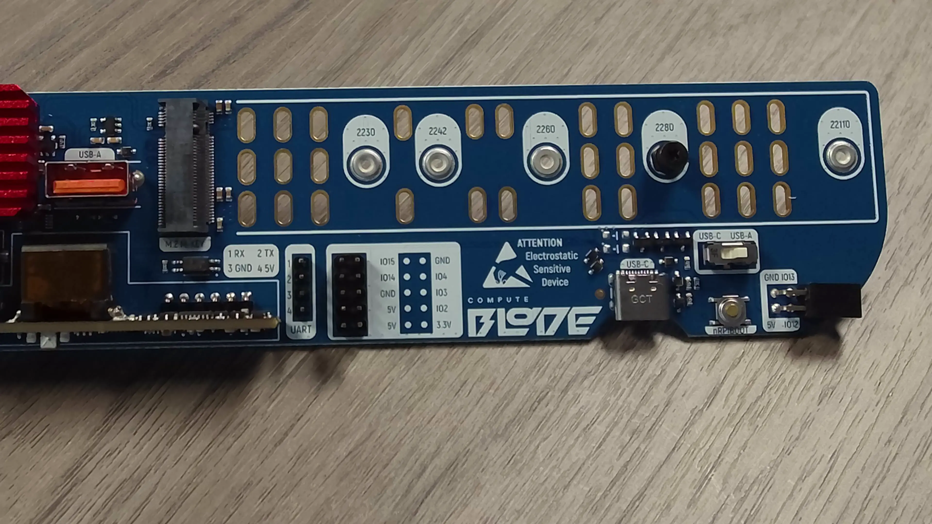
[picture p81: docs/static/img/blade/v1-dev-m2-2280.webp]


- 22 mm × 110 mm



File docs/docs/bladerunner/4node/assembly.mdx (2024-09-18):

# Assembly

The 4-node BladeRunner™️ toolless allowing the quick replacement of part in the event of a failure. It is able to contain 4 Compute Blades and 2 Fan Units

4-node BladeRunner with 4 dev Compute Blade and 2 Fan Units

## Fan Unit

The 4-node BladeRunner™️ is designed with the Fan Unit in mind

2 4-node BladeRunner next to each other

Insert the Fan Unit into the back of the 4-node BladeRunner™️ Making sure the fan unit is under the small catch. 
The The fan unit will snap into place with the fan seated just inside the 4-node BladeRunner™️

2 4-node BladeRunner next to each other

## Compute Blade

The Compute bade are inserted in to the front of the 4-node BladeRunner™️, align the blade with the groves

:::warning
If the blade does not slide all the way back, It is possibles for the fan connecter to become misallied. Check that the Fan unit is Full Seated in to the blade runner. Then are full re-insert the Compute Blade.
:::

4 Compute Blades in 4-node BladeRunner™️

## Power

The 4-Node bladeRunner can only be powered using Power over Ethernet(PoE). It is recommended that a PoE enabled network switch be used. Refer to the [Power section](/blade/getting-started/power) of getting started to connect PoE to the blade.

## Expanding

4-node BladeRunner™️ can be joined together to create a larger enclosure

:::warning
The tolerances on the 4-node BladeRunner™️ use a tight friction fit and a rubber melt be require to assemble and disassemble
:::

2 4-node BladeRunner next to each other
2 4-node BladeRunner joined to each other

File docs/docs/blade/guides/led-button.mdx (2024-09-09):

---
sidebar_position: 3
---

import Tabs from '@theme/Tabs';
import TabItem from '@theme/TabItem';

# LED & Button Control

The blade has two digital LEDs mounted in series. A square yellow LED is located on the top of the board, and a green LED is located on the edge.
The LEDs can be controlled via `GPIO18`.
:::info
You'll need to install the [Adafruit_Blinka](https://learn.adafruit.com/circuitpython-on-raspberrypi-linux/installing-circuitpython-on-raspberry-pi) and the [NeoPixel](https://learn.adafruit.com/neopixels-on-raspberry-pi/python-usage) library.
:::
<Tabs groupId='code-lang'>
    <TabItem value="python" label="Python" default>

    ```py
    from time import sleep
    import board
    import neopixel
    import RPi.GPIO as GPIO

    # LED strip configuration:
    LED_COUNT = 2         # Number of LED pixels.
    LED_PIN = board.D18   # GPIO pin connected to the pixels.
    LED_BRIGHTNESS = 1    # Brightness of the LED pixels

    # Button configuration:
    BUTTON_PIN = 20       # GPIO pin connected to the button.

    # Setup the button pin
    GPIO.setmode(GPIO.BCM)
    GPIO.setup(BUTTON_PIN, GPIO.IN, pull_up_down=GPIO.PUD_UP)

    # Create NeoPixel object with appropriate configuration.
    pixels = neopixel.NeoPixel(LED_PIN, LED_COUNT, brightness=LED_BRIGHTNESS, auto_write=False)
    
    # Generate a random color.
    def random_color():
        return (random.randint(0, 255), random.randint(0, 255), random.randint(0, 255))

    # Set the color of the entire strip.
    def set_color(color):
        for i in range(LED_COUNT):
            pixels[i] = color
        pixels.show()
    
    print('Press the button to change colors. Press Ctrl-C to quit.')

    try:
        while True:
            button_state = GPIO.input(BUTTON_PIN)
            if button_state == GPIO.LOW:
                # Button is pressed
                color = random_color()
                set_color(color)
                # Wait for the button to be released
                while GPIO.input(BUTTON_PIN) == GPIO.LOW:
                    sleep(0.01)
            sleep(0.1)
    except KeyboardInterrupt:
        # Cleanup on exit
        GPIO.cleanup()

    ```
    </TabItem>
    {/* <TabItem value="c" label="C" >
    ```c
    #include <stdio.h>
    #include <wiringPi.h>

    // Define the GPIO pin number for the PoE indicator
    #define POE_INDICATOR_GPIO 23

    int main(void) {
        // Initialize the wiringPi library
        if (wiringPiSetupGpio() == -1) {
            printf("wiringPi setup failed\n");
            return 1;
        }

        // Set the GPIO pin mode to input
        pinMode(POE_INDICATOR_GPIO, INPUT);

        // Read the state of the GPIO pin
        int poeIndicatorState = digitalRead(POE_INDICATOR_GPIO);

        // Check if the pin is active (assuming active-high logic)
        if (poeIndicatorState == HIGH) {
            printf("Powersource: 802.3af or USB Type-C\n");
        } else {
            printf("Powersource: 802.3at\n");
        }

        return 0;
    }
    ```
    </TabItem> */}
</Tabs>

# Edge Button
The button is connected to `GPIO20` in the Raspberry PI compute module and can be customized as you like. Can be pressed with a left touch of the Blade latch.

### Example Script
```py
import RPi.GPIO as GPIO
import time

GPIO.setmode(GPIO.BCM)
GPIO.setup(20, GPIO.IN, pull_up_down=GPIO.PUD_UP) #Button to GPIO20

try:
    while True:
         button_state = GPIO.input(20)
         if button_state == False:
             print('Button Pressed...')
             time.sleep(0.2)
except:
    GPIO.cleanup()
```

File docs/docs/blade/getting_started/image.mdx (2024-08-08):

---
sidebar_position: 1
---

import Tabs from '@theme/Tabs';
import TabItem from '@theme/TabItem';
import Admonition from '@theme/Admonition';

# Imaging Storage Media

You can boot the Raspberry Pi Compute Module 4 (CM4) in several ways on the Compute Blade

:::note
Preboot eXecution Environment(PXE) is a prosses to boot a computer over the a network. It will not be covered here. Aee our [deticated guide](/blade/advanced-guides/pxe-booting/) for more information
:::

## Pepare Storage Media

To prepare a storage media you will need another computer

<Tabs groupId="boot" defaultValue="ssd">
    <TabItem value="microsd" label="microSD Card" >
        <Admonition type="warning">
            Only the Dev model Compute Blade has a microSD Card slot
        </Admonition>
        <Admonition type="note">
            CM4s with part number `CM4XXX000` must be used as others have eMMC and are unable to use MicroSD Card slot
            CM4 box with model number highlighted
        </Admonition>
        The microSD Card needs to be at least 8GB. Your computer may not have a microSD Card slot and need an adapter.
    </TabItem>
    <TabItem value="ssd" label="SSD">
        <Admonition type="warning">
            The Compute Blade supports M key and B+M key M.2 devices, from size `2230` to `22110`
        </Admonition>
        The Compute Blade has a M.2 M key witch supports both SATA and NVMe Solid State Drives(SSD).
        The M.2 SSD can be Imaged the same as the microSD Card but requires an USB to M.2 NVME/SATA Adapter, such as the [UGREEN M.2 NVMe SSD Enclosure Adapter](https://www.ugreen.com/collections/hard-drive-enclosure/products/ugreen-m-2-nvme-ssd-enclosure-adapter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).
    </TabItem>
    <TabItem value="emmc" label="eMMC">
        <Admonition type="warning">
            eMMC only be imaged on Dev blade as it has USB-C port, USB switch, and `nRPIBOOT` button
        </Admonition>
        <Admonition type="note">
            CM4s with part number `CM4XXX000` do **NOT** have eMMC and are refered to a lite
            CM4 box with model number highlighted
        </Admonition>
        Install [usbboot](/blade/advanced-guides/usbboot)
        From the usbboot directory run
        ```bash
        sudo ./rpiboot
        ```
        Move the USB switch to the USB-C position
        Then, while holding down the `nRPIBOOT` button on the blade connect the USB-C cable
        
        Compute Blade with USB and nRPIBOOT button highlighted
        
        The Device will reconect several times. on the last time it will appear as a USB media device.
    </TabItem>
</Tabs>

Download and install [Raspberry Pi Imager](https://www.raspberrypi.com/software/). After installing run it. This software will be used to image the storage media.

Raspberry Pi Imager Home

Select Rasspberry Pi 4

Raspberry Pi Imager Device Filter

Select an operating system. We recomend Ubuntu Server 24.04 LTS (64-bit) `Operating System > Other general-purpose OS > Ubuntu > Ubuntu Server 24.04 LTS (64-bit)`

Raspberry Pi Imager OS

Select stroage media

Raspberry Pi Imager storage

Click the `NEXT` then click the `EDIT SETTINGS` button. Two setting need to be edited

- `GENERAL > Set hostname` - This name will be used to connect to your blade later
- `GENERAL > Set username and password` - use your own username and password
- `GENERAL > Set locale setting`(Optional) - this will ajuste the blade locale setting 

Raspberry Pi Imager setting general

`SERVICES > Enable SSH` - Use password authntication
<Admonition type="info">
    `Allow public-key authentication only` is the more secure option but is more complex to set up. read More in our [SSH guide](/blade/getting_started/connect/#public-key-authentication)
</Admonition>

Raspberry Pi Imager setting service

Then click `SAVE`

Finally click `YES` and confirm that all existing data on the storage device will be erased by clicking `YES` again.
Raspberry Pi Imager will begin to write the OS to the storage device.

Once completed remove the storage device from the computer

Raspberry Pi Imager Complete

## Install Storage Media in Blade

<Tabs groupId="boot" defaultValue="ssd">
    <TabItem value="microsd" label="microSD Card" >
        <Admonition type="warning">
            Only the Dev model Compute Blade has a microSD Card Slot
        </Admonition>
        Next to the top right corner of the CM4 you will find the microSD Card slot. Insert the card with the pins facing down
        computeblade mk4 sd card slot
    </TabItem>
    <TabItem value="ssd" label="SSD">
        1. Remove the Kapton Tape from the standoff mount
        2. Using a 5mm hex driver attach the standoff
        3. Insert the M.2 SSD at a 30° angle and press down
        4. Place the plasitc washer on to the screw and use a PH1 driver to retain the M.2 SSD
    
        computeblade mk4 ssd slot
    </TabItem>
    <TabItem value="emmc" label="eMMC">
        Unplug the USB-C cable from the Compute Blade and set the stwitch to USB-A

        computeblade mk4 emmc chip
    </TabItem>
</Tabs>

Your Blade is now ready to be connected to over a network

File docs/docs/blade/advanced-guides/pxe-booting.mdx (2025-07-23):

# PXE Boot/Provisioning

The CM4 / CM5 can natively boot via PXE, but requires additional files on the TFTP server for bootstrapping.
In order to provide a standardized UEFI boot process (including PXE), there's an [EDK2 UEFI build available for the ComputeBlade](https://github.com/uptime-lab/compute-blade-cm4-uefi).
Using this image for the SD Card (CM4 / CM5 Lite modules) or eMMC enables commodity provisioning software supporting ARM64 to bootstrap clusters.

## Canonical MaaS

Canonical [MaaS](https://maas.io) is a bare-metal provisioning tool focused on Ubuntu. The [How-To Guide](https://maas.io/docs/how-to-install-maas) works out of the box therefore no further documentation is specified here.

## PXE Booting Nodes with Tinkerbell
> In this example, we're booting [Talos Linux](http://talos.dev). This works with any other distribution supporting a netboot environment as well.

The component responsible for the PXE booting within the [Tinkerbell](https://tinkerbell.org) stack is [Smee](https://github.com/tinkerbell/smee). It can be setup either bare-metal or within a Kubernetes cluster.

### Installing Tinkerbell on a single-node Kubernetes installation

Tinkerbell, or more specific for this use-case Smee, can be installed using helm:

values.yaml:
```yaml
tink:
  server:
    deploy: false
  controller:
    deploy: false
rufio:
  deploy: false
hegel:
  deploy: false
smee:
  hostNetwork: true
  publicIP: 100.64.0.2  # Set to the IP address of your node
  trustedProxies:
  - 0.0.0.0/0
  nodeSelector:
    kubernetes.io/hostname: talos-di6-jbg  # Set to the k8s node name. Has to match the publicIP value above
stack:
  enabled: false

```

```bash
helm install tink-stack oci://ghcr.io/tinkerbell/charts/stack --version "0.4.5" --create-namespace --namespace tink-system --wait -f values.yaml
```

### Defining Boot Process
After everything is up and running, you can declare `Hardware` resources with networking configuration alongside boot information. Here an exampel for a ComputeModule with the MAC address `d8:3a:dd:bb:36:be`:
```
---
apiVersion: "tinkerbell.org/v1alpha1"
kind: Hardware
metadata:
  name: bld-d83addbb36be
  namespace: tink-system
spec:
  interfaces:
    - dhcp:
        ip:
          address: 100.64.0.100
          gateway: 100.64.0.1
          netmask: 255.255.255.0
        mac: d8:3a:dd:bb:36:be
        name_servers:
          - 100.64.0.1
        uefi: true
      netboot:
        allowPXE: true
        allowWorkflow: false
        ipxe:
          url: https://pxe.factory.talos.dev/pxe/779804eb249e184f2986a0cacb95aa6ed8f133878449da8df9a68829f90902b9/v1.7.5/metal-arm64
```

Upon powering up the blade, the boot process can be followed in the log output of smee:
```
smee-dfcb5c7b6-h52h9 smee {"level":"info","ts":1722086063.1273975,"caller":"reservation/handler.go:86","msg":"received DHCP packet","mac":"d8:3a:dd:bb:36:be","xid":"0xa89f634e","interface":"eth0","type":"DISCOVER"}
smee-dfcb5c7b6-h52h9 smee {"level":"info","ts":1722086063.1281593,"caller":"reservation/handler.go:141","msg":"sent DHCP response","mac":"d8:3a:dd:bb:36:be","xid":"0xa89f634e","interface":"eth0","type":"OFFER","bootFileName":"snp.efi","nextServer":"100.64.0.2","ipAddress":"100.64.0.100","destination":"255.255.255.255:68"}
smee-dfcb5c7b6-h52h9 smee {"level":"info","ts":1722086071.1267426,"caller":"reservation/handler.go:101","msg":"received DHCP packet","mac":"d8:3a:dd:bb:36:be","xid":"0xa89f634e","interface":"eth0","type":"REQUEST"}
smee-dfcb5c7b6-h52h9 smee {"level":"info","ts":1722086071.1273892,"caller":"reservation/handler.go:141","msg":"sent DHCP response","mac":"d8:3a:dd:bb:36:be","xid":"0xa89f634e","interface":"eth0","type":"ACK","bootFileName":"snp.efi","nextServer":"100.64.0.2","ipAddress":"100.64.0.100","destination":"255.255.255.255:68"}
smee-dfcb5c7b6-h52h9 smee {"level":"error","ts":1722086071.1357145,"logger":"github.com/tinkerbell/ipxedust","caller":"itftp/itftp.go:106","msg":"file serve failed","service":"github.com/tinkerbell/smee","event":"get","filename":"snp.efi","uri":"snp.efi","client":{"IP":"100.64.0.100","Port":1389,"Zone":""},"macFromURI":"","b":0,"contentSize":267776,"error":"sending block 0: code=8, error: User aborted the transfer\u0000","stacktrace":"github.com/tinkerbell/ipxedust/itftp.Handler.HandleRead\n\t/home/runner/go/pkg/mod/github.com/tinkerbell/ipxedust@v0.0.0-20231215220341-a535c5deb47a/itftp/itftp.go:106\ngithub.com/pin/tftp/v3.(*Server).handlePacket.func2\n\t/home/runner/go/pkg/mod/github.com/pin/tftp/v3@v3.1.0/server.go:455"}
smee-dfcb5c7b6-h52h9 smee {"level":"error","ts":1722086072.9095297,"logger":"github.com/tinkerbell/ipxedust","caller":"itftp/itftp.go:106","msg":"file serve failed","service":"github.com/tinkerbell/smee","event":"get","filename":"snp.efi","uri":"snp.efi","client":{"IP":"100.64.0.101","Port":1097,"Zone":""},"macFromURI":"","b":142848,"contentSize":267776,"error":"Channel timeout: 100.64.0.101:1097","stacktrace":"github.com/tinkerbell/ipxedust/itftp.Handler.HandleRead\n\t/home/runner/go/pkg/mod/github.com/tinkerbell/ipxedust@v0.0.0-20231215220341-a535c5deb47a/itftp/itftp.go:106\ngithub.com/pin/tftp/v3.(*Server).handlePacket.func2\n\t/home/runner/go/pkg/mod/github.com/pin/tftp/v3@v3.1.0/server.go:455"}
smee-dfcb5c7b6-h52h9 smee {"level":"info","ts":1722086073.7314184,"logger":"github.com/tinkerbell/ipxedust","caller":"itftp/itftp.go:111","msg":"file served","service":"github.com/tinkerbell/smee","event":"get","filename":"snp.efi","uri":"snp.efi","client":{"IP":"100.64.0.100","Port":1390,"Zone":""},"macFromURI":"","bytesSent":267776,"contentSize":267776}
smee-dfcb5c7b6-h52h9 smee {"level":"error","ts":1722086073.7342472,"logger":"github.com/tinkerbell/ipxedust","caller":"itftp/itftp.go:91","msg":"file unknown","service":"github.com/tinkerbell/smee","event":"get","filename":"autoexec.ipxe","uri":"autoexec.ipxe","client":{"IP":"100.64.0.100","Port":1391,"Zone":""},"macFromURI":"","error":"file [autoexec.ipxe] unknown: file does not exist","stacktrace":"github.com/tinkerbell/ipxedust/itftp.Handler.HandleRead\n\t/home/runner/go/pkg/mod/github.com/tinkerbell/ipxedust@v0.0.0-20231215220341-a535c5deb47a/itftp/itftp.go:91\ngithub.com/pin/tftp/v3.(*Server).handlePacket.func2\n\t/home/runner/go/pkg/mod/github.com/pin/tftp/v3@v3.1.0/server.go:455"}
smee-dfcb5c7b6-h52h9 smee {"level":"info","ts":1722086082.7369385,"caller":"reservation/handler.go:86","msg":"received DHCP packet","mac":"d8:3a:dd:bb:36:be","xid":"0x98b69526","interface":"eth0","type":"DISCOVER"}
smee-dfcb5c7b6-h52h9 smee {"level":"info","ts":1722086082.7379577,"caller":"reservation/handler.go:141","msg":"sent DHCP response","mac":"d8:3a:dd:bb:36:be","xid":"0x98b69526","interface":"eth0","type":"OFFER","bootFileName":"https://pxe.factory.talos.dev/pxe/779804eb249e184f2986a0cacb95aa6ed8f133878449da8df9a68829f90902b9/v1.7.5/metal-arm64","nextServer":"100.64.0.2","ipAddress":"100.64.0.100","destination":"255.255.255.255:68"}
smee-dfcb5c7b6-h52h9 smee {"level":"info","ts":1722086082.7425363,"caller":"reservation/handler.go:101","msg":"received DHCP packet","mac":"d8:3a:dd:bb:36:be","xid":"0x98b69526","interface":"eth0","type":"REQUEST"}
smee-dfcb5c7b6-h52h9 smee {"level":"info","ts":1722086082.7433407,"caller":"reservation/handler.go:141","msg":"sent DHCP response","mac":"d8:3a:dd:bb:36:be","xid":"0x98b69526","interface":"eth0","type":"ACK","bootFileName":"https://pxe.factory.talos.dev/pxe/779804eb249e184f2986a0cacb95aa6ed8f133878449da8df9a68829f90902b9/v1.7.5/metal-arm64","nextServer":"100.64.0.2","ipAddress":"100.64.0.100","destination":"255.255.255.255:68"}
smee-dfcb5c7b6-h52h9 smee {"level":"info","ts":1722086083.658168,"caller":"syslog/receiver.go:160","msg":"msg","msg":{"app-name":"ipxe","facility":"kern","host":"100.64.0.100","msg":"Configuring (net0 d8:3a:dd:bb:36:be)...... ok","severity":"INFO"}}
smee-dfcb5c7b6-h52h9 smee {"level":"info","ts":1722086083.6583776,"caller":"syslog/receiver.go:160","msg":"msg","msg":{"app-name":"ipxe","facility":"kern","host":"100.64.0.100","msg":"net0: 100.64.0.100/255.255.255.0 gw 100.64.0.1","severity":"INFO"}}
smee-dfcb5c7b6-h52h9 smee {"level":"info","ts":1722086083.6585057,"caller":"syslog/receiver.go:160","msg":"msg","msg":{"app-name":"ipxe","facility":"kern","host":"100.64.0.100","msg":"net0: fe80::da3a:ddff:febb:36be/64","severity":"INFO"}}
smee-dfcb5c7b6-h52h9 smee {"level":"info","ts":1722086083.658876,"caller":"syslog/receiver.go:160","msg":"msg","msg":{"app-name":"ipxe","facility":"kern","host":"100.64.0.100","msg":"Next server: 100.64.0.2","severity":"INFO"}}
smee-dfcb5c7b6-h52h9 smee {"level":"info","ts":1722086083.6590402,"caller":"syslog/receiver.go:160","msg":"msg","msg":{"app-name":"ipxe","facility":"kern","host":"100.64.0.100","msg":"Filename: https://pxe.factory.talos.dev/pxe/779804eb249e184f2986a0cacb95aa6ed8f133878449da8df9a68829f90902b9/v1.7.5/metal-arm64","severity":"INFO"}}
smee-dfcb5c7b6-h52h9 smee {"level":"info","ts":1722086083.686273,"caller":"syslog/receiver.go:160","msg":"msg","msg":{"app-name":"ipxe","facility":"kern","host":"100.64.0.100","msg":"https://pxe.factory.talos.dev/pxe/779804eb249e184f2986a0cacb95aa6ed8f133878449da8df9a68829f90902b9/v1.7.5/metal-arm64... ok","severity":"INFO"}}
smee-dfcb5c7b6-h52h9 smee {"level":"info","ts":1722086083.6873302,"caller":"syslog/receiver.go:160","msg":"msg","msg":{"app-name":"ipxe","facility":"kern","host":"100.64.0.100","msg":"metal-arm64 : 259 bytes [script]","severity":"INFO"}}
smee-dfcb5c7b6-h52h9 smee {"level":"info","ts":1722086087.3916304,"caller":"syslog/receiver.go:160","msg":"msg","msg":{"app-name":"ipxe","facility":"kern","host":"100.64.0.100","msg":"/kernel-arm64... ok","severity":"INFO"}}
smee-dfcb5c7b6-h52h9 smee {"level":"info","ts":1722086090.1534588,"caller":"syslog/receiver.go:160","msg":"msg","msg":{"app-name":"ipxe","facility":"kern","host":"100.64.0.100","msg":"/initramfs-arm64.xz... ok","severity":"INFO"}}

smee-dfcb5c7b6-h52h9 smee {"level":"info","ts":1722086112.4891257,"caller":"reservation/handler.go:86","msg":"received DHCP packet","mac":"d8:3a:dd:bb:36:be","xid":"0x3bb97cad","interface":"eth0","type":"DISCOVER"}
smee-dfcb5c7b6-h52h9 smee {"level":"info","ts":1722086112.4899402,"caller":"reservation/handler.go:141","msg":"sent DHCP response","mac":"d8:3a:dd:bb:36:be","xid":"0x3bb97cad","interface":"eth0","type":"OFFER","nextServer":"100.64.0.2","ipAddress":"100.64.0.100","destination":"255.255.255.255:68"}
smee-dfcb5c7b6-h52h9 smee {"level":"info","ts":1722086112.4966073,"caller":"reservation/handler.go:101","msg":"received DHCP packet","mac":"d8:3a:dd:bb:36:be","xid":"0x3bb97cad","interface":"eth0","type":"REQUEST"}
smee-dfcb5c7b6-h52h9 smee {"level":"info","ts":1722086112.5007463,"caller":"reservation/handler.go:141","msg":"sent DHCP response","mac":"d8:3a:dd:bb:36:be","xid":"0x3bb97cad","interface":"eth0","type":"ACK","nextServer":"100.64.0.2","ipAddress":"100.64.0.100","destination":"255.255.255.255:68"}
```

To confirm the provisioning has been successful:
```bash
130 xvzf@zephyr ..exus/kube/clusters/aperture/tinkerbell (git)-[main] % talosctl get addresses --insecure  -n 100.64.0.100
NODE   NAMESPACE   TYPE            ID                                                       VERSION   ADDRESS                                  LINK
       network     AddressStatus   enxd83addbb36be/100.64.0.100/24                          1         100.64.0.100/24                          enxd83addbb36be
       network     AddressStatus   enxd83addbb36be/fd33:b4d:c0fe:a:da3a:ddff:febb:36be/64   1         fd33:b4d:c0fe:a:da3a:ddff:febb:36be/64   enxd83addbb36be
       network     AddressStatus   enxd83addbb36be/fe80::da3a:ddff:febb:36be/64             2         fe80::da3a:ddff:febb:36be/64             enxd83addbb36be
       network     AddressStatus   lo/127.0.0.1/8                                           1         127.0.0.1/8                              lo
       network     AddressStatus   lo/::1/128                                               1         ::1/128                                  lo
```

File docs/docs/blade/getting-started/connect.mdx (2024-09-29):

---
sidebar_position: 3
---

import Tabs from '@theme/Tabs';
import TabItem from '@theme/TabItem';

# Connect Using SSH

[Secure Shell Protocol](https://en.wikipedia.org/wiki/Secure_Shell)(SSH) is a cryptographic network protocol for operating networked services securely over an unsecured network.
This is the most common way to connect to a Compute Blade.

## Installing SSH Client

To connect using SSH you will need a SSH client. there are a number of options available:
- [PuTTY](https://www.putty.org/) by Simon Tatham
- [Secure Shell](https://chromewebstore.google.com/detail/secure-shell/iodihamcpbpeioajjeobimgagajmlibd) by Google
- [OpenSSH](https://www.openssh.com/) by OpenBSD Foundation

All of these clients will work, but for this guide we will be using OpenSSH.
<Tabs groupId="os" defaultValue="windows">
    <TabItem value="windows" label="Windows">

    To install [OpenSSH for Windows](https://learn.microsoft.com/en-us/windows-server/administration/openssh/openssh_overview)
    run PowerShell as an Administrator. To make sure that OpenSSH is available and not installed, run the following cmdlet:
    ```powershell
    Get-WindowsCapability -Online | Where-Object Name -like 'OpenSSH.Client*'
    ```
    The command should return the following output if it is not installed:
    ```txt
    Name  : OpenSSH.Client~~~~0.0.1.0
    State : NotPresent
    ```
    Then Run the following cmdlet to install the OpenSSH Client:
    ```powershell
    Add-WindowsCapability -Online -Name OpenSSH.Client~~~~0.0.1.0
    ```
    The command should return the following output:
    ```txt
    Path          :
    Online        : True
    RestartNeeded : False
    ```
    </TabItem>
    <TabItem value="macos" label="MacOS">
    OpenSSH is included in MacOS out of the box; No installation required.
    </TabItem>
    <TabItem value="linux" label="Linux">
        Many distributions come with OpenSSH included but if yours does not here is how to install it on some common distributions:
        <Tabs groupId="pkgm" defaultValue="apt">
            <TabItem value="apt" label="Debian/Ubuntu">
                OpenSSH is listed in the `apt` package manager
                ```bash
                sudo apt update
                sudo apt upgrade
                sudo apt install openssh-client
                ```
            </TabItem>
            <TabItem value="yum" label="RHEL/Centos/Fedora">
            OpenSSH is listed in the `yum` package manager
                ```bash
                    sudo yum update
                    sudo yum upgrade
                    sudo yum install openssh-clients
                ```
            </TabItem>
        </Tabs>
    </TabItem>
</Tabs>

## Using SSH Command Line Interface

Using the Host name or IP address of the Blade we can use the command line to connect to it
```bash
ssh [user@]host-name-or-address
```
When connecting to a computer for the first time you will be asked if you are sure you want to connect. By typing `yes` a key fingerprint will be added to the list of known hosts.
```txt
ssh uptime@blade
The authenticity of host 'blade (192.168.1.100)' can't be established.
ED25519 key fingerprint is SHA256:10RTKd4AHOBM9lHPf938y4wCl7DiKoZWJAJ+Rcg6Rcg.
This key is not known by any other names
Are you sure you want to continue connecting (yes/no/[fingerprint])?
```
Then enter your password
```txt
uptime@blade's password:
```
Once authenticated you will be presented with an active bash terminal.
```bash
uptime@blade:~$
```

### Notable Command Line Options

You may need to need to pass options to the SSH command when connecting. Here are some of the most used:
- `-p` Port to connect to on the remote host.
- `-l` Specifies the user to log in as on the remote machine.

## Public Key Authentication

Public key authentication provides cryptographic strength that even extremely long passwords can not offer.
With SSH, public key authentication improves security considerably, freeing users from remembering complicated passwords.

### Creating Key Pair

To create a key pair the OpenSSh Client includes the command
```bash
ssh-keygen
cat ~/.ssh/id_rsa.pub # Append this in ~/.ssh/authorized_keys (Create $HOME/.ssh/authorized_keys if it does not already exist)
ssh -i ~/.ssh/id_rsa <user>@<remoteserver> # To use with your ssh client
```

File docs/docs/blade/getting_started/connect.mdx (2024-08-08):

---
sidebar_position: 3
---

import Tabs from '@theme/Tabs';
import TabItem from '@theme/TabItem';

# Conect Using SSH

Secure Shell Protical(SSH) is a cryptographic network protocol for operating network services securely over an unsecured network.
This is the most comman way to connect to a Compute Blade.

## Installing SSH Client

To connect using SSH you will need a SSH client there are a number of options available
- [PuTTY](https://www.putty.org/) by Simon Tatham
- [Secure Shell](https://chromewebstore.google.com/detail/secure-shell/iodihamcpbpeioajjeobimgagajmlibd) by Google
- [OpenSSH](https://www.openssh.com/) by OpenBSD Foundation

All of these clients will work but for this guide we will be using OpenSSH
<Tabs groupId="os" defaultValue="windows">
    <TabItem value="windows" label="Windows">

    To install [OpenSSH for Windows](https://learn.microsoft.com/en-us/windows-server/administration/openssh/openssh_overview)
    run PowerShell as an Administrator. To make sure that OpenSSH is available and not install, run the following cmdlet:
    ```powershell
    Get-WindowsCapability -Online | Where-Object Name -like 'OpenSSH.Client*'
    ```
    The command should return the following output if it is not installed:
    ```txt
    Name  : OpenSSH.Client~~~~0.0.1.0
    State : NotPresent
    ```
    Then Run the following cmdlet to install the OpenSSH Client:
    ```powershell
    Add-WindowsCapability -Online -Name OpenSSH.Client~~~~0.0.1.0
    ```
    The commands should return the following output:
    ```txt
    Path          :
    Online        : True
    RestartNeeded : False
    ```
    </TabItem>
    <TabItem value="macos" label="MacOS">
    OpenSSH is included in MacOS. No Instalation required
    </TabItem>
    <TabItem value="linux" label="Linux">
        Many distrubutions come with OpenSSH inclued but if yours does not here is how to install it on so comman distrubutions
        <Tabs groupId="pkgm" defaultValue="apt">
            <TabItem value="apt" label="Debian/Ubuntu">
                OpenSSH is listed in the `apt` package manager
                ```bash
                sudo apt update
                sudo apt upgrade
                sudo apt install openssh-client
                ```
            </TabItem>
            <TabItem value="yum" label="RHEL/Centos/Fedora">
            OpenSSH is listed in the `yum` package manager
                ```bash
                    sudo yum update
                    sudo yum upgrade
                    sudo yum install openssh-clients
                ```
            </TabItem>
        </Tabs>
    </TabItem>
</Tabs>

## Using SSH Command Line Interface

Using the Host name or IP address of the Blade we can use the command line to connect to it
```bash
ssh [user@]host-name-or-address
```
When connecting to a computer for the first you will be asked to you are sure you want to connect. by typing `yes` a key fingerprint will be added to the list of known host.
```txt
ssh uptime@192.168.1.100
The authenticity of host '192.168.1.100 (192.168.1.100)' can't be established.
ED25519 key fingerprint is SHA256:10RTKd4AHOBM9lHPf938y4wCl7DiKoZWJAJ+Rcg6Rcg.
This key is not known by any other names
Are you sure you want to continue connecting (yes/no/[fingerprint])?
```
Then enter your password
```txt
uptime@192.168.1.100's password:
```
Once authenticated you will be presented with a active bash
```txt
uptime@blade:~$
```

### Notable Command Line Options

You may need to need to pash Otions to the SSH command when connection here are some of the most used:
- `-p` Port to connect to on the remote host.
- `-l` Specifies the user to log in as on the remote machine.

## Public Key Authentication

Public key authentication provides cryptographic strength that even extremely long passwords can not offer.
With SSH, public key authentication improves security considerably. Freeing users form remebering complicated passwords

### Creating Key Pair

To create a key pair the OpenSSh Client includes the command
```bash
ssh-keygen
```

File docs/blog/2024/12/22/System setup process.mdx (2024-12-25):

---
title: System setup process
description: A step-by-step guide to configure a production-ready Kubernetes environment on ComputeBlade.
authors: brushknight
tags: [blade, kubernetes]
image: /img/blog/19in_blades.webp
# hide_table_of_contents: false
---
This guide outlines the complete process for setting up a Kubernetes system using MicroK8s, a lightweight Kubernetes distribution. The setup includes essential components like kubectl and Helm, along with necessary configurations for running containerized applications.

19in Rack with compute blades

{/* truncate */}

Follow these steps sequentially to ensure a proper setup of your Kubernetes environment. Each section provides detailed commands and explanations to help you understand what you're implementing.

## About ComputeBlade platform

ComputeBlade is a rack-mountable, Power over Ethernet (PoE)-powered carrier board designed for the Raspberry Pi Compute Module 4 / Compute Module 5 (CM4 / CM5) and compatible devices. It enables the creation of high-density, low-power-consuming, plug-and-play blade servers suitable for both home and data center environments.

Compute Blade version 1

## Step-by-step guide

In the end of this instruction you'll have set up ComputeBlade with a functioning Kubernetes environment, including:

- A single-node MicroK8s Kubernetes cluster
- kubectl command-line tool for cluster management
- Helm package manager for Kubernetes
- Basic understanding of cluster operations and management
This setup will serve as a foundation for deploying and managing containerized applications on your ComputeBlade hardware.

### Installing MicroK8s

MicroK8s is a user-friendly Kubernetes distribution maintained by Canonical (Ubuntu). It provides a lightweight, production-ready Kubernetes that's easy to install and manage, making it an ideal choice for both development and production environments.

```bash
sudo snap install microk8s --classic
```

### Adding your user to the microk8s admin group

MicroK8s creates a group to enable seamless usage of commands which require admin privilege. Use the following commands to join the group:

```bash
sudo usermod -a -G microk8s $USER
sudo chown -f -R $USER ~/.kube
```

You will also need to re-enter the session for the group update to take place:

```bash
su - $USER
```

### Check the status while Kubernetes starts

```bash
microk8s status --wait-ready
```

Give it some time to finish.

### Turn on the services you want

We recommend to start next services by default:

```bash
microk8s enable dashboard dns ingress
```

Try `microk8s enable --help` for a list of available services and optional features. `microk8s disable ‹name›` turns off a service.

### Start using Kubernetes

```bash
microk8s kubectl get all --all-namespaces
```

### Access the Kubernetes dashboard (optional)

```bash
microk8s dashboard-proxy
```

### Installing kubectl

kubectl is the official command-line tool for Kubernetes that allows you to run commands against Kubernetes clusters. You can use kubectl to deploy applications, inspect and manage cluster resources, and view logs. It's an essential tool for:

- Deploying and managing applications in Kubernetes clusters
- Viewing and modifying cluster state and configuration
- Debugging and troubleshooting cluster issues
- Accessing cluster documentation and getting help with commands
- kubectl communicates with the Kubernetes API server to execute commands and manage your cluster resources. It's a fundamental tool for any Kubernetes administrator or developer.

To install it execute the following command:

```bash
sudo snap install kubectl --classic
```

Export config for kubectl:

```bash
microk8s config > $HOME/.kube/config
chmod -R 700 /home/ubuntu/.kube/config
```

### Installing Helm

Helm is a package manager for Kubernetes that simplifies the process of installing and managing applications. It serves several key purposes:

- Manages complex application deployments through pre-configured “charts” — packages of Kubernetes resources
- Enables version control and rollback of deployments to maintain application stability
- Simplifies sharing and reuse of Kubernetes applications across different environments
- Provides templating to customize application configurations without changing the original chart
Think of Helm as the “apt” or “yum” of Kubernetes — it makes it much easier to install, upgrade, and manage applications in your Kubernetes cluster.

You can fetch that script, and then execute it locally. It's well documented so that you can read through it and understand what it is doing before you run it.

```bash
curl -fsSL -o get_helm.sh https://raw.githubusercontent.com/helm/helm/main/scripts/get-helm-3
chmod 700 get_helm.sh
./get_helm.sh
```

### Well done

Congratulations! You have successfully set up a complete Kubernetes environment on your ComputeBlade. Your system now includes:

- A functioning MicroK8s Kubernetes cluster
- Kubectl command-line tool for cluster management
- Helm package manager for deploying applications
You're now ready to start deploying and managing containerized applications on your ComputeBlade. The foundation you've built will allow you to explore more advanced Kubernetes features and deployments as needed.

## Resources

- [Installing Helm](https://helm.sh/docs/intro/install/) | HELM Project
- [Install Kubernetes](https://ubuntu.com/kubernetes/install#multi-node) | Canonical Kubernetes

<a href="https://computeblade.com/buy-computeblade/">2024 Cyber bundle ad</a>

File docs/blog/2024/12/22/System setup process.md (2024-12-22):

---
title: System setup process
description: A step-by-step guide to configure a production-ready Kubernetes environment on ComputeBlade.
authors: brushknight
# tags: [hello, docusaurus-v2]
image: /img/blog/19in_blades.webp
# hide_table_of_contents: false
---
This guide outlines the complete process for setting up a Kubernetes system using MicroK8s, a lightweight Kubernetes distribution. The setup includes essential components like kubectl and Helm, along with necessary configurations for running containerized applications.

19in Rack with compute blades

<!-- truncate -->

Follow these steps sequentially to ensure a proper setup of your Kubernetes environment. Each section provides detailed commands and explanations to help you understand what you’re implementing.

## About ComputeBlade platform
ComputeBlade is a rack-mountable, Power over Ethernet (PoE)-powered carrier board designed for the Raspberry Pi Compute Module 4 / Compute Module 5 (CM4 / CM5) and compatible devices. It enables the creation of high-density, low-power-consuming, plug-and-play blade servers suitable for both home and data center environments.

Compute Blade version 1

## Step-by-step guide
In the end of this instruction you’ll have set up ComputeBlade with a functioning Kubernetes environment, including:
- A single-node MicroK8s Kubernetes cluster
- kubectl command-line tool for cluster management
- Helm package manager for Kubernetes
- Basic understanding of cluster operations and management
This setup will serve as a foundation for deploying and managing containerized applications on your ComputeBlade hardware.

### Installing MicroK8s
MicroK8s is a user-friendly Kubernetes distribution maintained by Canonical (Ubuntu). It provides a lightweight, production-ready Kubernetes that’s easy to install and manage, making it an ideal choice for both development and production environments.
```bash
sudo snap install microk8s --classic
```
### Adding your user to the microk8s admin group
MicroK8s creates a group to enable seamless usage of commands which require admin privilege. Use the following commands to join the group:
```bash
sudo usermod -a -G microk8s $USER
sudo chown -f -R $USER ~/.kube
```
You will also need to re-enter the session for the group update to take place:
```bash
su - $USER
```
### Check the status while Kubernetes starts
```bash
microk8s status --wait-ready
```
Give it some time to finish.

### Turn on the services you want
We recommend to start next services by default:
```bash
microk8s enable dashboard dns ingress
```
Try `microk8s enable --help` for a list of available services and optional features. `microk8s disable ‹name›` turns off a service.
### Start using Kubernetes
```bash
microk8s kubectl get all --all-namespaces
```
### Access the Kubernetes dashboard (optional)
```bash
microk8s dashboard-proxy
```

### Installing kubectl
kubectl is the official command-line tool for Kubernetes that allows you to run commands against Kubernetes clusters. You can use kubectl to deploy applications, inspect and manage cluster resources, and view logs. It’s an essential tool for:

- Deploying and managing applications in Kubernetes clusters
- Viewing and modifying cluster state and configuration
- Debugging and troubleshooting cluster issues
- Accessing cluster documentation and getting help with commands
- kubectl communicates with the Kubernetes API server to execute commands and manage your cluster resources. It’s a fundamental tool for any Kubernetes administrator or developer.

To install it execute the following command:
```bash
sudo snap install kubectl --classic
```
Export config for kubectl:
```bash
microk8s config > $HOME/.kube/config
chmod -R 700 /home/ubuntu/.kube/config
```
### Installing Helm
Helm is a package manager for Kubernetes that simplifies the process of installing and managing applications. It serves several key purposes:

- Manages complex application deployments through pre-configured “charts” — packages of Kubernetes resources
- Enables version control and rollback of deployments to maintain application stability
- Simplifies sharing and reuse of Kubernetes applications across different environments
- Provides templating to customize application configurations without changing the original chart
Think of Helm as the “apt” or “yum” of Kubernetes — it makes it much easier to install, upgrade, and manage applications in your Kubernetes cluster.

You can fetch that script, and then execute it locally. It’s well documented so that you can read through it and understand what it is doing before you run it.
```bash
curl -fsSL -o get_helm.sh https://raw.githubusercontent.com/helm/helm/main/scripts/get-helm-3
chmod 700 get_helm.sh
./get_helm.sh
```
### Well done
Congratulations! You have successfully set up a complete Kubernetes environment on your ComputeBlade. Your system now includes:

- A functioning MicroK8s Kubernetes cluster
- Kubectl command-line tool for cluster management
- Helm package manager for deploying applications
You’re now ready to start deploying and managing containerized applications on your ComputeBlade. The foundation you’ve built will allow you to explore more advanced Kubernetes features and deployments as needed.

## Resources
- [Installing Helm](https://helm.sh/docs/intro/install/) | HELM Project
- [Install Kubernetes](https://ubuntu.com/kubernetes/install#multi-node) | Canonical Kubernetes

2024 Cyber bundle ad

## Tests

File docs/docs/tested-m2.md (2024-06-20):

---
displayed_sidebar: docsSidebar
---

# Supported SSDs

Below is a list of NVMe SSDs that have been tested by Uptime Lab and community members.

| Product | Model | Capactiy | Tester |
|:---|:---|:---|:---|
| Crucial P2 | CT500P2SSD8 | 500GB | [xvzf](https://github.com/xvzf) |
| Crucial P3 | CT500P3SSD8 | 500GB | [pxpunx](https://github.com/pxpunx) |
| Crucial P3 | CT4000P3SSD8 | 4TB | [Uptime](https://github.com/uptime-industries) |
| Intel 670p | SSDPEKNU512GZ | 512GB | [pxpunx](https://github.com/pxpunx) |
| Intel Optane H10 | HBRPEKNX0101A | 16GB + 256GB | [pxpunx](https://github.com/pxpunx) |
| Intel Optane M10 <sup>1</sup> | MEMPEK1J032GAD | 32GB | [pxpunx](https://github.com/pxpunx) |
| Kingston NV2 | SNV2S/250G | 250GB | [pxpunx](https://github.com/pxpunx) |
| Kingston NV2 | SNV2S/1000G | 1TB | [xvzf](https://github.com/xvzf) |
| Kingston SNS8154P3 | RBUSNS8154P3256GJ1 | 256GB | [pxpunx](https://github.com/pxpunx) |
| KIOXIA-EXCERIA SSD | LRC10Z500GG8 | 500GB | [xvzf](https://github.com/xvzf) |
| KIOXIA BG4 | KBG40ZNS128G | 128GB | [pxpunx](https://github.com/pxpunx) |
| KIOXIA BG5 <sup>2</sup> | KBG50ZNV512G | 512GB | [xvzf](https://github.com/xvzf) |
| Micron 2450 | MTFDKBA256TFK | 256GB | [pxpunx](https://github.com/pxpunx) |
| Micron 3400 | MTFDKBA512TFH | 512GB | [pxpunx](https://github.com/pxpunx) |
| Patriot P310 | P310P240GM28 | 240GB | [pxpunx](https://github.com/pxpunx) |
| PNY CS1030 | M280CS1030-250-RB  | 250GB | [pxpunx](https://github.com/pxpunx) |
| Samsung 970 EVO | MZ-V7E500 | 500GB | [pxpunx](https://github.com/pxpunx) |
| Samsung 970 EVO Plus | MZ-V7S1T0B | 2TB | [Uptime](https://github.com/uptime-industries) |
| Samsung 960 PRO | MZ-V6P512BW | 500GB | [Uptime](https://github.com/uptime-industries) |
| Samsung 970 PRO | MZ-V7P512BW | 500GB | [Uptime](https://github.com/uptime-industries) |
| Samsung 980 PRO | MZ-V8P1T0B | 1TB | [Uptime](https://github.com/uptime-industries) |
| Samsumg PM991a | MZ9LQ256HBJD | 256GB | [pxpunx](https://github.com/pxpunx) |
| SK hynix BC711 | HFM256GD3JX016N | 256GB | [pxpunx](https://github.com/pxpunx) |
| SK hynix PC611 | HFS001TD9TNI | 1TB | [Uptime](https://github.com/uptime-industries) |
| Solidigm P41 Plus | SSDPFKNU512GZ | 512GB | [pxpunx](https://github.com/pxpunx) |
| Synology SNV3510 | SNV3510-400G | 400GB | [Uptime](https://github.com/uptime-industries) |
| TEAMGROUP MP33 | TM8FP6256G0C101 | 256GB | [pxpunx](https://github.com/pxpunx) |
| TEAMGROUP MP33 PRO | TM8FPD001T0C101 | 1TB | [dlohin](https://github.com/dlohin) |
| Toshiba BG3 | KBG30ZMS128G | 256GB | [pxpunx](https://github.com/pxpunx) |
| Transcend 110S | TS256GMTE110S | 256GB | [pxpunx](https://github.com/pxpunx) |
| WD Black SN770 | WDS250G3X0E | 250GB | [pxpunx](https://github.com/pxpunx) |
| WD Black SN770 | WDS500G3X0E | 500GB | [Uptime](https://github.com/uptime-industries) |
| WD Blue SN570 | WDS250G3B0C | 250GB | [pxpunx](https://github.com/pxpunx) |
| WD Green SN350 | WDS240G2G0C | 240GB | [pxpunx](https://github.com/pxpunx) |
| WD Red SN700 | WDS500G1R0C | 500GB | [pxpunx](https://github.com/pxpunx) |
| WD SN520 | SDAPNUW-256G-1006  | 256GB | [pxpunx](https://github.com/pxpunx) |

<sup>1</sup> _This SSD will not function as a boot disk._
<sup>2</sup> _Might cause slightly increased CM4 temperature, but stability & performance is not impacted (reported by [xvzf](https://github.com/xvzf)) ._

# Benchmarks

[pibenchnarks.com](https://pibenchmarks.com) is a popular site to upload micro SD, eMMC, SSD, and other storage benchmarks for Raspberry Pi and Pi clones. You can find benchmarks for some of the NVMe SSDs above via the links below.

* https://pibenchmarks.com/user/pxpunx/
* https://pibenchmarks.com/user/Merocle/

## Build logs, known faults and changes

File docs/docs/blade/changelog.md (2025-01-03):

---
sidebar_position: 9
---
# Changelog

## V1.0 MK4

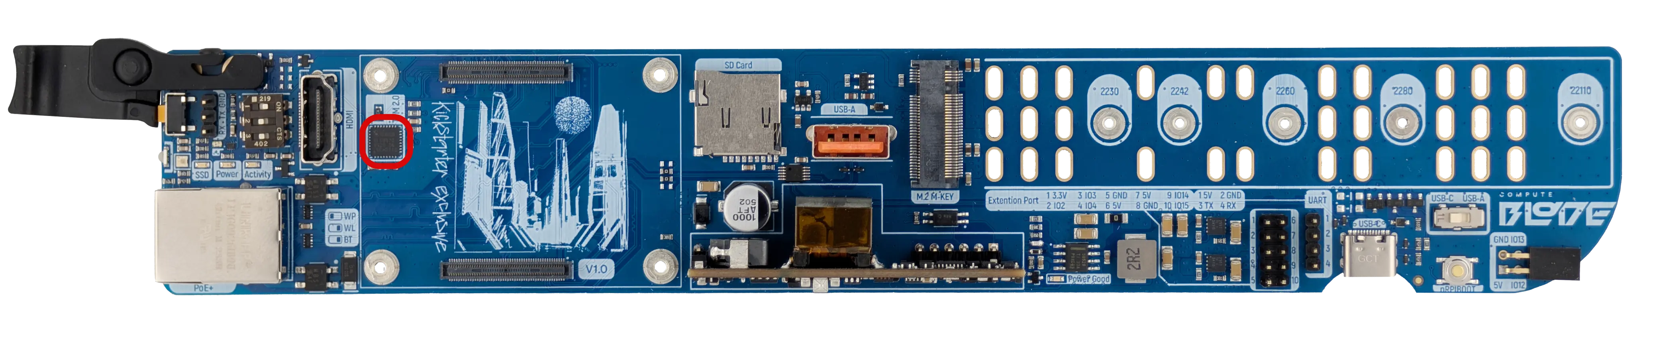
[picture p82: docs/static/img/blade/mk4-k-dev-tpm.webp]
Blade-MK4-k with TPM highlighted


### Improvements

- New TPM 2.0 module: [OPTIGA TPM SLB 9672](https://www.infineon.com/dgdl/Infineon-OPTIGA+TPM+SLB+9672+FW16-DataSheet-v01_00-EN.pdf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) as an upgrade of the previous generation

## V1.0 MK4-K

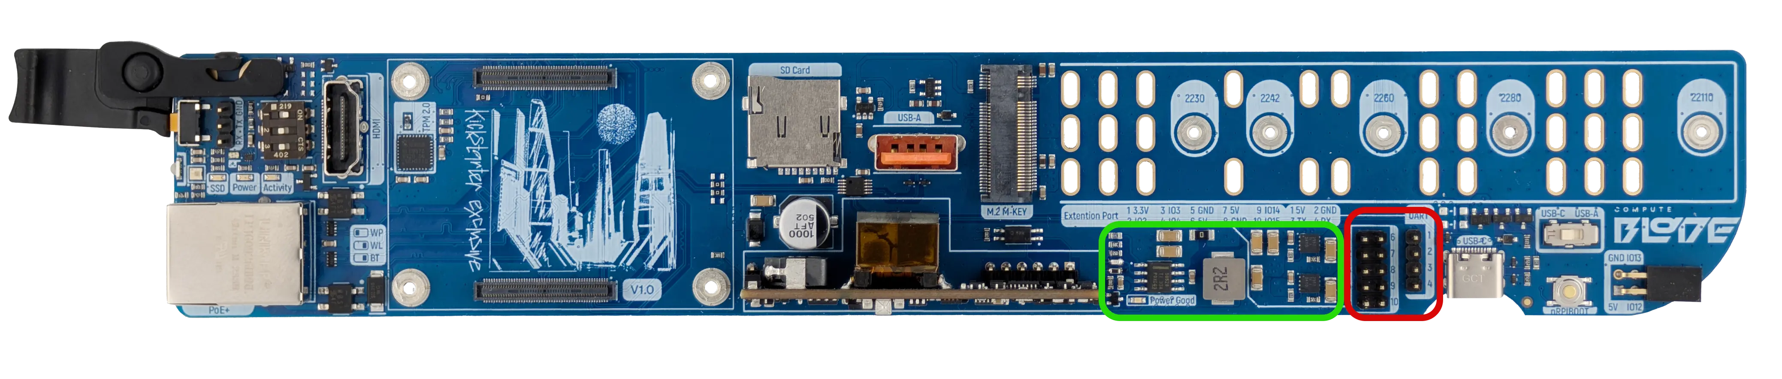
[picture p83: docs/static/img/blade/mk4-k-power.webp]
Blade-MK4-k with power and UART and Expansion pins highlighted


### Improvements

- Increased power on the `3.3V` bus to `16.5W`. Which will allow the use of future high-speed modules
- Added overload and short circuit protection to the `5V` and `3.3V` outputs on the board
- The possibility of powering the blade from the `5V` pin has been removed
- Power Good LED on the board works even without the Compute Module
- The low-speed modules connection is turned 180°

### Fixes

- The blue digital LED  would light up sometimes on startup due to power interference. Added additional filtering to the diode signal line, and the problem was solved
- A certain number of devices from early v1 batches may experience a voltage surge at startup under certain conditions. In extreme cases, this could potentially destroy the device's components. In cooperation with the manufacturer of the PoE module, additional stabilization of the PoE module output completely eliminated the problem

## V1.0 MK1

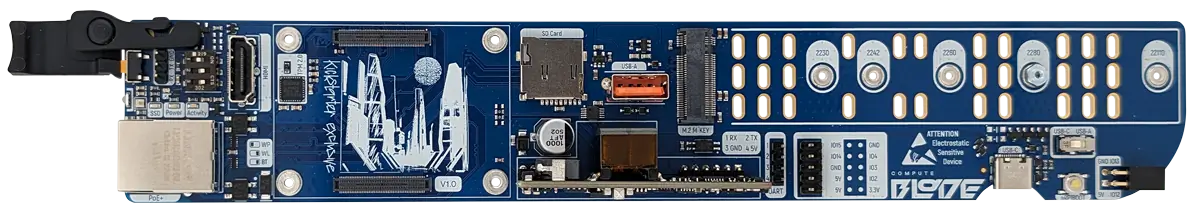
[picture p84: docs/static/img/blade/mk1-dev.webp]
MK1 Dev Blade


### Improvements

- Increased standoffs height for CM4 allows you to use different clones without worrying about the space under the module;
- Power over Ethernet [`IEEE 802.3at`](https://standards.ieee.org/ieee/802.3at/4553/) (PoE+) up to `30W` (normal operation `2W`-`8W`);
- New PoE module ([Silvertel AG5405](https://silvertel.com/images/datasheets/Ag5400-datasheet-high%20Efficiency-30W-Power-Over-Ethernet-Plus-Module-PoE+PD.pdf)) with one of the best characteristics in class
- Modified latch mounting holes for easier installation;
- More test points added

## V0.9 RC2
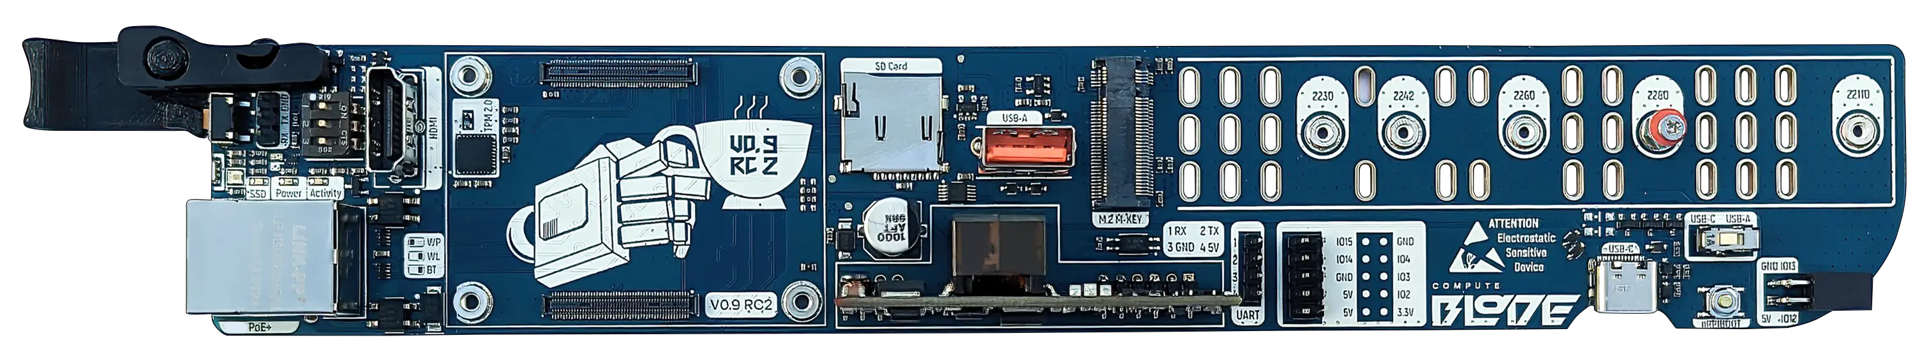
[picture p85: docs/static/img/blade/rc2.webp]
RC2 blade


### Features

- Support all Raspberry Pi CM4
- NVMe SSD up to `22110` (`2230`, `2242`, `2260`, `2280` supported)
- Gigabit Ethernet
- Power over Ethernet [`IEEE 802.3at`](https://standards.ieee.org/ieee/802.3at/4553/) (PoE+) up to `22W` (normal operation `2-8W`)
- Optional real-time clock (RTC) module
- Optional Zymbit ZYMKEY4i, or custom module for Zymbit Hardware Security(HSM)
- USB-A for a flash drive for copying data during setup with UART or YubiKey keys during operation
- MicroSD card port
- `UART0` on the front (TX, RX, GND)
- Additional `UART0` with `5V` in (or out) next to RTC port
- Two digital RGB LEDs
- Hardware switchable Wi-Fi, Bluetooth, and EEPROM write-protection
- Activity, Power, and SSD LEDs
- HDMI port for monitor (up to 4k60)
- USB Type-C port and nRPIBOOT button to flash the bootloader, access to eMMC/SD card or tests
- TPM 2.0 onboard
- PWM fan connector for the custom backplane (Fan Units), supports UART communication
- Switchable USB input (USB-A or USB Type-C)
- Programmable button on the front panel
- Officially “Powered by Raspberry Pi”
- FCC and CE ready
- Individual serial number
- The power supply of the Raspberry Pi CM4 is now `5.1V`, which has improved stability under overclocking. This is fully within the specifications (`4.75V`-`5.25V`)
- [`IEEE 802.3at`](https://standards.ieee.org/ieee/802.3at/4553/) detection (on Raspberry Pi with GPIO pin and additional LED on the blade)
- New button for the front panel (to feel the click better)
- All front LEDs can be turned off (except for Ethernet, this needs to be corrected in v.1), a very handy feature!
- Signed by [Ivan Kuleshov](https://www.linkedin.com/in/merocle/)

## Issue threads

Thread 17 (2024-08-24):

Documentation - Doubled text

equinoxel, 2024-08-24:
Page: https://docs.computeblade.com/blade/getting-started/assembly/#compute-module
Browser: Firefox
Description:
The text in the warning box is doubled:
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

Ethazeriel, 2024-08-24:
There's a few of these created in the most recent commit, should be fixed by #16

Closed 2024-08-26.

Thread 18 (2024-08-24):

Documentation - Doubled text box

equinoxel, 2024-08-24:
URL: https://docs.computeblade.com/blade/getting-started/assembly/#latch
Browser: Firefox
Description: The "warning" box for the _Latch_ section appears twice:

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

Closed 2024-08-26.

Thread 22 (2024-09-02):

docs: minor spelling mistake on homepage

Jmaasy, 2024-09-02:
On the homepage it notes "Gettting Started" instead of Getting Started on the button.
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

bowenjw, 2024-09-02:
Haha I will get that fixed

bowenjw, 2024-09-02:
Closed with commit [`aef95ed`](https://github.com/uptime-industries/compute-blade/commit/aef95ede7d6157058b8728eeea067b00391acac3)

Closed 2024-09-02.

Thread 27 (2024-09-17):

Add how to power section

bowenjw, 2024-09-17:
How to section for connecting power to blades, needed for all certified setups (1 blade no enclosure, two baldes runner, 4 blades runner, 10inch, 19inch). What to connect first, what second and a warning on what to avoid and general link to PoE protocols supported

bowenjw, 2024-09-18:
may be resolved with #30

Closed 2024-10-21.

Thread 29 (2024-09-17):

Clarify instruction on fan unit instillation of Fan Unit

bowenjw, 2024-09-17:
closer image and better description on how to connect fan unit and what to avoid. This could be mounted wrong easily.

bowenjw, 2024-09-18:
maybe resolved with #30

Closed 2024-10-21.

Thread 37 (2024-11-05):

Fan Unit Getting Started

bowenjw, 2024-11-05:
It is possible that Smart Fan Unit may not work out of the box with compute blade. Provide clear instruction during on how to update the firmware and basic control.
- [x] Create Smart Fan unit assembly instructions
- [x] Create Instructions to flash the firmware
- [x] Link Firmware instructions above assembly with warning box

Closed 2024-12-02.

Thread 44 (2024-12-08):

Docs for newbies -  Pico unit on the Smart Fan

einsteinagogo, 2024-12-08:
I think for newbies, in using the Pico unit on the Smart Fan, it should be expanded, that it's not just the code.py which needs to be copied to the CIRCUITPY media, but all the required libraries which are present in the lib folder, which are referenced in the code.py e.g. the adafruit library, without any of these libraries the code is not going to function.

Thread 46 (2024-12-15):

Docs for Setting up the Smart Fan Unit ( Python Libraries and CM5 settings)

honx, 2024-12-15:
moin,

I just set up the smart fan unit with circuitpython an a blade with a CM5. There are a few things that are currently not in the documentation that would've been helpful.

First, the uart is different on the CM5. On CM4 it's uart5, on CM5 its uart4.

These settings ```/boot/firmware/config.txt``` settings worked for me on the CM5:
```
enable_uart=1
dtoverlay=uart4-pi5
dtparam=uart4=on
```

Also, the docs on ```https://github.com/uptime-industries/circuitpy-fan-unit`` could use some extra information. I downloaded the current  uf2 like described (```adafruit-circuitpython-raspberry_pi_pico-en_US-9.2.1.uf2```).

However, that image is missing some of the requirements that the code.py needs. The docs mention these  at the header but the description could use the extra step of putting these into lib.

I cloned

```
https://github.com/adafruit/Adafruit_CircuitPython_NeoPixel.git
https://github.com/adafruit/Adafruit_CircuitPython_Register.git
https://github.com/adafruit/Adafruit_CircuitPython_EMC2101.git
```

and copied the libraries into the ```/lib``` subdirectory on the circuitpython device.

```
/lib/adafruit_emc2101/
/lib/adafruit_register/
/lib/neopixel.py
```

Maybe a note that the USB device will reset after copying the UF2 and then show up as a different device with different content and that it has to be remounted would be good.

Most of this is probably clear to people who worked with CircuitPython before. But for Blade users who just want to set up their Smart Fan Unit, a bit more detailed docs would be helpful.

scothis, 2024-12-15:
Did you also copy the [`lib` directory from the sample repo](https://github.com/uptime-industries/circuitpy-fan-unit/tree/main/lib) to the fan unit? That worked for me, but the docs don't mention it.

honx, 2024-12-15:
> Did you also copy the [`lib` directory from the sample repo](https://github.com/uptime-industries/circuitpy-fan-unit/tree/main/lib) to the fan unit? That worked for me, but the docs don't mention it.

aw, damn. that probably would've worked as well :-}

I just blindly followed the steps in the README (where it currently just says "replace code.py) and then fixed it by hand....

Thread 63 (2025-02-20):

Compute Module 5 and Dev kit

Anghille, 2025-02-20:
Hi there,

I have bought 2 compute blade (and planning to adding more to complete the full blade runner). I have installed ubuntu server 24.04.2 LTS using the RPI image, has I have been able to do for most of my raspbery pies. note that I use COMPUTE MODULE 5 (raspy 5), not CM4.

But this one has got me stuck. I have tried to install ubuntu multiple times, then install the SD Card on the compute blade, power it using ubiquiti POE switch. The CM5 module boots (I watch using an HDMI plugged to a screen), but get stuck after "Looking for btrfs filesystem", and after quite some time, it will just output :

```
mdamd: No array found in config file or automatically
mdamd: No array found in config file or automatically
mdamd: No array found in config file or automatically
...
mdamd: No array found in config file or automatically
Gave up waiting for root filesystem device.  Common problems:
Boot args (cat /proc/cmdline)
   - Check rootdelay= (did the system wait long enough?)
   - Check root= (did the system wait for the right device?)
 - Missing modules (cat /proc/modules; ls /dev)
ALERT! Label writable does not exists.

<initramfs + busybox cli>
```

2 things/questions :

1. I tried to plug a keyboard on the USB-A port (making sure the switch was set on usb-a) but it wont work, and I therefore cannot use initrams busybox image to try to debug the problem further. Tried with 3 different keyboards.

2. I am sure rpi image correctly installed the OS since I could navigate on the filesystem after install (and before ejecting the sd card), and I even tried to re)install it multiple times.

What could be the problem here ? I have no clue how to debug this since keyboard cant/wont work :(

I thank you very much for your time !

Anghille, 2025-02-23:
Turns out Ubuntu is not compatible with CM5 yet. It works on other 3 other CM5 at home, but is not officially supported. Booting with Raspberry Pi OS Lite 64 bits works like a charm.

Closing

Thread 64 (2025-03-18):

Blade Runner Mutipart

nicolube, 2025-03-18:
Hello there,

could u provide a model for the bladerunner 10 in that can be in 2 seperate parts?
Most Printers will fit the with of the model if u put the front down onto the build plate, but it is a but to tall.

If not would u be able to provide me with Project files (STEP, F3d) or whatever ur tool provides u?

ndizazzo, 2025-04-11:
[Will this work for you?](https://makerworld.com/en/models/1310689-10-bladerunner-enclosure-for-compute-blade#profileId-1344888)

ndizazzo, 2025-04-16:
Assuming this is solved due to inactivity.

Closed 2025-04-16.

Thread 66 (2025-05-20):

[request] - STEP files for customizing blade-runner

kquinsland, 2025-05-20:
This is a "re-post" of https://github.com/Uptime-Lab/BladeRunner/issues/1

-----

Any chance that you'd be able to provide STEP file(s) for the blade-runner?

Reasoning:

- I have a printer that can do the full thing in one go (barely!) A complete / single-part STEP file (or, STL if you must) would be appreciated!
  -  Digitally gluing together STL files is a pain and gluing together physical plastic parts is even more so.
- Customization. I was considering doing some multi-color work (like alternating the colors of the hexagonal pattern) and it's a _massive_ pain in the ass to do this on a mesh.

techrivertree, 2025-07-19:
This. The STL files used to be available but Orca slicer says they are bad files...

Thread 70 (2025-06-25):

Draw 15W+ on 5V for periphery

dpunzeng, 2025-06-25:
Hi There, we want to use the blade as the brain for our smart device. Not much comput power required but 15-18W @5V. how can I do this the best. I have not tried to re-engineer the pcb but I am sure, there is a "best" way to tap in? Thx heaps. Would you share the schema?

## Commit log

2024-06-10 switch to yarn
2024-06-14 added blade runner files
    [back.stl, both.stl, front.stl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]
2024-06-14 removed old versions of blade runners
    [back.stl, both.stl, front.stl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]
2024-06-17 renamed dir
    [both.stl, left.stl, right.stl]
2024-06-19 added Fan Unit
    [left.stl, right.stl]
2024-06-20 added fan unit and blade runner
2024-07-03 rename from home to quad
    [both.stl, left.stl, right.stl]
2024-08-19 added Fan Unit instructions
2024-08-22 added code exsample for fan unit
2024-08-22 moved fan code to its own repo
2024-08-23 Image update (#13)
    * updated Fan Images
    * updated Discord link
    * added spelling extension
    * added new images
    * added images to files
    ---------
2024-08-26 docs: tweak grammar, minor spelling errors, general sentence flow (#16)
    * first pass at assembly guide
    * quick grammar and scentence flow pass over docs
    * minor tweaks
    * minor tweaks to fan unit docs
    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
2024-08-28 Bladerunner (#19)
    * rename bladerunner
    * renamed bladerunners
    * removed un needed images
    * added BladeRunner documentation
    [both.stl, latch.stl, left bracket long.stl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]
2024-08-29 More data (#20)
    * first pass on adding more fan data
    * added table
2024-08-29 More Fan Information (#21)
    * add standard fan table
    * removed duplicate tag
    * renamed file
    * renamed file
    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
2024-09-02 added standard fan specs
2024-09-02 added 10" stl
2024-09-12 rename enclosures
2024-09-18 Next update (#30)
    * added data sheet links to pages
    * added RP2040 page
    * updated getting started text
    * text updated
    * updated text
    * Added Images
    * text fixes
    * fixed annotation
    * added power text
    * bug fix
2024-09-20 Adding KIOXIA EXCERIA G2 and Juniper EX2200-48P-4G to the supported list (#31)
    * Add KIOXIA EXCERIA G2 to the supported ssds
    I've tested them a lot including running >24 hours of fio.
    They are working fine without errors for more than a year.
    * Add Juniper EX2200-48P-4G to the supported switches
    I'm running the beta blades for more than a year with this switch.
2024-10-11 SSD supported list update (#34)
    * Adding two Patriot models to supported list
    * Added Patriot P300 2TB - tested both Boot and Non-Boot on Dev Blade
    * Added Patriot P310 1920GB - tested both Boot and Non-Boot on Dev Blade
    All POE tested using the Ubiquity Pro 48 PoE
    * Update switch.md
    All Dev Blades POE tested using the Ubiquity Pro 48 PoE
    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
2024-11-13 added Blade and fan unit PCB models
    [Standard_v1.1.step, both.stl, latch.stl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]
2024-12-02 Fan unit instructions (#40)
    * upgrade docusaurus to v3.6.0
    * change default terminal path
    * version bumb
    * reorganize content
    * moved GPIO to index
    * cleaned text up
    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
2024-12-02 More fan unit info (#41)
    * added rp2040 GPIO
    * added information related to emc2101
2024-12-02 missing pin
2024-12-04 added ubiquitti switch in compatible list (#42)
    * added ubiquitti switch in compatible list
    * fixed typo
    * fixed typo2
    fixed name
    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
2024-12-09 Update uart.mdx (#43)
    Changed the word witch to which
2024-12-21 Updated 20241220 (#49)
    * Update ssd.md (#48)
    * Added two more PoE switches by Ubiquiti, tested with ComputeBlades. (#47)
    * Update uart.mdx
    Added two more tested and compatible units.
    * fixed setting
    * updated compatibility
    * version bump
    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
2025-02-03 Update switch.md (#60)
    Added verification for USW Lite 8 PoE and section on Brocade with ICX 6610. Both verified by me to work.
2025-05-15 Added step file BladeRunner 10”
    [10-inch_BladeRunner_(v5).step]
2025-05-15 replaced 4-node enclosure with latest step file
    [Full 4-node_(v4).step]
2025-05-16 added v3 of the stand, 2 parts
    [Back.stl, Front.stl]
2025-06-05 drive/switch compatibility additions
2025-06-17 Add Mikrotik models to switch compatibility
2025-07-23 Removed Uptime Industries
    [Standard_v1.1.step]
2025-07-24 Add USW Enterprise to the compatibility list of switches

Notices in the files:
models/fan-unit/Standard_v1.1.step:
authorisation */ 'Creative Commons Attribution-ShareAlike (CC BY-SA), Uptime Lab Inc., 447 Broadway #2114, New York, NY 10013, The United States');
